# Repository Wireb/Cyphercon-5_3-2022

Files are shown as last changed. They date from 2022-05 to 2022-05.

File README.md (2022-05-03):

# Cyphercon 5.3 2022 
This repo is a collection of files related to the Cyphercon 5.3 badge and support hardware. 
Peacock board files and data pulled out to make the lifetime badges a bit harder to forge. 

## KiCad
This is a KiCad 5.x project. 

## MplabX
This is a mplabX 5.35 project. All programming / debug was done with a PicKit4.

## FreeCAD
These are FreeCAD 0.19 

## Inkscape
Version 1.0.1 used

## Documentation

- Cyphercon 2020.xlsx - Master document used for badge development. BOMs, communication, game mech, flash layout, animation documentation
- FreeCAD/Start button-2022  Cad files related to the conference start button
- FreeCAD/tymkrs_Cyphercon_2022 Cad files related to the badge and vending machine 
   - bottle_button_support.FCStd - support structure for IR button used in the snake oil button 
   - button_case.FCStd - support structure for IR button used in the bee and bird seed bags
   - coyote_final.FCStd - screen alignment tool
   - coyote_stencil.FCStd - flocking stencil and blocks
   - flamingo_final.FCStd - screen alignment tool
   - flamingo_flock_blocks.FCStd - alignment blocks for badge on stencil machine 
   - flamingo_pgm_fixture.FCStd - programing fixture for flamingo badges
   - flamingo_stencil_2_tone_a.FCStd - flocking stencil
   - flamingo_stencil_V2.FCStd - flocking stencil
   - llama_final.FCStd - screen alignment tool
   - llama_stencil.FCStd - flocking stencil and blocks
   - Outhouse_socket.FCStd - socket for holding badge in outhouse
   - parrot_final.FCStd - screen alignment tool
   - parrot_stencil.FCStd - flocking stencil and blocks
   - peacock_final.FCStd - screen alignment tool
   - port_a_potty.FCStd - port-a-potty IR button housing 
   - Starfish.FCStd - starfish stencil for back of all the badges
   - Vendo_bracket.FCStd - support bracket for replacement processor board in the vending machine
   - Vendo_socket.FCStd - socket for badge on front of the vending machine 
   - wash_holders.FCStd - holder for running PCBs though flux remover in the ultrasonic cleaner
- inkscape - Intermediate files used to build up the stencils from the silk screen layers
- kicad 
   - tymkrs_Cyphercon_2020_Coyote - Coyote badge files
   - tymkrs_Cyphercon_2020_flamingo - Flamingo badge files
   - tymkrs_Cyphercon_2020_IRbutton - IR button files 
   - tymkrs_Cyphercon_2020_IRhack - IR hack and start button board (note start button was highly modified and mostly just used as a PIC chip holder.)
   - tymkrs_Cyphercon_2020_Llama - Llama badge files
   - tymkrs_Cyphercon_2020_Parrot - Parrot badge files 
   - tymkrs_vendo - Vendo processor replacement board (note "vendo.???" files are my schematics from reverse engineering the vending machine board) 
- mplab
    - Tymkrs_Cyphercon2020_IRblaster - Firmware for con start button
    - Tymkrs_Cyphercon2020_IRhack - Firmware for IRhack board 
    - Tymkrs_Cyphercon_2020_badge - Firmware for badges (one build supports all. Function defined by ID range) 
    - Tymkrs_Cyphercon_2020_IRbutton - Firmware for IR buttons and outhouses (Note there is a #ifdef to set outhouse vs IR button mode) 
- perl
   - Animation_build_list - flamingo.txt - build list to go with build_animations.pl script to generate animation_flamingo.bin
   - Animation_build_list_CPL.txt - build list to go with build_animations.pl script to generate animation_CPL.bin
   - Animation_build_list_peacock.txt - build list to go with animation_peacock.pl script to generate animation_flamingo.bin
   - animation_CPL.bin - output animation data file that should be written to the SPI eeprom on the badge for coyote, parrot, and llama
   - animation_flamingo.bin - output animation data file that should be written to the SPI eeprom on the badge
   - animation_peacock.bin - output animation data file that should be written to the SPI eeprom on the badge
   - build_animations.pl - this script takes in the animation frames in PNG format per the animation_build_list and generates the binary files to be written to the - eeprom
   - CPL_eyes - file folder of png files for coyote, parrot, and llama
   - cyphercon2020-pgm.pl - programing script for the PIC generate random key for crypto and takes user input for badge ID (badge type is determined by ID range. See documentation)
   - cyphercon2022.db - database dump from the vending machine 
   - Cyphercon_2020_test.pl - test utility to be use with a IR hack to gest the various badge communication functions
   - F_eyes - file folder of png files for flamingos
   - hbdh.png - Happy birthday Hyr0n (was going to be on his birthday in 2020... Happy belated bday Hyr0n) 
   - metroid.png - PNG used in base firmware to test the LCD when the SPI eeprom is not programed
   - P_eyes - file folder of png files for peacocks
   - Tymkrs_Cyphercon_2020_badge.X.production.hex - final released firmware (should be the same as the copy in the mplab directory... I hope) 
   - Tymkrs_Cyphercon_2020_keys.txt - Master list of keys used in the vending machine. Use the last one in the file when duplicates badge IDs are found. 
   - Vending_data.xlsx - Decoded dump in excel with some post processing to get some stats
   - Vendo_decode.pl - used to export the vending machine database to CSV files
   - Vendo_server.pl - Vending machine server script that did all the vending machine functions other that the monitor display
   - Vendo_test.pl - test script for the vending machine controller board

Copyright (c) 2019 - 2022 Peter Shabino

Permission is hereby granted, free of charge, to any person obtaining a copy of this hardware, software, and associated documentation files 
(the "Product"), to deal in the Product without restriction, including without limitation the rights to use, copy, modify, merge, publish, 
distribute, sublicense, and/or sell copies of the Product, and to permit persons to whom the Product is furnished to do so, subject to the 
following conditions:

The above copyright notice and this permission notice shall be included in all copies or substantial portions of the Product.

THE PRODUCT IS PROVIDED "AS IS", WITHOUT WARRANTY OF ANY KIND, EXPRESS OR IMPLIED, INCLUDING BUT NOT LIMITED TO THE WARRANTIES OF 
MERCHANTABILITY, FITNESS FOR A PARTICULAR PURPOSE AND NONINFRINGEMENT. IN NO EVENT SHALL THE AUTHORS OR COPYRIGHT HOLDERS BE LIABLE 
FOR ANY CLAIM, DAMAGES OR OTHER LIABILITY, WHETHER IN AN ACTION OF CONTRACT, TORT OR OTHERWISE, ARISING FROM, OUT OF OR IN CONNECTION 
WITH THE PRODUCT OR THE USE OR OTHER DEALINGS IN THE PRODUCT.

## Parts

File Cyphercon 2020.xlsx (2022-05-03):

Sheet: Whixr coms
 | Baud rate | 115200 8N1 |  | 0x0A | on end
Thing | Starting byte | Length | Ending byte | description
Header | 0 | 5 | 4 | Fixed header string "Disp:"
Plugged | 5 | 1 | 5 | 0x01 = plugged in and data valid, 0x00 = unplugged and following data will all be 0x00
Status | 6 | 1 | 6 | bit 0 = 1 con is started, bit 1 = 1 badge is sick (rest unused)
Command type | 7 | 1 | 7 | Will always be 0x02
Badge ID | 8 | 2 | 9 | ID of this badge <0x200 standard badge <0x240 speaker <0x280 Founder <0x2A0 Vendor <0x2C0 Outhouse (should not see this) <0x2E0 Snake oil (should not see this) <0x2FE Necrollamacon (should not see this) ==0x2FE start button (should not see this) ==0x2FF Vendo (should not see this)
Flags | 10 | 1 | 10 | bit 0 = 1 con start, bit 1 = 1 has pink eye, bit 2 = 1 is cured, bit 3 = 1 has egg, bit 4 1 = quest start, bit 5 1 = quest done, bit 6 = 1 uber on, bit 7 = 1 dead
Spent | 11 | 2 | 12 | number of credits already spent by the badge
Sick ID | 13 | 2 | 14 | ID of badge that got this badge sick (verify sick bit is on before use)
Egg ID | 15 | 2 | 16 | ID of badge that knocked this one up (verify badge is pregenet before use)
Button clicks | 17 | 3 | 19 | How may times they clicked the button
Sleep sec | 20 | 3 | 22 | How long this badge has been in the sleep state total
Active sec | 23 | 3 | 25 | How long this badge has been in the active state total
Hyper sec | 26 | 3 | 28 | How long this badge has been in the hyper state total
Prego sec | 29 | 3 | 31 | How long this badge has been pregenet total
Died | 32 | 2 | 33 | How many times this badge has died
Got food | 34 | 2 | 35 | How many times this badge has picked up food
Pooped | 36 | 2 | 37 | How many times this badge has pooped
Knocked up | 38 | 2 | 39 | How many times this badge has been knocked up
Quest ID | 40 | 2 | 41 | ID of llama badge that gave them the quest item
Interactions | 42 | 96 | 137 | Each bit repersents one badge ID. Bit is set when the badge recieves a flag from that badge. Raw credits are equal to the total number of 1s
Food level | 138 | 1 | 138 | Current food level of badge
Poop level | 139 | 1 | 139 | Current poop level of badge
Internal status | 140 | 2 | 141 | Low byte lower 2 bits are the current badge mode 0 = dead or precon (use dead bit in flag byte (10) over this one), 1 = sleeping, 2 = active, 3 = hyper. bit 3 = egg led, bit 4 = stomic led, Upper byte bit 2 = poop led. Rest of the bits are internal status bits
once | 142 | 2 | 143 | Used for crypto
footer | 144 | 1 | 144 | fixed to 0x0A
Back to vendo
Header | 0 | 6 | 5 | Fixed header "Vendo:"
Data | 6 | 1 | 6 | Set value to 0x01 to drop egg from current badge, Set value to 0x02 to send quest start to badge (make sure the badge is dead quest does not work on a living badge)
footer | 7 | 1 | 7 | fixed to 0x0A

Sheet: TODO list
 |  | Weeks left till Cyphercon | -3 |  | when | 2022-04-11 | days | -21
 |  |  |  |  | 16
item # | priority | What | Owner |  | requried time (weeks) | blocked by | actual start | actual end | notes / comments
3 | must | pack badges | Atdiy |  | In Progress
8 | must | play test and verify timers and animations | Atdiy
9 | must | Vendo GUI / Game | Whixr |  |  | 10
12a | Punt | Controls | Whixr
13 | Punt | LED controller for vendo | Wire
 | must | Solering iron and tools | Atdiy
4a | Done | Bird seed bag | Wire |  | 0 |  |  |  | build 5 | Bird seed bag
4e | Done | necrollamacon buttons | Wire |  | 0 |  |  |  | build 5 | Just needs the top lable on one box then done
5 | Done | Start IR blaster | Wire |  | 4
4f | Done | Beeeees!!! | Wire |  | 0 |  |  |  | build 5 | Bees
4c | Done | port-a-potty | Wire |  | 0 |  |  |  | build 5 | port-a-potty
16 | Done | Hack IR | Wire
17 | Done | Hack IR can stickers | Atdiy | 1 | DONE
21 | Done | Necrollamacon sticker | Atdiy | 1 | DONE |  |  |  | Need 1 more outline already done and will return with boxes
20 | Done | Bee boxes / stickers | Atdiy | 1 | DONE |  |  |  | Need 5
4b | Done | outhouse | Wire |  | 0 |  |  |  | build 5 | outhouse
1 | Done | Program badges | Wire |  | 6 | 8
2 | Done | validate in sleep | Wire |  | 1 | 1
4 | Done | setup buttons | Wire |  | 4
4d | Done | snake oil buttons | Wire |  | 0 |  |  |  | build 5 | snake oil buttons
7 | Done | Eye animations | Atdiy | 1 |  |  |  |  | Need image frames in .png format (see sample) and duration in to display each frame in 0.05s increments. (you can have the first 10 frams play ever 0.1s then have one frame stay up for 1s then 4 frames at 0.25s if you like
7a | Done | Precon idle | Atdiy | 1 |  |  |  |  | same as sleep
7b | Done | Precon button pressed | Atdiy | 1 |  |  |  |  | lazy eye back to sleep
7c | Done | hyper | Atdiy | 1
7d | Done | hyper sick | Atdiy | 1
7e | Done | normal | Atdiy | 1
7f | Done | normal sick | Atdiy | 1
7g | Done | sleep | Atdiy | 1 |  |  |  |  | sleep
7h | Done | sleep sick | Atdiy | 1
7i | Done | dead | Atdiy | 1
7j | Done | dead sick | Atdiy | 1
7k | Done | normal eye beam | Atdiy | 1 |  |  |  |  | When they click their button to send a flag
7l | Done | sick eye beam | Atdiy | 1
7m | Done | mine? | Atdiy | 1 |  |  |  |  | triggers on getting food or special packet
7n | Done | HBDH | Wire |  | 1
14 | Done | Test badge LEDs again | Atdiy | 1 |  | 2
18 | Done | Vending machine price sheet (see tab) | Atdiy | 1
19 | Done | Vending machine shelf tags | Atdiy | 1 |  |  |  |  | The little lables in front of each row with the number to punch in to dispence them. Note limited to digits on keypad minus the down arrow which will be used for dispense.
23 | Done | Test fit all items in vendo | Atdiy | 1 | DONE
10 | Done | split up vendo work and define interface | Whixr / Wire | 1
12 | Done | Vendo vinyl art | Whixr | 1 | DONE
12a | Done | Left side | Whixr | 1 | DONE
12a | Done | Right side | Whixr | 1 | DONE
12a | Done | Front side | Whixr | 1 | DONE
11 | Done | Vendo interface layer | Wire |  |  | 10
15 | Done | badge video | Atdiy / Whixr | 1 | In Progress
22 | Done | Demo video | Atdiy / Whixr | 1
24 | Done | Pack all vendo items into boxes | Atdiy | 1
 | Done | Badge repair parts packed | Atdiy | 1
6 | Done | start podium / suitcase | Wire
 | Done | Fix last bad badge | Wire
 | Done | Free box | Wire

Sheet: shopping list
badge |  | Vendo badge insert difference
Good Parrot | 21.5 | fits just perfect
coyote | 22.7 | 1.2
llama | 22.2 | 0.7
flamingo | 22.14 | 0.64
llama | 22.16 | 0.66
coyote | 22.25 | 0.75
flamingo | 22.15 | 0.65
flamingo | 21.98 | 0.48
parrot | 22.35 | 0.85
coyote | 22.41 | 0.91
llama | 22.2 | 0.7
coyote | 22.2 | 0.7
parrot | 22.26 | 0.76
flamingo | 22.05 | 0.55
llama | 22.16 | 0.66
flamingo | 22.52 | 1.02
 | average | 0.75
 | max | 1.2

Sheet: Vending price sheet
Item | Dispense code | Row wire color | Column wire color | Cost |  |  |  |  | 1 | 2 | 3 | 4 | 5 | 6 | 7 | 8 | 9
Red badge | 1337 |  |  | 65536 | NOTE!!!! |  |  |  | Books | Flamingo Straws | Stuffed Animals | Ambrosia
 |  |  |  |  | byte 0 row select (value NOT bit) |  |  | 1 | 50 | 10 | 50 | 65537
 |  |  |  |  |  | 0 | yellow wire row |  | 3 - 42 | 22 - 007 | 32 - 7446
 |  |  |  |  |  | 1 | white wire row |  | Lasered WI | Red Badge | Donated Badges | Donated Badges | Donated Badges
 |  |  |  |  |  | 2 | orange wire row | 2 | 10 | 65536 | 75 | 75 | 75
 |  |  |  |  |  | 3 | green wire row |  | 9 - 53203 | 33 - 1337 | 25 - 5912535152535 | 6 - 3119362364 | 1 - 998001
 |  |  |  |  |  | 4 | red wire row |  | SAO | Lasered WI | Kazoo | Games | Defcon PCBs | Game Bees | Rand Electronics
 |  |  |  |  |  | 5 | pink wire row | 3 | 50 | 10 | 10 | 20 | 75 | 100 | 30
 |  |  |  |  |  | 6 | brown wire row |  | 23 - AE35 | 8 - CHEE5E | 15 - CHE55 | 13 - 44556767103 | 2- ED209 | 12 - BEE5 | 5 - 5558632
 |  |  |  |  |  | 7 | black wire row |  | The Cure | Bird Seed | IR Hack | Kazoo | IR Hack | Kazoo | Rubber Duckies | Balls | PCB Bits
 |  |  |  |  |  |  |  | 4 | 100 | 100 | 75 | 10 | 75 | 10 | 30 | 50 | 25
 |  |  |  |  | byte 1 column select (value NOT bit) |  |  |  | 11 - 8675309 | 14 - DEAD BEEF | 20 - C2 | 19 - 9 | 16 - 127001 | 18 - 1 | 27 - 4152739164 | 31 - 101 | 17 - 3125550690
 |  |  |  |  |  | 0 | red wire column |  | Challenge coins | Scissors | Scissors | Kazoo | Phone Badges | Kazoo | Toilet | Scissors | Necrollamacon
 |  |  |  |  |  | 1 | gray wire column | 5 | 75 | 30 | 30 | 10 | 75 | 10 | 100 | 30 | 200
 |  |  |  |  |  | 2 | green wire column |  | 4 - 2125554240 | 29 - 2375345200 | 10 - 2 | 7- 5663 | 21-2600 | 28 - 80 | 26-75 | 24 - 6387 | 30 - 47688283
 |  |  |  |  |  | 3 | orange wire column
 |  |  |  |  |  | 4 | pink wire column |  |  | Questions: |  |  |  |  | Answer: | cost: | Row | column |  |  | https://cybersecurityventures.com/movies-about-cybersecurity-and-hacking/
 |  |  |  |  |  | 5 | yellow wire column |  | 1 | 1 divided by _____ gives all 3 digit numbers from 000 to 999 except for 998? |  |  |  |  | 998001 | 75 | 2 | 5 | 1 | 4
 |  |  |  |  |  | 6 | brown wire column |  | 2 | Think you better do what he says Mr. Kinney |  |  |  |  | ED209 | 75 | 3 | 5 | 2 | 4
 |  |  |  |  |  | 7 | white wire column |  | 3 | What's the meaning of life? |  |  |  |  | 42 | 50 | 1 | 1 | 0 | 0
 |  |  |  |  |  | 8 | blue wire column |  | 4 | CrashOverride: Hey Norm, can you read the number on the modem? |  |  |  |  | 2125554240 | 75 | 5 | 1 | 4 | 0
 |  |  |  |  |  | 9 | black wire column |  | 5 | What's the number for Protovision? |  |  |  |  | 5558632 | 30 | 3 | 7 | 2 | 6
 |  |  |  |  |  |  |  |  | 6 | # to WOPR (w/area code) |  |  |  |  | 3119362364 | 75 | 2 | 4 | 1 | 3
 |  |  |  |  | Notes on credits: |  |  |  | 7 | Calculator speak for EGGS |  |  |  |  | 5663 | 10 | 5 | 4 | 4 | 3
 |  |  |  |  |  | All badges start with 1 credit for seeing themselves. |  |  | 8 | What's yellow and Wisconsin-y |  |  |  |  | CHEE5E | 10 | 3 | 2 | 2 | 1
 |  |  |  |  |  | Natural max (badges we built) = 592 (verify with atdiy and final count) |  |  | 9 | What zip code are we in |  |  |  |  | 53203 | 10 | 2 | 1 | 1 | 0
 |  |  |  |  |  |  |  |  | 10 | Birds of a feather flock _gether |  |  |  |  | 2 | 30 | 5 | 3 | 4 | 2
 |  |  |  |  |  | Max credits if badges are spoofed (easy hack) = 768 |  |  | 11 | Jenny's Number |  |  |  |  | 8675309 | 100 | 4 | 1 | 3 | 0
 |  |  |  |  |  | Max credits if credit handshake (crypto) is broken (hard hack red badge?) = 65536 (0xFFFF) |  |  | 12 | What are these? |  |  |  |  | BEE5 | 100 | 3 | 6 | 2 | 5
 |  |  |  |  |  |  |  |  | 13 | Konami Code |  |  |  |  | 44556767103 | 20 | 3 | 4 | 2 | 3
 |  |  |  |  |  |  |  |  | 14 | FEED B0B0 ____ ____ |  |  |  |  | DEAD BEEF | 100 | 4 | 2 | 3 | 1
 |  |  |  |  |  |  |  |  | 15 | Would you like to play a game of ______ |  |  |  |  | CHE55 | 10 | 3 | 3 | 2 | 2
 |  |  |  |  |  |  |  |  | 16 | What IP should you hack to shut down your computer? |  |  |  |  | 127001 | 75 | 4 | 5 | 3 | 4
 |  |  |  |  |  |  |  |  | 17 | What number does Trinity call from? |  |  |  |  | 3125550690 | 25 | 4 | 9 | 3 | 8
 |  |  |  |  |  |  |  |  | 18 | 6 ÷ 2(1+2) |  |  |  |  | 1 | 10 | 4 | 6 | 3 | 5
 |  |  |  |  |  |  |  |  | 19 | 6 ÷ 2(1+2) |  |  |  |  | 9 | 10 | 4 | 4 | 3 | 3
 |  |  |  |  |  |  |  |  | 20 | Control and Command |  |  |  |  | C2 | 75 | 4 | 3 | 3 | 2 | https://www.youtube.com/watch?v=6BqpU4V0Ypk
 |  |  |  |  |  |  |  |  | 21 | The audio tone used in phreaking |  |  |  |  | 2600 | 75 | 5 | 5 | 4 | 4
 |  |  |  |  |  |  |  |  | 22 | Who likes it shaken, not stirred |  |  |  |  | 007 | 10 | 1 | 2 | 0 | 1
 |  |  |  |  |  |  |  |  | 23 | What unit did HAL9000 lie about and say was malfunctioning |  |  |  |  | AE35 | 50 | 3 | 1 | 2 | 0
 |  |  |  |  |  |  |  |  | 24 | Colossus detonated missiles at which silos? |  |  |  |  | 6387 | 30 | 5 | 8 | 4 | 7 | https://tvtropes.org/pmwiki/pmwiki.php/Quotes/ColossusTheForbinProject
 |  |  |  |  |  |  |  |  | 25 | What number did Bob's twinkie hit to get into Terminal Entry |  |  |  |  | 5912535152535 | 75 | 2 | 3 | 1 | 2
 |  |  |  |  |  |  |  |  | 26 | Clifford Stoll discovered a how many cent discrepancy which tipped him off? |  |  |  |  | 75 | 100 | 5 | 7 | 4 | 6
 |  |  |  |  |  |  |  |  | 27 | What's NSA Agent Mary's number? |  |  |  |  | 4152739164 | 30 | 4 | 7 | 3 | 6 | https://en.wikiquote.org/wiki/Sneakers_(1992_film)
 |  |  |  |  |  |  |  |  | 28 | How many gigs of data can Johnny Mnemonic carry in his head? |  |  |  |  | 80 | 10 | 5 | 6 | 4 | 5
 |  |  |  |  |  |  |  |  | 29 | What's Jeff Gregg's IP address |  |  |  |  | 2375345200 | 30 | 5 | 2 | 4 | 1 | https://www.youtube.com/watch?v=46qKHq7REI4
 |  |  |  |  |  |  |  |  | 30 | What's the file number for Undersecretary of Defense - Michael Bergstrom |  |  |  |  | 47688283 | 200 | 5 | 9 | 4 | 8
 |  |  |  |  |  |  |  |  | 31 | What is Neo's apt number? |  |  |  |  | 101 | 50 | 4 | 8 | 3 | 7
 |  |  |  |  |  |  |  |  | 32 | How many rivers and streams does Wisconsin have? |  |  |  |  | 7446 | 50 | 1 | 3 | 0 | 2
 |  |  |  |  |  |  |  |  | 33 | Guess |  |  |  |  | 1337 | 65536 | 2 | 2 | 1 | 1
 |  |  |  |  |  |  |  |  | 34 | flamingo |  |  |  |  | A310D8D410
 |  |  |  |  |  |  |  |  | 35 | coyote |  |  |  |  | U4A102BC10E
 |  |  |  |  |  |  |  |  | 36 | llama |  |  |  |  | A473D10D1C
 |  |  |  |  |  |  |  |  | 37 | Parrot |  |  |  |  | 1086710A20U
 |  |  |  |  |  |  |  |  | 38 | Peacock |  |  |  |  | 101234CDEF

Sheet: Awards
Name | What
Kenny | most deaths
Fidget spinner | most button presses while not dead

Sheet: Rework status
Badge | Total need | in process | good | bad | missing | Fallout % | % have | % done | Cleaned | % done | Short
Parrot | 45 | 0 | 46 | 0 | 0 | 0.0% | 102.2% | 102.2% | 0 | 0.0% | 0
Llamma | 20 | 0 | 21 | 0 | 0 | 0.0% | 105.0% | 105.0% | 0 | 0.0% | 0
Peacock | 10 | 0 | 11 | 0 | 0 | 0.0% | 110.0% | 110.0% | 0 | 0.0% | 0
coyote | 15 | 0 | 16 | 0 | 0 | 0.0% | 106.7% | 106.7% | 0 | 0.0% | 0 |  |  |  |  | 462 | 11 | 21 | 46 | 16
Flamingo | 460 | 0 | 462 | 0 | 0 | 0.0% | 100.4% | 100.4% | 0 | 0.0% | 0 |  |  |  |  | F | pea | l | par | c
 |  |  |  |  |  |  |  |  |  |  |  |  |  | 7.75 | long | 7.75 | 7.75 | 7.75 | 7.75 | 7.75
Total | 550 | 0 | 556 | 0 | 0 | 0.0% | 101.1% | 101.1% | 0 | 0.0% |  |  |  | 3.5 | wide | 3.25 | 4 | 3.25 | 3.5 | 3.5
 |  |  |  |  |  |  |  |  |  |  |  |  |  | 1.25 | tall for 2
 |  |  |  |  |  |  |  |  |  |  |  |  |  |  |  |  | total storage | overage | ends
2022-05-02 | 2022-04-01 | -31 | -4.428571429 | weeks left |  |  |  |  |  |  |  |  |  | 14.75 | L | 1 | 7.75 | 7 | 3.5
 |  |  |  |  |  |  |  |  | 0 | -160 |  |  |  | 9.25 | W | 2 | 7 | 2.25 | 1.125
 |  |  |  |  |  |  |  |  | 40 |  |  |  |  | 6 | T | 8
Process steps |  |  |  |  |  |  |  |  | 451 |  |  |  |  |  |  | 16
1 | assembly -LCD |  |  | 101.1% |  |  |  |  | 450
2 | LED drv |  |  | 101.1% |  | Total |  | Flamingo 2 | Flamingo | Parrot | Llamma | Peacock | coyote | 9.25 | L | 1 | 7.75 | 1.5 | 0.75
3 | LED test |  |  | 101.1% |  | 556 | 135 | 135 | 192 | 46 | 21 | 11 | 16 | 14.75 | W | 4 | 14 | 0.75 | 0.375
4 | clean |  |  | 101.1% |  | 556 | 200 | 262 |  | 46 | 21 | 11 | 16 | 6 | T | 8
5 | flock |  |  | 101.1% |  | 556 |  | 51 | 411 | 46 | 21 | 11 | 16 |  |  | 32
6 | LCD assembly+test |  |  | 101.1% |  | 556 |  | 51 | 411 | 46 | 21 | 11 | 16
7 | lower LEDS |  |  | 101.1% |  | 556 |  | 51 | 411 | 46 | 21 | 11 | 16
8 | Battery holders |  |  | 100.0% |  | 550 |  | 50 | 410 | 45 | 20 | 10 | 15
9 | Final programing |  |  | 0.0% |  | 0 |  |  |  |  |  |  |  |  |  | 478 | 16
10 | Test IR and verify in deep sleep and pack |  |  | 0.0% |  | 0 |  |  |  |  |  |  |  | Box | badge | how many
 |  |  |  | 80.8% | Overall completion |  |  |  |  |  |  |  |  | 1 | Flamingo | 70 | 17.5 | 9.75 | 8.75
 |  |  |  |  |  |  |  |  |  |  |  |  |  | 2 | Flamingo | 96 | 18.75 | 12.5 | 11
 |  |  |  |  |  |  |  |  |  |  |  |  |  | 3 | Flamingo | 160 | 20.5 | 13 | 12.75
 |  |  |  |  |  |  |  |  |  |  |  |  |  | 4 | Flamingo | 72 | 18 | 10 | 8.5
 |  |  |  |  |  |  |  |  |  |  |  |  |  | 5 | Flamingo | 80 | 14 | 13 | 12.75
 | Shopping list: |  |  |  |  |  |  |  |  |  |  |  |  | 6 | Llama | 21 | 11.75 | 9.25 | 6
 |  |  |  |  |  |  |  |  |  |  |  |  |  | 7 | Peacock | 11 | 11 | 6.25 | 8.25
10 | pogo pins |  |  |  |  |  |  |  |  |  |  |  |  | 8 | Coyote | 16 | 14.75 | 9.25 | 4
 |  |  |  |  |  |  |  |  |  |  |  |  |  | 9 | Parrot | 46 | 15.75 | 11.75 | 5
 |  |  |  |  |  |  |  |  |  |  |  |  |  |  |  |  |  |  |  |  | pass 1 | pass 2 | pass 3 | pass 4
 |  |  |  |  |  |  |  |  |  |  |  |  |  |  | Flamingo | 2 | 411 | 822 |  | 822 | 411 | 411 | 0 | 0
 |  |  |  |  |  |  |  |  |  |  |  |  |  |  | Flamingo 2 | 3 | 51 | 153 |  | 153 | 51 | 51 | 51 | 0
 |  |  |  |  |  |  |  |  |  |  |  |  |  |  | Llama | 3 | 21 | 63 |  | 63 | 21 | 21 | 21 | 0
 |  |  |  |  |  |  |  |  |  |  |  |  |  |  | Peacock | 4 | 11 | 44 |  | 44 | 11 | 11 | 11 | 11
 |  |  |  |  |  |  |  |  |  |  |  |  |  |  | coyote | 2 | 16 | 32 |  | 32 | 16 | 16 | 0 | 0
 |  |  |  |  |  |  |  |  |  |  |  |  |  |  | Parrot | 3 | 46 | 138 |  | 138 | 46 | 46 | 46 | 0
 |  |  |  |  |  |  |  |  |  |  |  |  |  |  |  |  | 556 | 1252 |  | 1252

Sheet: Ideas
arts n crafts
Fuzzy Flocking
Stickers
Piper cleaners
Paper doll parts
Electronics
Pink Leds (see Kupo!)
Led array eye
Led wing outline
screen / led array for crafting
Puzzle / game
General Idea
 | tamagotchi
 |  | Drive trafic to villages and vendors
 |  | More details to com
 | Start podium
 |  | Badges do something lame (blinking led for a eye) until started.
 |  | Start podium has blinky lights and things and a giant button.
 |  | When button is pressed leds go crazzy and sends out IR becon via IR floodlight to all badges in the room to start.
 |  | Badges go into normal mode and can spread the start signal to other badges.
Village boxes
 | Each village box gives a limited number of usefull (maybe) items
 | Each village has a box that generates a unique resouce on a given tick (~5s)
 | Display on box shows how many resouces in stock and has a max cap of 5?
 | User can insert badge and press button to collect one resource per press if badge cap is not full. (bidi coms)
Vendor boxes (backup for vendor overload)
 | Each vendor has a box that generates a food resouce on a given tick (~5s)
 | Display on box shows how many resouces in stock and has a max cap of 5?
 | User can insert badge and press button to collect one resource per press if badge cap is not full. (bidi coms)
Vendor badges
 | Similar to the boxes gives food resouces to those near by.
 | No tick limit
 | Badge remberst the last X badges it got food from and will not accept handouts from them anymore
Guild hall
 | The main purpose of this box is to collect the interaction data and scores of each badge.
 | Also allows the badge user to update their handle in the scoring system (vs snarky autogenerated name based off ID)
 | Badge upgrades and stat display
 | Doctor game
Badge
 | Interact button to send greatings to other badges (give social) and interact with boxes
 | Eye / mouth animations. Main method to inform the user of the status of their bird.
 | Wing leds show rank / health (streach)
80s hacker movies
chamber from the fly
Shaw of the dead
hackers vs deadites
80s movie tropes
Michael Jackson thriller
hyron's bday
where's kevin
laser tag wands
Bees - turkey baster |  | Enroute | 5 |  | 12 bees | in house
Portapotty - Normal |  | Will make | 5 |  | Popsicle sticks | in house
Portapotty - Vending |  | Will make | 5
Seed bag |  | Will make - burlap enroute | 5 |  |  | in house
Miracle Oil |  |  | 5 |  | tins | in house
IR Hack |  |  | 12 | https://www.amazon.com/Stocking-Stuffers-Chocolate-Valentines-Anniversary/dp/B07BJWC3VX | tins | not sure if i can make 21 but made 7 labels | in house
 |  |  |  |  | Elecrow | OSH Park | TRC Circuits | Royal Circuits | AAPCB
 |  |  | Flamingo | 475 | 980.98 | 8356 | 2997 | 7990 | 5992
 |  |  | Parrot | 45 | 188.42 | 792 | 795 | 1299 | 1284
 |  |  | Llama | 25 | 127.08 | 246 | 525 | 1799 | 1270
 |  |  | Coyote | 15 | 73.59 | 436 | 550 | 1299 | 872
 |  |  | Peacock | 15 | 61.77 | 246 | 500 | 1299 | 913
 |  |  |  |  | 1431.84 | 10076 | 5367 | 13686 | 10331
 |  |  |  | 575 |  | 4717
 |  |  |  |  |  | 300
 |  |  |  |  |  | 1720

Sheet: Art
Badge | Animal | Art direction
Human | Flamingo Pink | Hackery / paper dress up doll
Uber | Flamingo Purple? Two tone? | Hackery / paper dress up doll | Purple | (VIP buys before Nov1 and Vendors) - hard to determine badge counts for vendors...can we add a SAO of some sort?
Founder | Llama / wolf in Llama cloathing | Keeper of the Necrollamacon (brings back the dead) | Black
Vendor | Coyote | Gives out free bird seed.
Speaker | Parrot | Umm talking social pariot
Red | Peacock | Extra fancy and fragile (Real peacock feathers?)

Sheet: Requirements
Category | Item | Units | Ask
Logistics | QTY | #
Logistics | Assembly | in house/FAB
Logistics | Programing | in house/FAB
date | conferance date | date
date | final ship | date
date | assembly start | date
Communications | RF - WiFi | y/n | n
Communications | RF - Bluetooth | y/n | n
Communications | RF - Other | y/n | n
Communications | IRDA | y/n | n
Communications | IR - simple | y/n | Y
Communications | UART | y/n | n
Communications | I2C | y/n | Y
Communications | SPI | y/n | n
Communications | USB device | y/n | n
Communications | PSTN modem | y/n | n
Power | LiPo (?Ah @ ?mA) | y/n | n
Power | AA (2.4Ah @ 50mA) | # | 2
Power | AAA (1Ah @ 10mA) | # | n
Power | CR2450 (0.62Ah @ 0.39mA) | # | n
Power | Reg | y/n
Display | 7seg LED | # digits | 0
Display | oLED | y/n | n
Display | LCD | y/n | y
Display | ePaper | y/n | n
Display | RGB LEDs | # RGB leds | 0
Display | LEDs | # leds | 48 | min
Display | LED strip | y/n | n
Input devices | buttons | # | 2 or 3
Input devices | switches | # | 0
Input devices | cap sense | # | 1 | petting flamingo
Input devices | Microphone | y/n | n
Input devices | Rotarty encoder | # | 0
Input devices | Pulse | y/n | n
Input devices | jiggle | y/n | n
Input devices | tempature | y/n | n
Output devices | Speaker | y/n | n
Output devices | Buzzer | y/n | n
Processing | FPGA | y/n | n
Processing | PIC | y/n | y
Storage | eeprom I2C | bytes | 128kb (16kB)
Storage | SDcard | y/n | n

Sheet: Game mechanics
Stat counters
 | Too low | low value | Too high | high value | Decay mech | Decay tick rate |  | Effect in Flamingo
food | death | 0 | fat | 20 | time | 1/min |  | Stomach shows from full up to empty
sleep | forced sleep | 0 | hyper | 20 | time | 1/min |  | Eyes go from open and alert to sleepy, maybe zzz?
health | sick (local) | 0 | vegan
social | binge eater | 0 | patient zero | very large
booze | basement dweller |  | drunk, binge drinker |  | time |  | 2 counters time and total number?, tristate for drunk state
shit | prolapse |  | got2go |  |  | -1/min | Food rate feeds this counter
Status effects
 | how fixed | impact | description
death | Necrollamacon | Unable to interact / reset score? | You have died only way to exit this state is to retrieve a copy of the Necrollamacon from a founder (or hidden beacon?). Consumed on use. Possibly kill player if in inventory when not dead or affect social?
fat | time | Decrease health | You have been a pig and eaten too much. You feel slugish and not all that well.
forced sleep | time | Unable to interact no social, food, booze, shit | Your so tired you can't even open your eyes. (Real world xx minutes to reset. If power cycled during sleep timer resets to full delay cheat protect)
hyper | time | faster food decay | Your bouncing off the walls.
sick | station (game) + meds | lower social pickup | You feel like shit and want to be alone.
vegan | decrease health | process booze faster
binge eater | social | faster food decay + faster shits | You feel so alone and your only friend is the fridge.
patient zero | station (game) + meds | you spread concrud -health to all who see your beacon | Your so sick you can barely stand but you still want to see the talks. (Curing this also resets all your interactions...)
basement dweller |  | sleep rate up
binge drinker | none | death | Looks like you pickled yourself this time
prolapse |  | sleep recovery down
got2go |  | No social counts, override sleep | Your doing the pinguin walk and just hoping it does not roll down your pant leg.
drunk | time | Social to 50% and frozen | You no longer care and just want to party.
Zombies! | Zombie repelent / avoid the dead | health down? | Your scared so many undead.
Items
 | from
coffie | box / tips? | boosts sleep value
Chill room | Chill room | Freezes all in game counters and badge goes into chill mode for x minutes
booze | box / tips? | get's you drunk
bird seed | Vendors | adds to food level
Necrollamacon | founders | brings you back from the dead
Zombie repelent | boxes | immuen to zombie effects for x min
Meds | boxes | Cures sickness / concrud
Toilet | boxes? | poop down

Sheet: Game Mech V2
Stat | Min | Max |  | Normal Increase | Rate | Normal Decrease | Rate | At Min | At max | Min Effects | Max Effects
food | 0 | 255 - shit |  | Vendor | Fill to max | Time | 1/min | death | no effect | Can't Nothing so they can do everything? | Can't Eat
shit | 0 | 255 |  | Food decrease | 1 per food - | Toilet | empty | no effect | no effect |  | Can't Eat; Can't Social
heart rate | 0 | 255 |  | Meeting Others | 1/person | Time no pings | -1 per 5 min? | sleeps until next ping | no effect |  | Can't Eat; Can't Social
 | Eye Status | Heart Light (2 bit) | Stomach Light (1 bit) | Poo Light (1 bit) | Egg Light (1 bit)
food = 0 | XX |  | On |  | On if On

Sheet: Game Mech V3
Game counters
stat | value min | value max | increase function | inc amount | inc dead | decrease function | dec amount fixed | sleep | active | hyper | dec dead | LED effects | LED when / L0 | LED L1 | LED L2 | LED L3 | save in eeprom | save source | Init value | start conditon | back from dead | notes
Egg | 0 | 1 | speaker badge | 1 | no | Vending machine | 1 | N/A | N/A | N/A | yes | egg on | 1 | N/A | N/A | N/A | yes | yes | eeprom | 0 | last
food | 0 | 255 - poo | vendor / seed bag | set to 255 - poo | no | heart rate / pink eye | var | 0 / 0 |  |  | no | stomic blink | 51 | N/A | N/A | N/A | no | no |  | 255 | 255
poo | 0 | 255 | food consumed | 1 | no | outhouse | set to 0 | N/A | N/A | N/A | no | poo blink | 204 | N/A | N/A | N/A | no | no |  | 0 | 0
heart | 0 | 3 | button press | set to 3 | no | time | var | 0 |  |  | no | heart blink | off | slow blink | medium blink | fast blink | yes | no | dead or sleep | 1 | 1 (sleep)
pink eye | 0 | 1 | 50 social or sick flag | 1 | no | snake oil | 1 | N/A | N/A | N/A | no | animation update | N/A | N/A | N/A | N/A | yes | yes | eeprom | 0 | last | can only catch onec
Heart 3 to 1 | 15 | min |  | 45 |  | 40 | 0.1568627451 | 255 | 6.375 | 95.625 | 1.59375 |  | 8.5 | 5.333333333
Heart 3 to 2 | 5 | min | 4 | food per |  | 26.66666667 |  | 255 | 9.5625 | 47.8125 | 0.796875
Heart 2 to 1 | 10 | min | 1 | food per |  | 13.33333333 |  | 255 | 19.125 | 191.25
With Pink Eye
Heart 3 to 1 | 15 | min |  | 45 |  | 66.66666667 | 0.2614379085 | 255 | 3.825 | 57.375 | 0.95625
Heart 3 to 2 | 5 | min | 6 | food per |  | 40 |  | 255 | 6.375 | 31.875 | 0.53125
Heart 2 to 1 | 10 | min | 2 | food per |  | 26.66666667
 |  |  |  |  |  |  |  |  |  | hyper end
pink leds
state | animation | on at once | update speed
normal | lfsr | 1 | nominal
uber | lfsr | 1 | fast
change modes via command packet
 | Vending machine (complete quests)
 | IRHack
Logo LEDs
channel | slave together | Normal |  |  | On quest | Quest done
amber | y | triangle |  |  | off | off
red | y | triangle skipping some on way down |  |  | triangle in sync | off
green | y | triangle skipping some on way down |  |  | triangle in sync | pulse
blue | y | triangle skipping some on way down |  |  | triangle in sync | off
Badge exceptions
Vendor | inf food
Founder | inf food
Peacock | inf food
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

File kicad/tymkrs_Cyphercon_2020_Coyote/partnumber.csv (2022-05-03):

Q | part number | footprint | ref_des
1 | 0.1uF 16V X7R | Capacitor_SMD:C_0603_1608Metric | C9
1 | 0.1uF 6.3V X5R | Capacitor_SMD:C_0603_1608Metric | C8
4 | 0.1uF | Capacitor_SMD:C_0603_1608Metric | C13 C14 C16 C18
1 | 0.42_oLED_display | PJS_smt_parts:oLED_0.42_rev | oLED1
3 | 100k | Resistor_SMD:R_0603_1608Metric | R2 R6 R3
2 | 10k | Resistor_SMD:R_0603_1608Metric | R9 R8
3 | 10uF | Capacitor_SMD:C_1206_3216Metric | C12 C15 C17
1 | 1k | Resistor_SMD:R_0603_1608Metric | R4
2 | 1uF 16V | Capacitor_SMD:C_0805_2012Metric | C11 C10
1 | 2.2uF 16V 0805 | Capacitor_SMD:C_0805_2012Metric | C5
1 | 2.2uH 1.6A 0805 | Inductor_SMD:L_0805_2012Metric | L1
2 | 22uF 10V | Capacitor_SMD:C_0603_1608Metric | C3 C2
2 | 24.9K | Resistor_SMD:R_0603_1608Metric | R10 R11
1 | 25LCxxx | Package_SO:SOIC-8_5.275x5.275mm_P1.27mm | U3
1 | 27 (0805) | Resistor_SMD:R_0603_1608Metric | R7
3 | 4.7uF 16V 0805 | Capacitor_SMD:C_0805_2012Metric | C6 C7 C4
6 | Amber | SunLED:XZ__K45WT-9 | D5 D23 D39 D44 D57 D58
1 | Common LED guide | tymkrs:cypheron2020_common_logo_led_guide | icon3
1 | Common Logo copper | tymkrs:cypheron2020_common_logo_copper_add | icon5
1 | Common Logo keepout | tymkrs:cypheron2020_common_logo_copper_flood_keepout | icon4
1 | Common Logo soldermask | tymkrs:cypheron2020_common_logo_soldermask | icon2
1 | Cut lines | tymkrs:cypheron2020_coyote_cuts | icon6
1 | Eye location | tymkrs:cypheron2020_coyote_eye | icon11
1 | IR26-21C (1206) | LED_SMD:LED_1206_3216Metric | D2
2 | IS31FL3236_TQFP | Package_QFP:TQFP-48-1EP_7x7mm_P0.5mm_EP3.5x3.5mm | U5 U6
1 | Icon keepout | tymkrs:cypheron2020_coyote_icons_copperkeepout | icon7
1 | Icon soldermask | tymkrs:cypheron2020_coyote_icons_soldermask | icon8
1 | Keystone 2462 | PJS-pth-parts:Keystone_2462_2x_AA_no_holes | BT1
1 | LED guide | tymkrs:cypheron2020_coyote_led_guide | icon9
5 | LED_RABG | SunLED:XZMDKCBDDG45S-9 | D7 D12 D17 D28 D33
1 | Metroid | PJS-icons:metroid | icon1
1 | PIC16F15345 | Package_SO:SOIC-20W_7.5x12.8mm_P1.27mm | U1
1 | PicKit | Connector_PinHeader_2.54mm:PinHeader_1x05_P2.54mm_Vertical | J1
47 | Pink_0603 | LED_SMD:LED_0603_1608Metric | D4 D48 D50 D52 D53 D54 D55 D56 D10 D11 D13 D14 D15 D16 D18 D19 D20 D21 D22 D24 D25 D26 D27 D29 D30 D31 D32 D34 D35 D36 D37 D38 D40 D41 D42 D43 D45 D46 D47 D49 D51 D59 D60 D62 D63 D64 D61
3 | Red_rev | SunLED:XZ__K45WT-9 | D9 D8 D6
1 | SPI | Connector_PinHeader_2.54mm:PinHeader_1x06_P2.54mm_Vertical | J2
1 | Silk | tymkrs:cypheron2020_coyote_silk | icon10
1 | TACT_6MM | PJS_smt_parts:PTS645_6mm_tact_sw | SW1
1 | TPS61322x | Package_TO_SOT_SMD:SOT-23-5 | U2
1 | TSOP58438 | Vishay:TSOP48 | U4
1 | White IN-S63AT5UW | LED_SMD:LED_0603_1608Metric | D3
0 | no-pop | Diode_SMD:D_SMA | D1
0 | no_pop | Capacitor_SMD:C_0603_1608Metric | C1
0 | no_pop | Resistor_SMD:R_0603_1608Metric | R1 R5

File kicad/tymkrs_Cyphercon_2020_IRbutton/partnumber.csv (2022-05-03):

Q | part number | footprint | ref_des
1 | 0.1uF 0603 | Capacitor_SMD:C_0603_1608Metric | C2
1 | 100k | Resistor_SMD:R_0603_1608Metric | R1
1 | 10uF 1206 | Capacitor_SMD:C_1206_3216Metric | C1
1 | 27 0805 | Resistor_SMD:R_0603_1608Metric | R3
1 | 2k | Resistor_SMD:R_0603_1608Metric | R2
1 | BAT-HLD-001 | PJS_smt_parts:BAT-HLD-001 | BT1
1 | IR204 | LED_THT:LED_D3.0mm_Horizontal_O1.27mm_Z2.0mm_Clear | D2
1 | Metroid | PJS-icons:metroid | icon1
1 | MountingHole | MountingHole:MountingHole_2.7mm_M2.5 | H1
1 | PIC16F15313 | Package_SO:SOIC-8_3.9x4.9mm_P1.27mm | U1
1 | PicKit | Connector_PinHeader_2.54mm:PinHeader_1x05_P2.54mm_Vertical | J1
1 | Red | LED_SMD:LED_0603_1608Metric | D1
1 | TACT_6MM | PJS_smt_parts:PTS645_6mm_tact_sw | SW1

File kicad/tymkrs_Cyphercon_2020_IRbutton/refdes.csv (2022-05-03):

ref_des | part number | footprint
BT1 | BAT-HLD-001 | PJS_smt_parts:BAT-HLD-001
C1 | 10uF 1206 | Capacitor_SMD:C_1206_3216Metric
C2 | 0.1uF 0603 | Capacitor_SMD:C_0603_1608Metric
D1 | Red | LED_SMD:LED_0603_1608Metric
D2 | IR204 | LED_THT:LED_D3.0mm_Horizontal_O1.27mm_Z2.0mm_Clear
H1 | MountingHole | MountingHole:MountingHole_2.7mm_M2.5
J1 | PicKit | Connector_PinHeader_2.54mm:PinHeader_1x05_P2.54mm_Vertical
R1 | 100k | Resistor_SMD:R_0603_1608Metric
R2 | 2k | Resistor_SMD:R_0603_1608Metric
R3 | 27 0805 | Resistor_SMD:R_0603_1608Metric
SW1 | TACT_6MM | PJS_smt_parts:PTS645_6mm_tact_sw
U1 | PIC16F15313 | Package_SO:SOIC-8_3.9x4.9mm_P1.27mm
icon1 | Metroid | PJS-icons:metroid

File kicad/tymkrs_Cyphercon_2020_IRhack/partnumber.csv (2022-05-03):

Q | part number | footprint | ref_des
2 | 0.1uF 0603 | Capacitor_SMD:C_0603_1608Metric | C3 C4
1 | 100k | Resistor_SMD:R_0603_1608Metric | R5
1 | 10k | Resistor_SMD:R_0603_1608Metric | R1
2 | 10uF 1206 | Capacitor_SMD:C_1206_3216Metric | C1 C2
1 | 27 0805 | Resistor_SMD:R_0603_1608Metric | R4
2 | 2k | Resistor_SMD:R_0603_1608Metric | R2 R3
1 | Green | LED_SMD:LED_0603_1608Metric | D2
1 | IO | Connector_PinHeader_2.54mm:PinHeader_1x04_P2.54mm_Horizontal | J2
1 | IR204 | LED_THT:LED_D3.0mm_Horizontal_O1.27mm_Z2.0mm_Clear | D3
1 | Metroid | PJS-icons:metroid | icon1
1 | PIC16F15324 | Package_SO:SOIC-14_3.9x8.7mm_P1.27mm | U1
1 | PicKit | Connector_PinHeader_2.54mm:PinHeader_1x05_P2.54mm_Vertical | J1
1 | Red | LED_SMD:LED_0603_1608Metric | D1
1 | TSOP58438 | Vishay:TSOP48 | U2

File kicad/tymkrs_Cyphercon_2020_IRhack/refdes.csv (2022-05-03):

ref_des | part number | footprint
C1 | 10uF 1206 | Capacitor_SMD:C_1206_3216Metric
C2 | 10uF 1206 | Capacitor_SMD:C_1206_3216Metric
C3 | 0.1uF 0603 | Capacitor_SMD:C_0603_1608Metric
C4 | 0.1uF 0603 | Capacitor_SMD:C_0603_1608Metric
D1 | Red | LED_SMD:LED_0603_1608Metric
D2 | Green | LED_SMD:LED_0603_1608Metric
D3 | IR204 | LED_THT:LED_D3.0mm_Horizontal_O1.27mm_Z2.0mm_Clear
J1 | PicKit | Connector_PinHeader_2.54mm:PinHeader_1x05_P2.54mm_Vertical
J2 | IO | Connector_PinHeader_2.54mm:PinHeader_1x04_P2.54mm_Horizontal
R1 | 10k | Resistor_SMD:R_0603_1608Metric
R2 | 2k | Resistor_SMD:R_0603_1608Metric
R3 | 2k | Resistor_SMD:R_0603_1608Metric
R4 | 27 0805 | Resistor_SMD:R_0603_1608Metric
R5 | 100k | Resistor_SMD:R_0603_1608Metric
U1 | PIC16F15324 | Package_SO:SOIC-14_3.9x8.7mm_P1.27mm
U2 | TSOP58438 | Vishay:TSOP48
icon1 | Metroid | PJS-icons:metroid

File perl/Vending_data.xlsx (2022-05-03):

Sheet: badge_data
id | badge dec | active_time | active dec | ate | ate dec | clicks | clicks dec | credits | died | egg_from | flags | food | hyper_time | hyper dec | interaction_cnt | interactions | knocked_up | knocked up dec | poop | pooped | pooped dec | prego_time | prego dec | quest_id | sick_from | sleep_time | sleep dec | spent | state | status | flamingo_code | coyote_code | llama_code | Parrot_code | Peacock_code
0172 | 370 | 001155 | 4437 | 0004 | 4 | 00010C | 268 | 50 | 1 | 02FF | 37 | CF | 0016D4 | 5844 | 50 | 200000040000000010E00808000000104020000F050100002000008052004049000001000000000801001200000004028000000080004010100400000000000000000900000000000021080000000000400A0000000000001000000000000080 | 0001 | 1 | 28 | 0000 | 0 | 00F9A9 | 63913 | 024D | 0179 | 0111D6 | 70102 | 0000 | 0301 | 1 | 0 | 0 | 0 | 0 | 0
014E | 334 | 000EDF | 3807 | 0004 | 4 | 00006C | 108 | 2 | 2 | 02FF | 07 | E0 | 0018AC | 6316 | 52 | 0000021400002000000000000000000000000000000000000000222000000801082100880000100100700002400040204022800080004002001400000000000009A0400042000080C0C800000000000801280000010000001000000000000080 | 0004 | 4 | 11 | 0004 | 4 | 012A22 | 76322 | 0000 | 0200 | 01097C | 67964 | 0032 | 0301 | 1 | 0 | 0 | 0 | 0 | 0 |  | sick_from
0038 | 56 | 0012CF | 4815 | 0006 | 6 | 00002C | 44 | 23 | 0 | 02FF | 07 | 69 | 000FDB | 4059 | 23 | 0000800000000009080000000000000000000200000000000000080000000000000004000080000000200000000000004000000000000002000400000000000000A00000000000000001000000000000042900000200000002000000000000C0 | 0001 | 1 | 33 | 0002 | 2 | 00010F | 271 | 0000 | 0288 | 01097B | 67963 | 0000 | 0301 | 1 | 0 | 0 | 0 | 0 | 0 |  | 0179 | 6
0286 | 646 | 000C6D | 3181 | 0000 | 0 | 00002C | 44 | 19 | 0 | 0000 | 03 | 9F | 00099D | 2461 | 19 | 000000040000000000000000100040000000400000000000001000000000002000000000000000080020000000114400420000000000801000040000000000000000000000000000000000000000000040000000000000000000000000000080 | 0000 | 0 | 20 | 0000 | 0 | 000000 | 0 | 0000 | 01CA | 010928 | 67880 | 0000 | 0301 | 3 | 0 | 0 | 0 | 0 | 0 |  | 0200 | 3
01BC | 444 | 001374 | 4980 | 0037 | 55 | 0004D7 | 1239 | 46 | 1 | 02FF | 07 | CC | 0032EB | 13035 | 83 | 0004205410C000000C10020020004040000013100002020000500025000000010000C000002000084211130008014414C006004098000810000400000000000001A00001020000008419080000000008456B00880D00000010000000000000C0 | 0009 | 9 | 28 | 0005 | 5 | 011F25 | 73509 | 0000 | 0248 | 0100C4 | 65732 | 0025 | 0309 | 1 | 0 | 0 | 0 | 0 | 0 |  | 0288 | 13
024E | 590 | 0016F0 | 5872 | 0007 | 7 | 000049 | 73 | 26 | 0 | 0226 | 0B | 8D | 00160B | 5643 | 26 | 0044004000400000000000000800000000000000000000000000002100000001000040000000000900400000000040020000400080000800000400000000000000000000400000000441000000000000010800000000000000000000000000C0 | 0001 | 1 | FF | 0000 | 0 | 000218 | 536 | 0000 | 0248 | 00FE9B | 65179 | 0000 | 0601 | 3 | 0 | 0 | 0 | 0 | 0 |  | 01CA | 9
0141 | 321 | 0011E0 | 4576 | 000A | 10 | 0000FE | 254 | 42 | 2 | 0203 | 3B | A3 | 001923 | 6435 | 42 | 00044810000040000000000010004000000000000000000000004201000000000900000000000008021000104000000242040000A8108001000500000000000008A000082000000008A0000000000008004800000000000000000000000000C0 | 0004 | 4 | 1E | 0000 | 0 | 00DCE7 | 56551 | 024D | 0013 | 00E5F5 | 58869 | 0000 | 0503 | 3 | 0 | 0 | 0 | 0 | 0 |  | 0248 | 3
0244 | 580 | 002EAF | 11951 | 0459 | 1113 | 000080 | 128 | 61 | 0 | 0200 | 0F | FF | 0025E6 | 9702 | 61 | 00240A4208014082880400000000000000000000000000020080422000000000090084000420000902000000000180028210000060102004000400000000000001C800200A0000005E04000000000000002900000500000002000000000000C0 | 0002 | 2 | 00 | 0098 | 152 | 01385B | 79963 | 0000 | 0013 | 00E447 | 58439 | 0000 | 0509 | 1 | 0 | 0 | 0 | 0 | 0 |  | 0013 | 4
0203 | 515 | 000A68 | 2664 | 0000 | 0 | 000010 | 16 | 10 | 0 | 020D | 0B | 6D | 000772 | 1906 | 10 | 000000000000000004000000000000000000000000000002000000000000000008000000000000000240000000000000000000000000000800040000000000000820000000000000000000000000000000000000000000000000000000000080 | 0001 | 1 | 30 | 0000 | 0 | 000056 | 86 | 0000 | 0103 | 00D5DC | 54748 | 0000 | 0601 | 3 | 0 | 0 | 0 | 0 | 0 |  | 0103 | 1
028B | 651 | 0030D3 | 12499 | 0075 | 117 | 000179 | 377 | 35 | 0 | 02FF | 07 | A5 | 005926 | 22822 | 85 | 00C4821000C02008800400000000400000002210000022020190182000000800090100000200020802700700002084164244420090148016401400000000000001A000010000000084C1080000000008016B00080B0000000200000000000080 | 0002 | 2 | 2B | 0008 | 8 | 013ECC | 81612 | 0000 | 014C | 00CEF8 | 52984 | 0032 | 0303 | 1 | 0 | 0 | 0 | 0 | 0 |  | 014C | 5
01CA | 458 | 002618 | 9752 | 0055 | 85 | 0002EC | 748 | 21 | 2 | 0200 | 0F | D8 | 006FF4 | 28660 | 357 | FFFFFFFEFFFFFCFFFFFEFF3FFEFF7FFFFF93FF0000062202419808260400008B4973858862090F98D7740B60A139CE12E64FF7FFBFFFFF9FFBFFCFFFFFC70F0009E044A963080000ECD50A0000000008843B00001D00000002200000000000C0 | 000A | 10 | 0D | 000A | 10 | 015132 | 86322 | 0000 | 0023 | 00CB7D | 52093 | 0150 | 0601 | 1 | 0 | 0 | 0 | 0 | 0 |  | 0023 | 3
011B | 283 | 0008D3 | 2259 | 0000 | 0 | 000019 | 25 | 18 | 1 | 02FF | 37 | A9 | 00084A | 2122 | 18 | 000000000000000800000000000000000000000000000000000000000000080000010008000000400070010000000000400000000010000000040000000000000080000000000000800000000000002000000000020000000200000000000080 | 0001 | 1 | 08 | 0002 | 2 | 0029FD | 10749 | 0247 | 0150 | 00C8B2 | 51378 | 0000 | 0301 | 1 | 0 | 0 | 0 | 0 | 0 | 336 | 0150 | 21
01A4 | 420 | 001180 | 4480 | 000B | 11 | 00002C | 44 | 20 | 1 | 021B | 0F | B8 | 00116E | 4462 | 20 | 0000000000000000080000000000000000000000000000000000000000000000000004000020000800000000000100000000000090000002000000000000000001200008000000004000000000000000002A00000A00000002000000000000C0 | 0003 | 3 | 16 | 0012 | 18 | 00A980 | 43392 | 0000 | 012D | 00C170 | 49520 | 0000 | 0501 | 1 | 0 | 0 | 0 | 0 | 0 |  | 012D | 1
00F3 | 243 | 002915 | 10517 | 0049 | 73 | 00010A | 266 | 106 | 3 | 0221 | 0F | 64 | 002575 | 9589 | 226 | 00008810FE3FFFFF9FFFFF8FFFFFFFFFFFE7FFFFF3FFFFF3FFFFF9FFFFFC080008004008000000000040000001000002000400000810080B00000000000000000020000802000000C4B0080000000000010300000900000012000000000000C0 | 000A | 10 | 33 | 0136 | 310 | 00C572 | 50546 | 0000 | 018A | 00B6BF | 46783 | 0078 | 0509 | 1 | 0 | 0 | 0 | 0 | 0 |  | 018A | 6
0246 | 582 | 002069 | 8297 | 0031 | 49 | 000127 | 295 | 43 | 0 | 0205 | 0F | 9F | 002364 | 9060 | 43 | 00000000084000008C00000000000000000022000000000200800000000008000920000000200000004000000001000042000000B000880C400400000000000021A00008000000005400000000000028000300000400000002000000000000C0 | 0004 | 4 | 20 | 0007 | 7 | 00BCE9 | 48361 | 0000 | 020F | 00B21A | 45594 | 0000 | 0709 | 1 | 0 | 0 | 0 | 0 | 0 |  | 020F | 8
01A3 | 419 | 001E7D | 7805 | 0011 | 17 | 00002A | 42 | 34 | 0 | 0218 | 0F | 9F | 001498 | 5272 | 34 | 0000021000800001080000000800400000001200000002000000400000000C00000100000000000802000000000100000000004088000012000400000000000000A00009000000000000080000000000000300000000000012000000000000C0 | 0005 | 5 | 5F | 0000 | 0 | 00357B | 13691 | 0000 | 0289 | 00940D | 37901 | 0000 | 0D01 | 1 | 0 | 0 | 0 | 0 | 0 |  | 0289 | 2
0019 | 25 | 003001 | 12289 | 001C | 28 | 000119 | 281 | 48 | 0 | 0221 | 0F | FF | 00222E | 8750 | 73 | 00020012080000000800000000000040E0FF73F83D002000000842050000000000004000200008080010010040000014420A00008010880E000400000000000000A0011802000000100000000000000000230000090000000200000000000080 | 0005 | 5 | 00 | 000A | 10 | 00951F | 38175 | 0000 | 018B | 008FBD | 36797 | 0019 | 0501 | 1 | 0 | 0 | 0 | 0 | 0 |  | 018B | 4
00D3 | 211 | 001C9D | 7325 | 000B | 11 | 00006A | 106 | 6 | 0 | 02FF | 07 | B8 | 001D0A | 7434 | 43 | 000000100540100900000000000000000000000000000200000808000000000000000400000000000000010120200016060E020080000800000400000000000081200000400800000000000000000008000B00001F0000000200000000000080 | 0004 | 4 | 17 | 0009 | 9 | 00BA83 | 47747 | 0000 | 0150 | 008A46 | 35398 | 0025 | 0209 | 1 | 0 | 0 | 0 | 0 | 0 |  | 0177 | 1
017A | 378 | 00197D | 6525 | 0013 | 19 | 000081 | 129 | 10 | 0 | 02FF | 07 | 46 | 0014E4 | 5348 | 38 | 0000004204401000040002082000000000000000000000000010080000000000082000000000000800000000002080140400200080108010000400000000000001004008000000008400000000000000202900000100000004000000000000C0 | 0001 | 1 | 09 | 0002 | 2 | 0090D4 | 37076 | 0000 | 0177 | 0080F4 | 33012 | 001C | 0A09 | 1 | 0 | 0 | 0 | 0 | 0 |  | 00FF | 1
002B | 43 | 001081 | 4225 | 002B | 43 | 00002C | 44 | 17 | 0 | 020D | 0F | FF | 000C6F | 3183 | 17 | 000008000008400088000000000000000000020000000000000000010000000000000000000000000000010000000002000000000000000000040000000000000020000000000000000000000000000001030000080000000200000000000040 | 0001 | 1 | 00 | 0013 | 19 | 0014AC | 5292 | 0000 | 0013 | 007CCA | 31946 | 0000 | 0509 | 1 | 0 | 0 | 0 | 0 | 0 |  | 00B9 | 1
0242 | 578 | 0033B8 | 13240 | 007A | 122 | 0001EC | 492 | 85 | 0 | 02FF | 07 | 98 | 002D25 | 11557 | 376 | 0040A05200401000080000000000000000002200000200020018400200000800480104000000401000300104090000160206FFFFFFFFFFFFFFFFFFFFFFFFFFFFFFA9000861FEFFFFFFFFFFFFFFFFFFFDFFFFFFFFFFFFFFFFFFF3FFFFFFFFFFFF | 000A | 10 | 1A | 006E | 110 | 00471F | 18207 | 0000 | 020F | 0075C5 | 30149 | 0123 | 0209 | 1 | 0 | 0 | 0 | 0 | 0 |  | 0169 | 1
0166 | 358 | 000B15 | 2837 | 001E | 30 | 00001D | 29 | 23 | 0 | 020F | 0F | B3 | 000B31 | 2865 | 23 | 000000020000200008000000000000000000010000000000000000000000008000000000000000080020010040000002400400000000000000100000000000002080000002000000000000000000000001420000180000000200000000000080 | 0001 | 1 | 00 | 001F | 31 | 0072D1 | 29393 | 0000 | 00FF | 00728B | 29323 | 0000 | 0609 | 1 | 0 | 0 | 0 | 0 | 0 |  | 0226 | 2
0023 | 35 | 001EBC | 7868 | 009D | 157 | 000083 | 131 | 61 | 0 | 0200 | 0F | 86 | 002947 | 10567 | 61 | 00000012080000829000000008000000000000000000020600020001000008200800000000800019C420030040004000401C02008000880000040000000000002180003128000000D009080000000020212100000600000002000000000000C0 | 0005 | 5 | 62 | 0005 | 5 | 004B92 | 19346 | 0000 | 00B9 | 007151 | 29009 | 0000 | 0D09 | 1 | 0 | 0 | 0 | 0 | 0 |  | 0247 | 3
0036 | 54 | 0011EF | 4591 | 0015 | 21 | 000032 | 50 | 26 | 0 | 02FF | 07 | FF | 000E9B | 3739 | 26 | 0000480100084000080000000000000000000200000000000000400100000400000000000000000000000100000000020004000000000002000400000000000001200008000000000000000000000000010300000A00000002000000000000C0 | 0002 | 2 | 00 | 000E | 14 | 003119 | 12569 | 0000 | 0288 | 006CA2 | 27810 | 0000 | 0101 | 1 | 0 | 0 | 0 | 0 | 0 |  | 0280 | 5
00B5 | 181 | 0013FE | 5118 | 0012 | 18 | 000033 | 51 | 23 | 0 | 020D | 0F | 68 | 00103A | 4154 | 23 | 0000100000100001080000000000000000000000000020000000400000000000000000000000000800001000000300008000000000000002000400000000000001200000000000000000000000000000000B00000A00000002000000000000C0 | 0002 | 2 | 10 | 000A | 10 | 00059C | 1436 | 0000 | 0169 | 006C08 | 27656 | 0000 | 0601 | 1 | 0 | 0 | 0 | 0 | 0 |  | 00BA | 1
0042 | 66 | 00217D | 8573 | 002B | 43 | 0002F9 | 761 | 63 | 1 | 0221 | 3F | 4A | 002510 | 9488 | 63 | E0070012004000000C000000000000000000020000000000000082810100280108100400200008081010040800008004000000002000081B00040000000000008920001842000000CCA1000000000000040300800A00000002000000000000C0 | 0005 | 5 | 3C | 0079 | 121 | 0054BD | 21693 | 0243 | 0226 | 006B8D | 27533 | 0000 | 0709 | 1 | 0 | 0 | 0 | 0 | 0 |  | 0033 | 2
0216 | 534 | 0010FC | 4348 | 0017 | 23 | 00004A | 74 | 26 | 1 | 0200 | 0B | B1 | 000DB7 | 3511 | 26 | 0000001000000004800000000000000000000100000000000000020000000000400001000000000000400000020000140000000080006000000400000000000001884020000000000001000000000008004100000000000000000000000000C0 | 0001 | 1 | 1B | 0000 | 0 | 008B0D | 35597 | 0000 | 01CA | 006B7B | 27515 | 0000 | 0701 | 3 | 0 | 0 | 0 | 0 | 0 |  | 013B | 4
0017 | 23 | 00247E | 9342 | 000A | 10 | 00008B | 139 | 71 | 2 | 02FF | 37 | 90 | 0026BC | 9916 | 71 | 00048000004000098800000000000000000010000000400000184001000008804800008042800088003023040001000240494000801080170004000000000000012000800200000086A3080000000008050900001F00000006010000000000C0 | 0004 | 4 | 25 | 001E | 30 | 002AC9 | 10953 | 0247 | 0247 | 006B57 | 27479 | 0000 | 0101 | 1 | 0 | 0 | 0 | 0 | 0 |  | 0196 | 4
00D0 | 208 | 0008A3 | 2211 | 001D | 29 | 00000C | 12 | 20 | 0 | 020D | 0F | F4 | 000601 | 1537 | 20 | 0000000000000000080000000000000000000200000000000000010000000480000000000080000000000000000000000002000000000002000000000000000020200000020000000203000000000000010200000A0000000200000000000080 | 0001 | 1 | 00 | 001A | 26 | 0078CB | 30923 | 0000 | 0280 | 006A27 | 27175 | 0000 | 0601 | 1 | 0 | 0 | 0 | 0 | 0 |  | 001F | 1
00CB | 203 | 001B3A | 6970 | 001E | 30 | 000053 | 83 | 47 | 0 | 0212 | 0F | CE | 0016BD | 5821 | 47 | 000080100040000008000000080000000000000000000004000848010000080008200000002000080020000000000002C04C00008010000B001400000000000000A00400420000008400000000000008010300001B00000002000000000000C0 | 000A | 10 | 18 | 0006 | 6 | 002BAD | 11181 | 0000 | 00BA | 0069EF | 27119 | 0000 | 0501 | 1 | 0 | 0 | 0 | 0 | 0 |  | 0000 | 16
010B | 267 | 00107C | 4220 | 0000 | 0 | 000012 | 18 | 5 | 0 | 0000 | 03 | 69 | 0009F7 | 2551 | 5 | 000000000000080000000000000000000000000000000000000000000000000000080000000000000000024000000000000000008000000000000000000000000000000000000000000000000000000000000000000000000000000000000000 | 0000 | 0 | 32 | 0000 | 0 | 000000 | 0 | 0000 | 0033 | 0063C2 | 25538 | 0000 | 0101 | 3 | 0 | 0 | 0 | 0 | 0 |  | 0221 | 1
028E | 654 | 002F63 | 12131 | 0061 | 97 | 0000E3 | 227 | 43 | 0 | 0216 | 0F | 97 | 002DEB | 11755 | 43 | 000020000080000008000000100040000000010080020022000040000000008000000000800000000260010040100002C00C000000000011001000000000000020A04000100000000004000000000008016A00000800000002000000000000C0 | 0002 | 2 | 60 | 000C | 12 | 0098B2 | 39090 | 0000 | 0179 | 00636E | 25454 | 0000 | 0501 | 1 | 0 | 0 | 0 | 0 | 0 |  | 028E | 4
0253 | 595 | 003CC2 | 15554 | 0027 | 39 | 00007D | 125 | 60 | 0 | 02FF | 07 | 21 | 003354 | 13140 | 70 | 0000A0400800408008000000000000400000100000000000001042000000080101100400022400080031830000000012444D40008030881940140000000000000020050803000080E021080000000008040B00000A00000002000000000000C0 | 0002 | 2 | 83 | 000C | 12 | 009C26 | 39974 | 0000 | 0023 | 0061A3 | 24995 | 000A | 0B01 | 1 | 0 | 0 | 0 | 0 | 0 |  | 0047 | 3
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

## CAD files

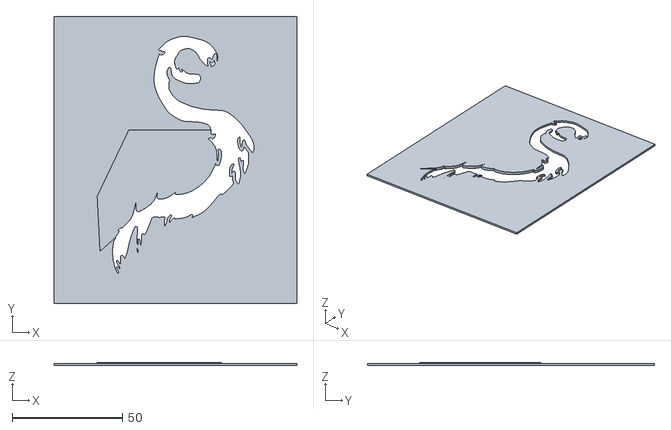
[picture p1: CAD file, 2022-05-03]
FreeCAD/tymkrs_Cyphercon_2020/Flamingo_main_body (Meshed).stl
110.0 x 130.0 x 1.50

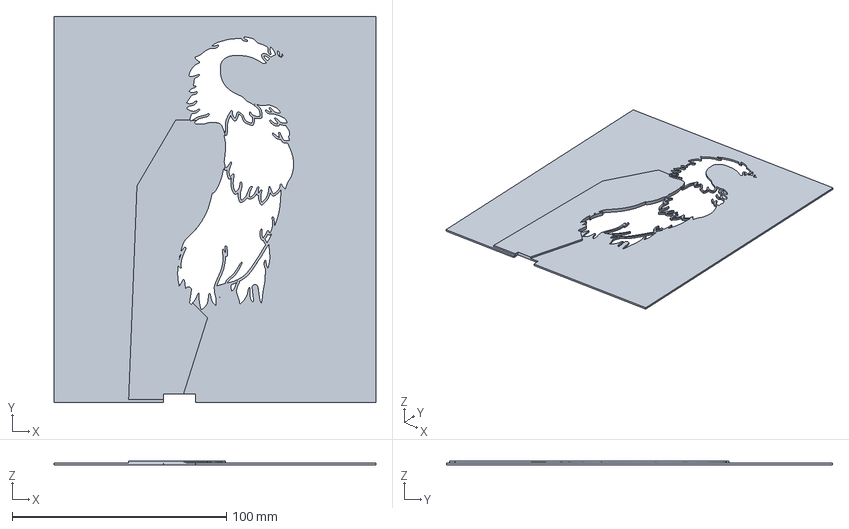
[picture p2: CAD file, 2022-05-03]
FreeCAD/tymkrs_Cyphercon_2020/Parrot_main_body_stencil (Meshed).3mf
150.0 x 180.0 x 2.00 mm

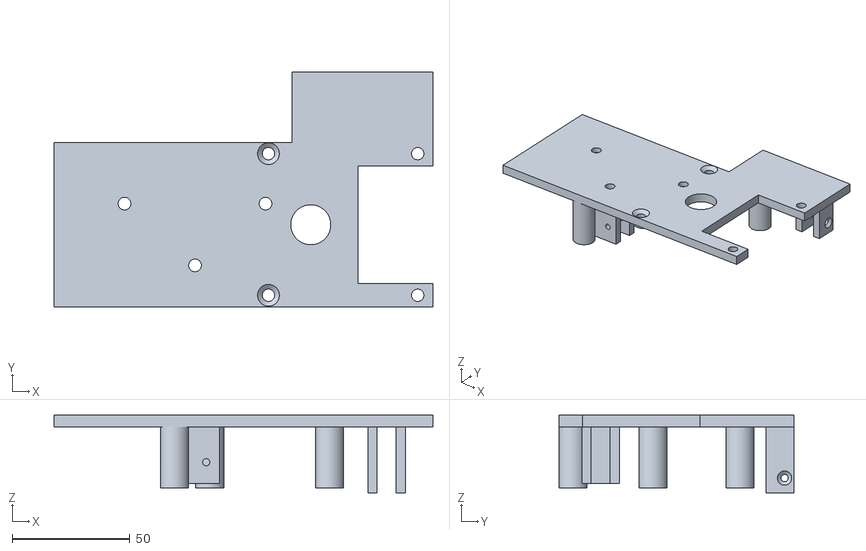
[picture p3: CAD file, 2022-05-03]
FreeCAD/Start button-2022/Motor mount (Meshed).stl
161.2 x 100.0 x 33.0

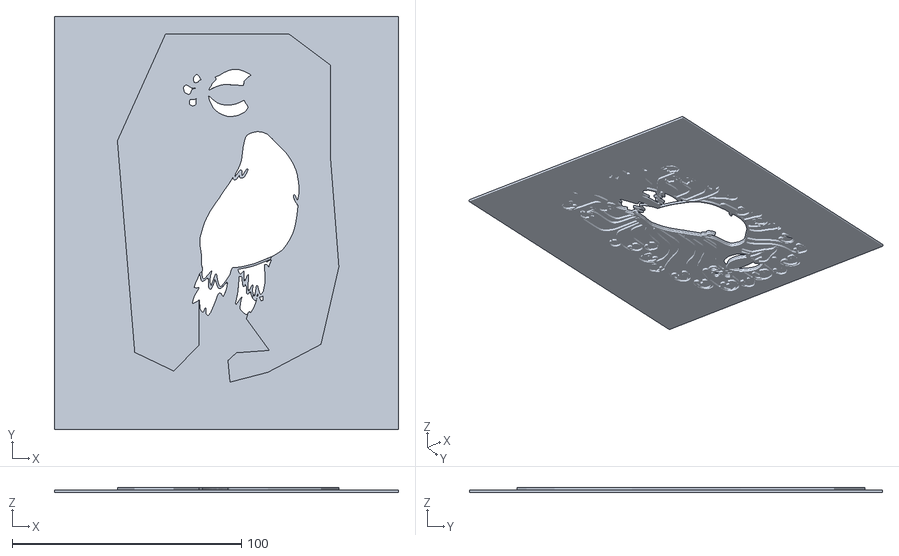
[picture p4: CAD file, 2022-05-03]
FreeCAD/tymkrs_Cyphercon_2020/peacock_body_stencil (Meshed).stl
150.0 x 180.0 x 2.00

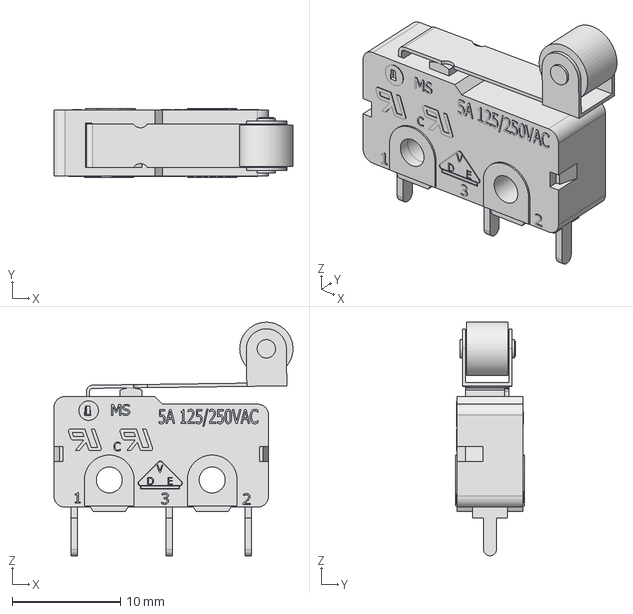
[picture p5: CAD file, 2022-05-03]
FreeCAD/Start button-2022/MS085xx05FxxxP1A.stp
22.1 x 6.40 x 21.6 mm

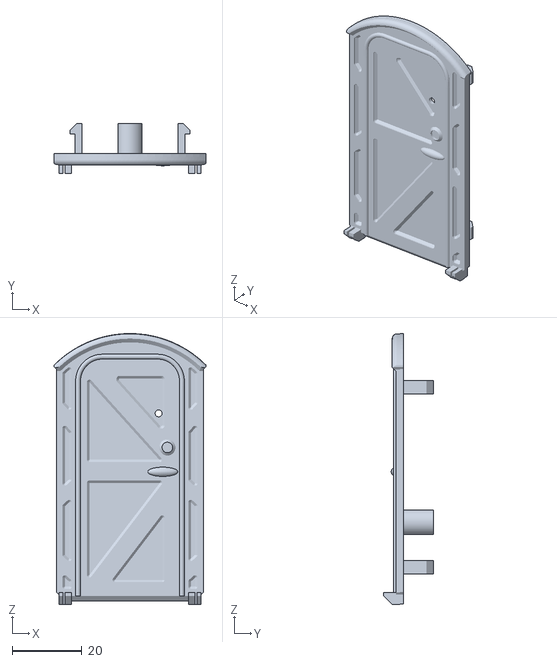
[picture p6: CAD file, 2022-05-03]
FreeCAD/tymkrs_Cyphercon_2020/port_a_potty_front.stl
43.4 x 14.2 x 77.6

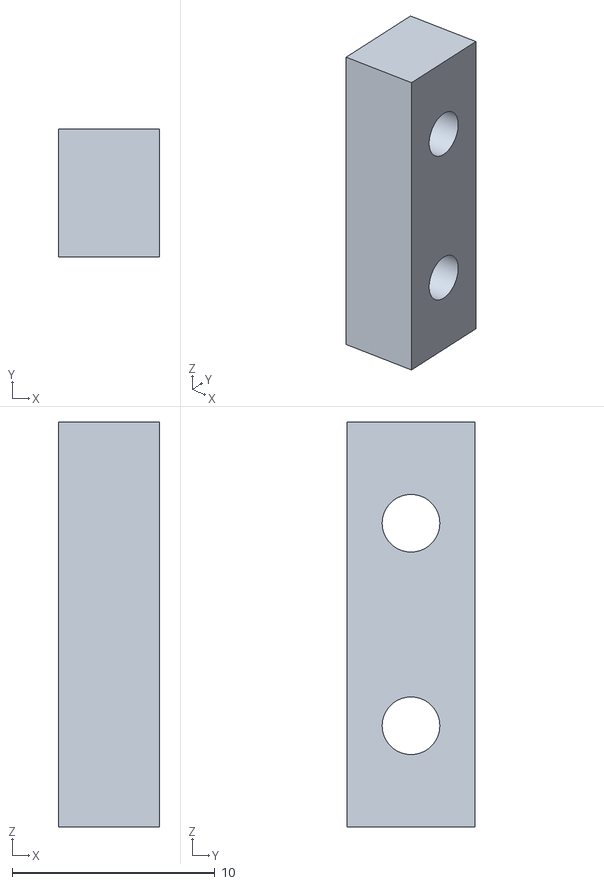
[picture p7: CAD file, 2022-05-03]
FreeCAD/Start button-2022/LED_panel_mount (Meshed).stl
5.00 x 6.30 x 20.0

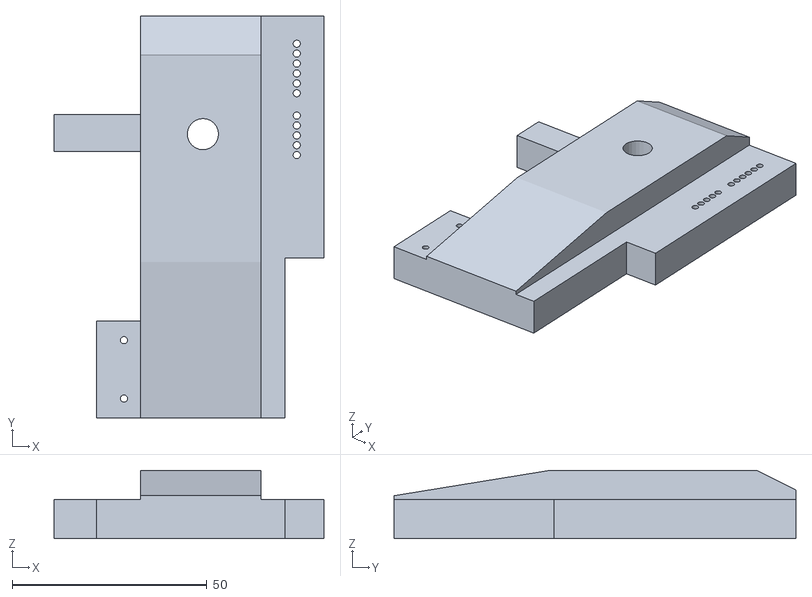
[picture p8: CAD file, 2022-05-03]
FreeCAD/tymkrs_Cyphercon_2020/probe block flamingo pgm (Meshed).stl
69.1 x 103.1 x 17.5

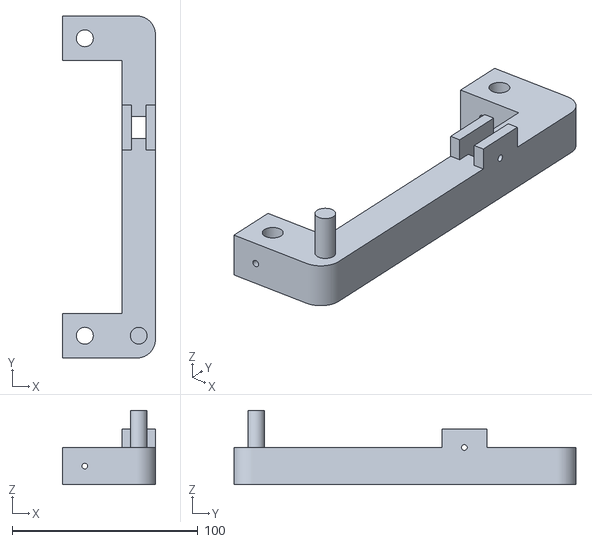
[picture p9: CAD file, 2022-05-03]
FreeCAD/Start button-2022/cable_support (Meshed).stl
50.0 x 184.0 x 40.0

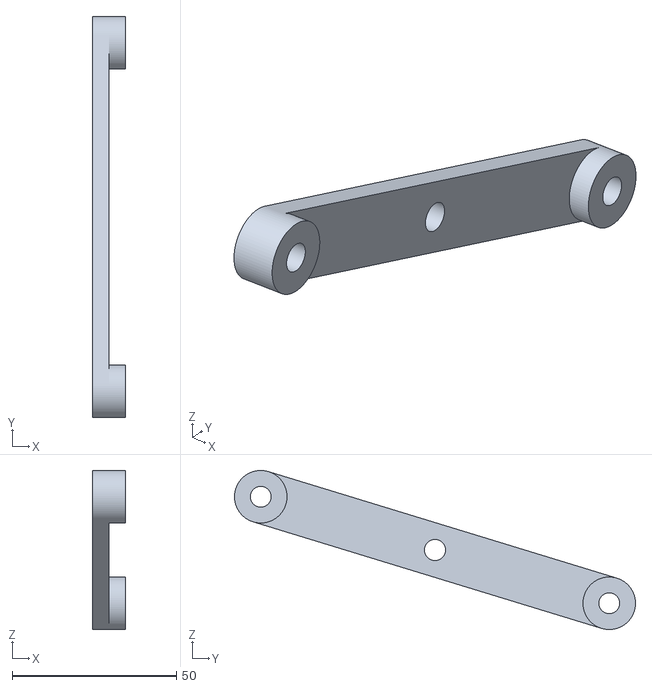
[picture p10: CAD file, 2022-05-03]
FreeCAD/Start button-2022/siz arm (Meshed).stl
10.0 x 122.1 x 48.4

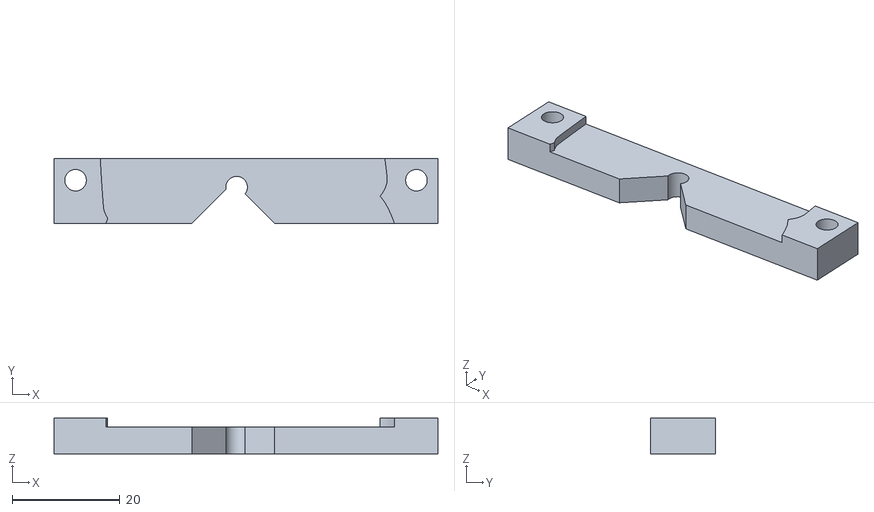
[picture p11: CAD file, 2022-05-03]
FreeCAD/tymkrs_Cyphercon_2020/Parrot_final(Meshed).stl
71.2 x 12.0 x 6.60

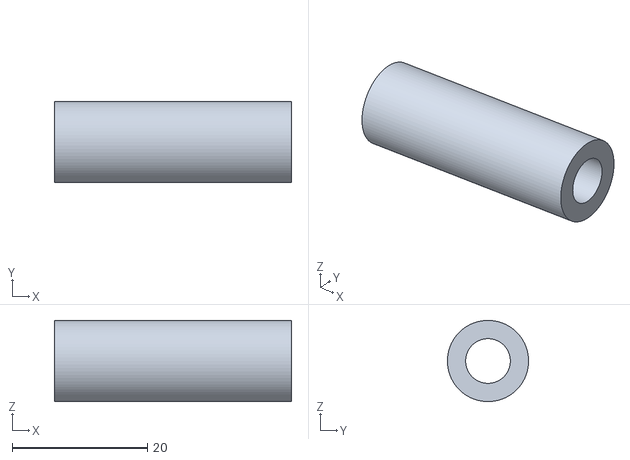
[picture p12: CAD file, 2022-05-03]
FreeCAD/Start button-2022/cable spacer (Meshed).stl
35.0 x 12.0 x 12.0

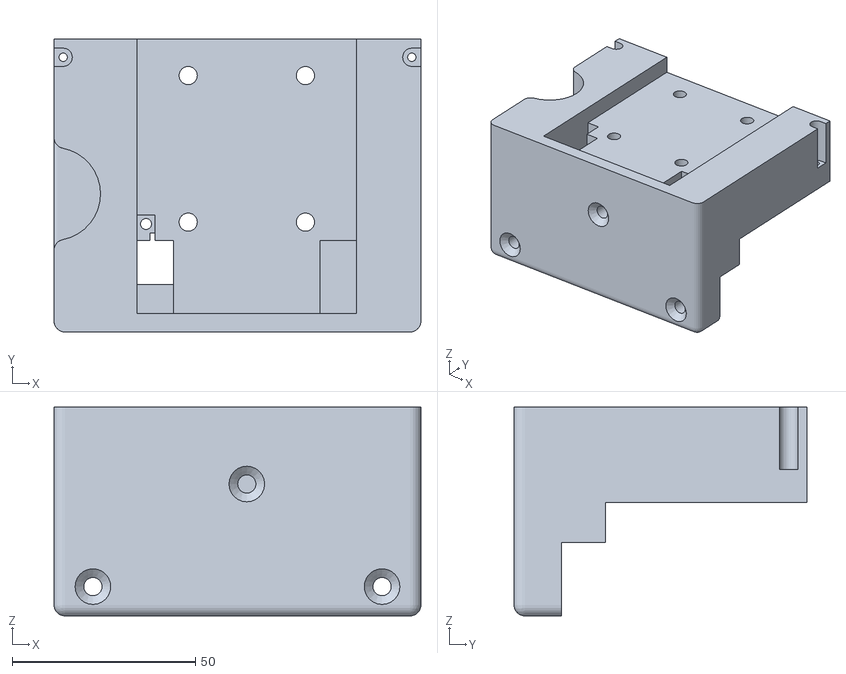
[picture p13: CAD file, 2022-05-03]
FreeCAD/tymkrs_Cyphercon_2020/Holder back (Meshed).stl
100.2 x 80.0 x 57.0

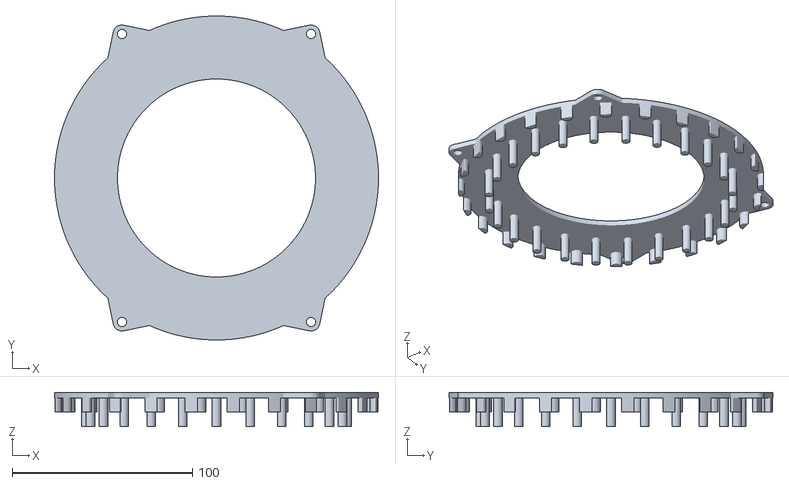
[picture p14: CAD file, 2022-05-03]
FreeCAD/Start button-2022/Mounting ring (Meshed).stl
180.0 x 180.0 x 19.0

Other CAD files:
FreeCAD/tymkrs_Cyphercon_2020/Flamingo_main_body_stencil (Meshed).3mf
FreeCAD/tymkrs_Cyphercon_2020/wash_holder_base.stl
FreeCAD/Start button-2022/iris_arm (Meshed)001.stl
FreeCAD/tymkrs_Cyphercon_2020/bottle_button_support.FCStd
FreeCAD/Start button-2022/1185 Massive Arcade Button 100mm.step
FreeCAD/Start button-2022/47065T801_T-Slotted Framing.STEP
FreeCAD/Start button-2022/6195A51_Threaded-Hole Round Pull Handle.STEP
FreeCAD/Start button-2022/Cam_disk (Meshed).stl
FreeCAD/Start button-2022/D2F_L2_D.step
FreeCAD/Start button-2022/Key_sw_spacer (Meshed).stl
FreeCAD/Start button-2022/Lift pully (Meshed).stl
FreeCAD/Start button-2022/Petal (Meshed) v0.stl
FreeCAD/Start button-2022/Petal (Meshed).stl
FreeCAD/Start button-2022/Switch_bracket (Meshed).stl
FreeCAD/Start button-2022/Switch_cam (Meshed).stl
FreeCAD/Start button-2022/Top Ring (Meshed).stl
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

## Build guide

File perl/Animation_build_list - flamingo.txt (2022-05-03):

start set 0
precon1
sleep1
sleepy1
precon1
sleepy2
precon2
precon1
sleep1
sleepy1
precon1
sleepy2
precon2
precon1
sleep1
sleepy1
precon1
end set

start set 1
precon1
sleep1
sleepy1
precon1
sleepy2
precon2
precon1
sleep1
sleepy1
precon1
sleepy2
precon2
precon1
sleep1
sleepy1
precon1
end set

start set 2
hyper1
hyper1
crazyeyes1
hyper2
hyper2
crazyeyes2 
hyper1
hyper1
crazyeyes3
hyper2
hyper2
crazyeyes4
hyper1
crazyeyes3
hyper2
crazyeyes2
end set

start set 3
hyper1
hyper1
sick1h
crazyeyes1
hyper2
hyper2
sick2h
crazyeyes2 
hyper1
sick3h
crazyeyes3
hyper2
sick4h
sick1h
crazyeyes2
sick2h
end set

start set 4
normal1
normal2
normal3
normal4
normal5
normal3
normal1
normal5
normal2
normal4
normal2
normal3
normal4
normal5
normal1
normal3
end set

start set 5
normal1
sick1
normal2
sick2
normal3
sick3
normal4
sick4
normal5
sick4
normal4
sick3
normal3
sick2
normal2
sick1
end set

start set 6
sleep1
sleepy1
sleepy2
sleep1
sleepy1
sleepy2
sleep1
sleepy1
sleep1
sleepy1
sleepy2
sleep1
sleepy1
sleepy2
sleep1
sleepy1
end set

start set 7
sleep1
sick1
sleepy2
sick2
sleepy1
sick3
sleep1
sick4
sleep1
sick4
sleepy2
sick3
sleepy1
sick2
sleep1
sick1
end set

start set 8
dead1
dead2
dead3
dead3
dead2
dead1
dead1
dead2
dead3
dead3
dead2
dead1
dead2
dead3
dead1
dead2
end set

start set 9
dead1
dead2
dead3
dead3
dead2
dead1
dead1
dead2
dead3
dead3
dead2
dead1
dead2
dead3
dead1
dead2
end set

start set 10
eyebeam1
eyebeam1
eyebeam2
eyebeam2
eyebeam3
eyebeam3
eyebeam1
eyebeam1
eyebeam2
eyebeam2
eyebeam3
eyebeam3
eyebeam2
eyebeam2
eyebeam3
eyebeam3
end set

start set 11
eyebeam1
eyebeam1
eyebeam2
eyebeam2
eyebeam3
eyebeam3
eyebeam1
eyebeam1
eyebeam2
eyebeam2
eyebeam3
eyebeam3
eyebeam2
eyebeam2
eyebeam3
eyebeam3
end set

start set 12
food
food
food
food
food
food
food
food
food
food
food
food
food
food
food
food
end set

start set 13
hbdh
hbdh
hbdh
hbdh
hbdh
hbdh
hbdh
hbdh
hbdh
hbdh
hbdh
hbdh
hbdh
hbdh
hbdh
hbdh
end set

start seq precon1
./F_eyes/sleep1.png 2s
./F_eyes/sleep7.png 1s
./F_eyes/sleep2.png 2s
./F_eyes/sleep10.png 1s
./F_eyes/sleep3.png 2s
./F_eyes/sleep9.png 1s
./F_eyes/sleep4.png 2s
./F_eyes/sleep8.png 1s
./F_eyes/sleep11.png 2s
./F_eyes/sleep12.png 1s
end seq

start seq sleep1
./F_eyes/sleep13.png 1s
./F_eyes/sleep14.png 1s
./F_eyes/sleep15.png 1s
./F_eyes/sleep16.png 1s
./F_eyes/sleep17.png 1s
./F_eyes/sleep18.png 1s
./F_eyes/sleep13.png 1s
./F_eyes/sleep14.png 1s
./F_eyes/sleep15.png 1s
./F_eyes/sleep16.png 1s
./F_eyes/sleep17.png 1s
./F_eyes/sleep18.png 1s
end seq

start seq sleepy1
./F_eyes/sleep1.png 1s
./F_eyes/sleep2.png 1s
./F_eyes/sleep3.png 1s
./F_eyes/halfblink1.png 1s
./F_eyes/halfblink2.png 1s
./F_eyes/halfblink4.png 1s
./F_eyes/sleep4.png 1s
./F_eyes/sleep5.png 1s
./F_eyes/sleep6.png 1s
end seq

start seq sleepy2
./F_eyes/sleep7.png 1s
./F_eyes/sleep8.png 1s
./F_eyes/halfblink5.png 1s
./F_eyes/halfblink6.png 1s
./F_eyes/halfblink7.png 1s
./F_eyes/sleep9.png 1s
./F_eyes/sleep10.png 1s
./F_eyes/sleep11.png 1s
./F_eyes/sleep12.png 1s
end seq

start seq precon2
./F_eyes/precon1.png 1s
./F_eyes/precon2.png 1s
./F_eyes/precon3.png 1s
./F_eyes/precon4.png 1s
./F_eyes/precon5.png 1s
./F_eyes/precon6.png 1s
./F_eyes/precon7.png 1s
./F_eyes/precon8.png 1s
./F_eyes/precon1.png 1s
./F_eyes/precon2.png 1s
./F_eyes/precon3.png 1s
./F_eyes/precon4.png 1s
./F_eyes/precon5.png 1s
./F_eyes/precon6.png 1s
./F_eyes/precon7.png 1s
./F_eyes/precon8.png 1s
end seq

###########

start seq hyper1
./F_eyes/hyper1.png 0.25s
./F_eyes/hyper2.png 0.25s
./F_eyes/hyper3.png 0.25s
./F_eyes/hyper4.png 0.25s
./F_eyes/hyper5.png 0.25s
./F_eyes/hyper6.png 0.25s
./F_eyes/hyper7.png 0.25s
./F_eyes/hyper8.png 0.25s
./F_eyes/hyper9.png 0.25s
./F_eyes/hyper10.png 0.25s
./F_eyes/hyper11.png 0.25s
end seq 

start seq hyper2
./F_eyes/hyper11.png 0.25s
./F_eyes/hyper10.png 0.25s
./F_eyes/hyper9.png 0.25s
./F_eyes/hyper8.png 0.25s
./F_eyes/hyper7.png 0.25s
./F_eyes/hyper6.png 0.25s
./F_eyes/hyper5.png 0.25s
./F_eyes/hyper6.png 0.25s
./F_eyes/hyper5.png 0.25s
./F_eyes/hyper4.png 0.25s
./F_eyes/hyper3.png 0.25s
./F_eyes/hyper2.png 0.25s
./F_eyes/hyper1.png 0.25s
end seq

start seq crazyeyes1
./F_eyes/hyper1.png 0.25s
./F_eyes/normal17.png 0.25s
./F_eyes/normal7.png 0.25s
./F_eyes/hyper2.png 0.25s
./F_eyes/normal18.png 0.25s
./F_eyes/normal5.png 0.25s
./F_eyes/hyper3.png 0.25s
./F_eyes/normal16.png 0.25s
./F_eyes/normal5.png 0.25s
./F_eyes/hyper4.png 0.25s
./F_eyes/normal15.png 0.25s
./F_eyes/normal4.png 0.25s
./F_eyes/hyper5.png 0.25s
./F_eyes/normal14.png 0.25s
./F_eyes/normal11.png 0.25s
end seq

start seq crazyeyes2
./F_eyes/normal11.png 0.25s
./F_eyes/normal14.png 0.25s
./F_eyes/hyper5.png 0.25s
./F_eyes/normal4.png 0.25s
./F_eyes/normal15.png 0.25s
./F_eyes/hyper4.png 0.25s
./F_eyes/normal5.png 0.25s
./F_eyes/normal16.png 0.25s
./F_eyes/hyper3.png 0.25s
./F_eyes/normal5.png 0.25s
./F_eyes/normal18.png 0.25s
./F_eyes/hyper2.png 0.25s
./F_eyes/normal7.png 0.25s
./F_eyes/normal17.png 0.25s
./F_eyes/hyper1.png 0.25s
end seq

start seq crazyeyes3
./F_eyes/hyper1.png 0.25s
./F_eyes/normal7.png 0.25s
./F_eyes/hyper2.png 0.25s
./F_eyes/normal5.png 0.25s
./F_eyes/hyper3.png 0.25s
./F_eyes/normal5.png 0.25s
./F_eyes/hyper4.png 0.25s
./F_eyes/normal4.png 0.25s
./F_eyes/hyper5.png 0.25s
./F_eyes/normal11.png 0.25s
end seq

start seq crazyeyes4
./F_eyes/normal11.png 0.25s
./F_eyes/hyper5.png 0.25s
./F_eyes/normal4.png 0.25s
./F_eyes/hyper4.png 0.25s
./F_eyes/normal5.png 0.25s
./F_eyes/hyper3.png 0.25s
./F_eyes/normal5.png 0.25s
./F_eyes/hyper2.png 0.25s
./F_eyes/normal7.png 0.25s
./F_eyes/hyper1.png 0.25s
end seq

start seq sick1h
./F_eyes/sick1.png 0.25s
./F_eyes/sick19.png 0.25s
./F_eyes/sick13.png 0.25s
./F_eyes/sick7.png 0.25s
./F_eyes/sick2.png 0.25s
./F_eyes/sick20.png 0.25s
./F_eyes/sick14.png 0.25s
./F_eyes/sick8.png 0.25s
./F_eyes/sick3.png 0.25s
./F_eyes/sick21.png 0.25s
./F_eyes/sick15.png 0.25s
./F_eyes/sick9.png 0.25s
./F_eyes/sick4.png 0.25s
./F_eyes/sick22.png 0.25s
./F_eyes/sick16.png 0.25s
./F_eyes/sick10.png 0.25s
./F_eyes/sick5.png 0.25s
./F_eyes/sick23.png 0.25s
./F_eyes/sick17.png 0.25s
./F_eyes/sick11.png 0.25s
./F_eyes/sick6.png 0.25s
./F_eyes/sick24.png 0.25s
./F_eyes/sick18.png 0.25s
./F_eyes/sick12.png 0.25s
./F_eyes/sick7.png 0.25s
./F_eyes/sick20.png 0.25s
./F_eyes/sick19.png 0.25s
./F_eyes/sick7.png 0.25s
end seq

start seq sick2h
./F_eyes/sick7.png 0.25s
./F_eyes/sick19.png 0.25s
./F_eyes/sick20.png 0.25s
./F_eyes/sick7.png 0.25s
./F_eyes/sick12.png 0.25s
./F_eyes/sick18.png 0.25s
./F_eyes/sick24.png 0.25s
./F_eyes/sick6.png 0.25s
./F_eyes/sick11.png 0.25s
./F_eyes/sick17.png 0.25s
./F_eyes/sick23.png 0.25s
./F_eyes/sick5.png 0.25s
./F_eyes/sick10.png 0.25s
./F_eyes/sick16.png 0.25s
./F_eyes/sick22.png 0.25s
./F_eyes/sick4.png 0.25s
./F_eyes/sick9.png 0.25s
./F_eyes/sick15.png 0.25s
./F_eyes/sick21.png 0.25s
./F_eyes/sick3.png 0.25s
./F_eyes/sick8.png 0.25s
./F_eyes/sick14.png 0.25s
./F_eyes/sick20.png 0.25s
./F_eyes/sick2.png 0.25s
./F_eyes/sick7.png 0.25s
./F_eyes/sick13.png 0.25s
./F_eyes/sick19.png 0.25s
./F_eyes/sick1.png 0.25s
end seq

start seq sick3h
./F_eyes/sick25.png 0.25s
./F_eyes/sick7.png 0.25s
./F_eyes/sick13.png 0.25s
./F_eyes/sick19.png 0.25s
./F_eyes/sick1.png 0.25s
./F_eyes/sick26.png 0.25s
./F_eyes/sick6.png 0.25s
./F_eyes/sick24.png 0.25s
./F_eyes/sick18.png 0.25s
./F_eyes/sick12.png 0.25s
./F_eyes/sick27.png 0.25s
./F_eyes/sick8.png 0.25s
./F_eyes/sick14.png 0.25s
./F_eyes/sick20.png 0.25s
./F_eyes/sick2.png 0.25s
./F_eyes/sick31.png 0.25s
./F_eyes/sick12.png 0.25s
./F_eyes/sick18.png 0.25s
./F_eyes/sick24.png 0.25s
./F_eyes/sick6.png 0.25s
./F_eyes/sick32.png 0.25s
./F_eyes/sick2.png 0.25s
./F_eyes/sick20.png 0.25s
./F_eyes/sick14.png 0.25s
./F_eyes/sick8.png 0.25s
end seq

start seq sick4h
./F_eyes/sick28.png 0.25s
./F_eyes/sick25.png 0.25s
./F_eyes/sick29.png 0.25s
./F_eyes/sick26.png 0.25s
./F_eyes/sick8.png 0.25s
./F_eyes/sick14.png 0.25s
./F_eyes/sick20.png 0.25s
./F_eyes/sick2.png 0.25s
./F_eyes/sick30.png 0.25s
./F_eyes/sick32.png 0.25s
./F_eyes/sick31.png 0.25s
./F_eyes/sick11.png 0.25s
./F_eyes/sick17.png 0.25s
./F_eyes/sick23.png 0.25s
./F_eyes/sick5.png 0.25s
end seq

#####

start seq normal1
./F_eyes/normal6.png 1s
./F_eyes/normal7.png 1s
./F_eyes/happy1.png 1s
./F_eyes/normal8.png 1s
./F_eyes/normal9.png 1s
./F_eyes/normal10.png 1s
./F_eyes/happy2.png 1s
./F_eyes/normal11.png 1s
./F_eyes/happy4.png 1s
./F_eyes/happy3.png 1s
./F_eyes/happy5.png 1s
./F_eyes/happy6.png 1s
./F_eyes/normal12.png 1s
./F_eyes/normal13.png 1s
./F_eyes/normal14.png 1s
./F_eyes/happy7.png 1s
./F_eyes/normal15.png 1s
./F_eyes/normal16.png 1s
./F_eyes/normal17.png 1s
./F_eyes/normal18.png 1s
./F_eyes/happy6.png 1s
end seq

start seq normal2
./F_eyes/normal1.png 1s
./F_eyes/normal3.png 1s
./F_eyes/happy7.png 1s
./F_eyes/normal2.png 1s
./F_eyes/normal4.png 1s
./F_eyes/normal5.png 1s
./F_eyes/happy6.png 1s
./F_eyes/normal6.png 1s
./F_eyes/normal7.png 1s
./F_eyes/normal8.png 1s
./F_eyes/happy5.png 1s
./F_eyes/normal9.png 1s
./F_eyes/normal10.png 1s
./F_eyes/happy4.png 1s
./F_eyes/happy3.png 1s
./F_eyes/normal11.png 1s
./F_eyes/happy2.png 1s
./F_eyes/happy1.png 1s
end seq

start seq normal3
./F_eyes/normal1.png 1s
./F_eyes/halfblink1.png 1s
./F_eyes/blink.png 1s
./F_eyes/halfblink2.png 1s
./F_eyes/normal2.png 1s
./F_eyes/normal3.png 1s
./F_eyes/normal4.png 1s
./F_eyes/halfblink4.png 1s
./F_eyes/blink.png 1s
./F_eyes/halfblink5.png 1s
./F_eyes/normal5.png 1s
./F_eyes/normal6.png 1s
./F_eyes/normal7.png 1s
./F_eyes/halfblink7.png 1s
./F_eyes/blink.png 1s
./F_eyes/halfblink8.png 1s
./F_eyes/normal8.png 1s
./F_eyes/normal9.png 1s
./F_eyes/normal10.png 1s
./F_eyes/normal11.png 1s
end seq

start seq normal4
./F_eyes/normal12.png 1s
./F_eyes/halfblink8.png 0.5s
./F_eyes/blink.png 0.5s
./F_eyes/halfblink2.png 0.5s
./F_eyes/normal13.png 1s
./F_eyes/normal14.png 1s
./F_eyes/normal15.png 1s
./F_eyes/halfblink5.png 0.5s
./F_eyes/blink.png 0.5s
./F_eyes/halfblink6.png 0.5s
./F_eyes/normal16.png 1s
./F_eyes/normal17.png 1s
./F_eyes/halfblink6.png 0.5s
./F_eyes/blink.png 0.5s
./F_eyes/halfblink8.png 0.5s
./F_eyes/normal18.png 1s
end seq

start seq normal5
./F_eyes/normal5.png 1s
./F_eyes/normal6.png 1s
./F_eyes/normal7.png 1s
./F_eyes/halfblink7.png 0.5s
./F_eyes/blink.png 0.5s
./F_eyes/halfblink8.png 0.5s
./F_eyes/normal8.png 1s
./F_eyes/normal9.png 1s
./F_eyes/normal10.png 1s
./F_eyes/halfblink10.png 0.5s
./F_eyes/blink.png 0.5s
./F_eyes/halfblink1.png 0.5s
./F_eyes/normal1.png 1s
./F_eyes/normal2.png 1s
./F_eyes/normal3.png 1s
./F_eyes/halfblink3.png 0.5s
./F_eyes/blink.png 0.5s
./F_eyes/halfblink6.png 0.5s
./F_eyes/normal6.png 1s
end seq

####

start seq sick1
./F_eyes/sick1.png 1s
./F_eyes/sick19.png 1s
./F_eyes/sick13.png 1s
./F_eyes/sick7.png 1s
./F_eyes/sick2.png 1s
./F_eyes/sick20.png 1s
./F_eyes/sick14.png 1s
./F_eyes/sick8.png 1s
./F_eyes/sick3.png 1s
./F_eyes/sick21.png 1s
./F_eyes/sick15.png 1s
./F_eyes/sick9.png 1s
./F_eyes/sick4.png 1s
./F_eyes/sick22.png 1s
./F_eyes/sick16.png 1s
./F_eyes/sick10.png 1s
./F_eyes/sick5.png 1s
./F_eyes/sick23.png 1s
./F_eyes/sick17.png 1s
./F_eyes/sick11.png 1s
./F_eyes/sick6.png 1s
./F_eyes/sick24.png 1s
./F_eyes/sick18.png 1s
./F_eyes/sick12.png 1s
./F_eyes/sick7.png 1s
./F_eyes/sick20.png 1s
./F_eyes/sick19.png 1s
./F_eyes/sick7.png 1s
end seq

start seq sick2
./F_eyes/sick7.png 1s
./F_eyes/sick19.png 1s
./F_eyes/sick20.png 1s
./F_eyes/sick7.png 1s
./F_eyes/sick12.png 1s
./F_eyes/sick18.png 1s
./F_eyes/sick24.png 1s
./F_eyes/sick6.png 1s
./F_eyes/sick11.png 1s
./F_eyes/sick17.png 1s
./F_eyes/sick23.png 1s
./F_eyes/sick5.png 1s
./F_eyes/sick10.png 1s
./F_eyes/sick16.png 1s
./F_eyes/sick22.png 1s
./F_eyes/sick4.png 1s
./F_eyes/sick9.png 1s
./F_eyes/sick15.png 1s
./F_eyes/sick21.png 1s
./F_eyes/sick3.png 1s
./F_eyes/sick8.png 1s
./F_eyes/sick14.png 1s
./F_eyes/sick20.png 1s
./F_eyes/sick2.png 1s
./F_eyes/sick7.png 1s
./F_eyes/sick13.png 1s
./F_eyes/sick19.png 1s
./F_eyes/sick1.png 1s
end seq

start seq sick3
./F_eyes/sick25.png 1s
./F_eyes/sick7.png 1s
./F_eyes/sick13.png 1s
./F_eyes/sick19.png 1s
./F_eyes/sick1.png 1s
./F_eyes/sick26.png 1s
./F_eyes/sick6.png 1s
./F_eyes/sick24.png 1s
./F_eyes/sick18.png 1s
./F_eyes/sick12.png 1s
./F_eyes/sick27.png 1s
./F_eyes/sick8.png 1s
./F_eyes/sick14.png 1s
./F_eyes/sick20.png 1s
./F_eyes/sick2.png 1s
./F_eyes/sick31.png 1s
./F_eyes/sick12.png 1s
./F_eyes/sick18.png 1s
./F_eyes/sick24.png 1s
./F_eyes/sick6.png 1s
./F_eyes/sick32.png 1s
./F_eyes/sick2.png 1s
./F_eyes/sick20.png 1s
./F_eyes/sick14.png 1s
./F_eyes/sick8.png 1s
end seq

start seq sick4
./F_eyes/sick28.png 1s
./F_eyes/sick25.png 1s
./F_eyes/sick29.png 1s
./F_eyes/sick26.png 1s
./F_eyes/sick8.png 1s
./F_eyes/sick14.png 1s
./F_eyes/sick20.png 1s
./F_eyes/sick2.png 1s
./F_eyes/sick30.png 1s
./F_eyes/sick32.png 1s
./F_eyes/sick31.png 1s
./F_eyes/sick11.png 1s
./F_eyes/sick17.png 1s
./F_eyes/sick23.png 1s
./F_eyes/sick5.png 1s
end seq

####

start seq dead1
./F_eyes/dead1.png 2s
./F_eyes/dead12.png 2s
./F_eyes/dead1.png 2s
./F_eyes/dead12.png 2s
./F_eyes/dead2.png 2s
./F_eyes/dead1.png 2s
./F_eyes/dead2.png 2s
end seq

start seq dead2
./F_eyes/dead2.png 2s
./F_eyes/dead3.png 2s
./F_eyes/dead4.png 2s
./F_eyes/dead5.png 2s
./F_eyes/dead6.png 2s
end seq

start seq dead3
./F_eyes/dead13.png 2s
./F_eyes/dead7.png 2s
./F_eyes/dead8.png 2s
./F_eyes/dead9.png 2s
./F_eyes/dead10.png 2s
./F_eyes/dead11.png 2s
end seq

####

start seq eyebeam1
./F_eyes/eyebeam1.png 0.25s
./F_eyes/eyebeam2.png 0.25s
./F_eyes/eyebeam3.png 0.25s
./F_eyes/eyebeam4.png 0.25s
./F_eyes/eyebeam5.png 0.25s
./F_eyes/eyebeam6.png 0.25s
./F_eyes/eyebeam7.png 0.25s
./F_eyes/eyebeam8.png 0.25s
./F_eyes/eyebeam9.png 0.25s
end seq

start seq eyebeam2
./F_eyes/eyebeam11.png 1s
./F_eyes/eyebeam12.png 1s
./F_eyes/eyebeam13.png 1s
./F_eyes/eyebeam14.png 1s
end seq

start seq eyebeam3
./F_eyes/eyebeam14.png 1s
./F_eyes/eyebeam15.png 1s
./F_eyes/eyebeam16.png 1s
end seq

####

start seq food
./F_eyes/food1.png 1s
./F_eyes/food2.png 1s
./F_eyes/food3.png 1s
./F_eyes/food4.png 1s
./F_eyes/food5.png 1s
./F_eyes/food6.png 1s
./F_eyes/food7.png 1s
./F_eyes/food8.png 1s
./F_eyes/food9.png 1s
./F_eyes/food10.png 1s
./F_eyes/food11.png 1s
./F_eyes/food12.png 1s
end seq

#########################################################################################################
start seq hbdh
./hbdh.png 2s
end seq

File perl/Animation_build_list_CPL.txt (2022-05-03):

start set 0
precon1
sleep1
sleepy1
precon1
sleepy2
precon2
precon1
sleep1
sleepy1
precon1
sleepy2
precon2
precon1
sleep1
sleepy1
precon1
end set

start set 1
precon1
sleep1
sleepy1
precon1
sleepy2
precon2
precon1
sleep1
sleepy1
precon1
sleepy2
precon2
precon1
sleep1
sleepy1
precon1
end set

start set 2
hyper1
hyper1
crazyeyes1
hyper2
hyper2
crazyeyes2 
hyper1
hyper1
crazyeyes3
hyper2
hyper2
crazyeyes4
hyper1
crazyeyes3
hyper2
crazyeyes2
end set

start set 3
hyper1
hyper1
sick1h
crazyeyes1
hyper2
hyper2
sick2h
crazyeyes2 
hyper1
sick3h
crazyeyes3
hyper2
sick4h
sick1h
crazyeyes2
sick2h
end set

start set 4
normal1
normal2
normal3
normal4
normal5
normal3
normal1
normal5
normal2
normal4
normal2
normal3
normal4
normal5
normal1
normal3
end set

start set 5
normal1
sick1
normal2
sick2
normal3
sick3
normal4
sick4
normal5
sick4
normal4
sick3
normal3
sick2
normal2
sick1
end set

start set 6
sleep1
sleepy1
sleepy2
sleep1
sleepy1
sleepy2
sleep1
sleepy1
sleep1
sleepy1
sleepy2
sleep1
sleepy1
sleepy2
sleep1
sleepy1
end set

start set 7
sleep1
sick1
sleepy2
sick2
sleepy1
sick3
sleep1
sick4
sleep1
sick4
sleepy2
sick3
sleepy1
sick2
sleep1
sick1
end set

start set 8
dead1
dead2
dead3
dead3
dead2
dead1
dead1
dead2
dead3
dead3
dead2
dead1
dead2
dead3
dead1
dead2
end set

start set 9
dead1
dead2
dead3
dead3
dead2
dead1
dead1
dead2
dead3
dead3
dead2
dead1
dead2
dead3
dead1
dead2
end set

start set 10
eyebeam1
eyebeam1
eyebeam2
eyebeam2
eyebeam3
eyebeam3
eyebeam1
eyebeam1
eyebeam2
eyebeam2
eyebeam3
eyebeam3
eyebeam2
eyebeam2
eyebeam3
eyebeam3
end set

start set 11
eyebeam1
eyebeam1
eyebeam2
eyebeam2
eyebeam3
eyebeam3
eyebeam1
eyebeam1
eyebeam2
eyebeam2
eyebeam3
eyebeam3
eyebeam2
eyebeam2
eyebeam3
eyebeam3
end set

start set 12
food
food
food
food
food
food
food
food
food
food
food
food
food
food
food
food
end set

start set 13
hbdh
hbdh
hbdh
hbdh
hbdh
hbdh
hbdh
hbdh
hbdh
hbdh
hbdh
hbdh
hbdh
hbdh
hbdh
hbdh
end set

##################################################################################################

start seq precon1
./CPL_eyes/sleep1.png 2s
./CPL_eyes/sleep7.png 1s
./CPL_eyes/sleep2.png 2s
./CPL_eyes/sleep10.png 1s
./CPL_eyes/sleep3.png 2s
./CPL_eyes/sleep9.png 1s
./CPL_eyes/sleep4.png 2s
./CPL_eyes/sleep8.png 1s
./CPL_eyes/sleep11.png 2s
./CPL_eyes/sleep12.png 1s
end seq

start seq sleep1
./CPL_eyes/sleep13.png 1s
./CPL_eyes/sleep14.png 1s
./CPL_eyes/sleep15.png 1s
./CPL_eyes/sleep16.png 1s
./CPL_eyes/sleep17.png 1s
./CPL_eyes/sleep18.png 1s
./CPL_eyes/sleep13.png 1s
./CPL_eyes/sleep14.png 1s
./CPL_eyes/sleep15.png 1s
./CPL_eyes/sleep16.png 1s
./CPL_eyes/sleep17.png 1s
./CPL_eyes/sleep18.png 1s
end seq

start seq sleepy1
./CPL_eyes/sleep1.png 1s
./CPL_eyes/sleep2.png 1s
./CPL_eyes/sleep3.png 1s
./CPL_eyes/halfblink1.png 1s
./CPL_eyes/halfblink2.png 1s
./CPL_eyes/halfblink4.png 1s
./CPL_eyes/sleep4.png 1s
./CPL_eyes/sleep5.png 1s
./CPL_eyes/sleep6.png 1s
end seq

start seq sleepy2
./CPL_eyes/sleep7.png 1s
./CPL_eyes/sleep8.png 1s
./CPL_eyes/halfblink5.png 1s
./CPL_eyes/halfblink6.png 1s
./CPL_eyes/halfblink7.png 1s
./CPL_eyes/sleep9.png 1s
./CPL_eyes/sleep10.png 1s
./CPL_eyes/sleep11.png 1s
./CPL_eyes/sleep12.png 1s
end seq

start seq precon2
./CPL_eyes/precon1.png 1s
./CPL_eyes/precon2.png 1s
./CPL_eyes/precon3.png 1s
./CPL_eyes/precon4.png 1s
./CPL_eyes/precon5.png 1s
./CPL_eyes/precon6.png 1s
./CPL_eyes/precon7.png 1s
./CPL_eyes/precon8.png 1s
./CPL_eyes/precon1.png 1s
./CPL_eyes/precon2.png 1s
./CPL_eyes/precon3.png 1s
./CPL_eyes/precon4.png 1s
./CPL_eyes/precon5.png 1s
./CPL_eyes/precon6.png 1s
./CPL_eyes/precon7.png 1s
./CPL_eyes/precon8.png 1s
end seq

###########

start seq hyper1
./CPL_eyes/hyper1.png 0.25s
./CPL_eyes/hyper2.png 0.25s
./CPL_eyes/hyper3.png 0.25s
./CPL_eyes/hyper4.png 0.25s
./CPL_eyes/hyper5.png 0.25s
./CPL_eyes/hyper6.png 0.25s
./CPL_eyes/hyper7.png 0.25s
./CPL_eyes/hyper8.png 0.25s
./CPL_eyes/hyper9.png 0.25s
./CPL_eyes/hyper10.png 0.25s
./CPL_eyes/hyper11.png 0.25s
end seq 

start seq hyper2
./CPL_eyes/hyper11.png 0.25s
./CPL_eyes/hyper10.png 0.25s
./CPL_eyes/hyper9.png 0.25s
./CPL_eyes/hyper8.png 0.25s
./CPL_eyes/hyper7.png 0.25s
./CPL_eyes/hyper6.png 0.25s
./CPL_eyes/hyper5.png 0.25s
./CPL_eyes/hyper6.png 0.25s
./CPL_eyes/hyper5.png 0.25s
./CPL_eyes/hyper4.png 0.25s
./CPL_eyes/hyper3.png 0.25s
./CPL_eyes/hyper2.png 0.25s
./CPL_eyes/hyper1.png 0.25s
end seq

start seq crazyeyes1
./CPL_eyes/hyper1.png 0.25s
./CPL_eyes/normal7.png 0.25s
./CPL_eyes/normal7.png 0.25s
./CPL_eyes/hyper2.png 0.25s
./CPL_eyes/normal8.png 0.25s
./CPL_eyes/normal5.png 0.25s
./CPL_eyes/hyper3.png 0.25s
./CPL_eyes/normal6.png 0.25s
./CPL_eyes/normal5.png 0.25s
./CPL_eyes/hyper4.png 0.25s
./CPL_eyes/normal5.png 0.25s
./CPL_eyes/normal4.png 0.25s
./CPL_eyes/hyper5.png 0.25s
./CPL_eyes/normal4.png 0.25s
./CPL_eyes/normal1.png 0.25s
end seq

start seq crazyeyes2
./CPL_eyes/normal1.png 0.25s
./CPL_eyes/normal4.png 0.25s
./CPL_eyes/hyper5.png 0.25s
./CPL_eyes/normal4.png 0.25s
./CPL_eyes/normal5.png 0.25s
./CPL_eyes/hyper4.png 0.25s
./CPL_eyes/normal5.png 0.25s
./CPL_eyes/normal6.png 0.25s
./CPL_eyes/hyper3.png 0.25s
./CPL_eyes/normal5.png 0.25s
./CPL_eyes/normal8.png 0.25s
./CPL_eyes/hyper2.png 0.25s
./CPL_eyes/normal7.png 0.25s
./CPL_eyes/normal7.png 0.25s
./CPL_eyes/hyper1.png 0.25s
end seq

start seq crazyeyes3
./CPL_eyes/hyper1.png 0.25s
./CPL_eyes/normal7.png 0.25s
./CPL_eyes/hyper2.png 0.25s
./CPL_eyes/normal5.png 0.25s
./CPL_eyes/hyper3.png 0.25s
./CPL_eyes/normal5.png 0.25s
./CPL_eyes/hyper4.png 0.25s
./CPL_eyes/normal4.png 0.25s
./CPL_eyes/hyper5.png 0.25s
./CPL_eyes/normal1.png 0.25s
end seq

start seq crazyeyes4
./CPL_eyes/normal1.png 0.25s
./CPL_eyes/hyper5.png 0.25s
./CPL_eyes/normal4.png 0.25s
./CPL_eyes/hyper4.png 0.25s
./CPL_eyes/normal5.png 0.25s
./CPL_eyes/hyper3.png 0.25s
./CPL_eyes/normal5.png 0.25s
./CPL_eyes/hyper2.png 0.25s
./CPL_eyes/normal7.png 0.25s
./CPL_eyes/hyper1.png 0.25s
end seq

start seq sick1h
./CPL_eyes/sick1.png 0.25s
./CPL_eyes/sick19.png 0.25s
./CPL_eyes/sick13.png 0.25s
./CPL_eyes/sick7.png 0.25s
./CPL_eyes/sick2.png 0.25s
./CPL_eyes/sick20.png 0.25s
./CPL_eyes/sick14.png 0.25s
./CPL_eyes/sick8.png 0.25s
./CPL_eyes/sick3.png 0.25s
./CPL_eyes/sick21.png 0.25s
./CPL_eyes/sick15.png 0.25s
./CPL_eyes/sick9.png 0.25s
./CPL_eyes/sick4.png 0.25s
./CPL_eyes/sick22.png 0.25s
./CPL_eyes/sick16.png 0.25s
./CPL_eyes/sick10.png 0.25s
./CPL_eyes/sick5.png 0.25s
./CPL_eyes/sick23.png 0.25s
./CPL_eyes/sick17.png 0.25s
./CPL_eyes/sick11.png 0.25s
./CPL_eyes/sick6.png 0.25s
./CPL_eyes/sick24.png 0.25s
./CPL_eyes/sick18.png 0.25s
./CPL_eyes/sick12.png 0.25s
./CPL_eyes/sick7.png 0.25s
./CPL_eyes/sick20.png 0.25s
./CPL_eyes/sick19.png 0.25s
./CPL_eyes/sick7.png 0.25s
end seq

start seq sick2h
./CPL_eyes/sick7.png 0.25s
./CPL_eyes/sick19.png 0.25s
./CPL_eyes/sick20.png 0.25s
./CPL_eyes/sick7.png 0.25s
./CPL_eyes/sick12.png 0.25s
./CPL_eyes/sick18.png 0.25s
./CPL_eyes/sick24.png 0.25s
./CPL_eyes/sick6.png 0.25s
./CPL_eyes/sick11.png 0.25s
./CPL_eyes/sick17.png 0.25s
./CPL_eyes/sick23.png 0.25s
./CPL_eyes/sick5.png 0.25s
./CPL_eyes/sick10.png 0.25s
./CPL_eyes/sick16.png 0.25s
./CPL_eyes/sick22.png 0.25s
./CPL_eyes/sick4.png 0.25s
./CPL_eyes/sick9.png 0.25s
./CPL_eyes/sick15.png 0.25s
./CPL_eyes/sick21.png 0.25s
./CPL_eyes/sick3.png 0.25s
./CPL_eyes/sick8.png 0.25s
./CPL_eyes/sick14.png 0.25s
./CPL_eyes/sick20.png 0.25s
./CPL_eyes/sick2.png 0.25s
./CPL_eyes/sick7.png 0.25s
./CPL_eyes/sick13.png 0.25s
./CPL_eyes/sick19.png 0.25s
./CPL_eyes/sick1.png 0.25s
end seq

start seq sick3h
./CPL_eyes/sick25.png 0.25s
./CPL_eyes/sick7.png 0.25s
./CPL_eyes/sick13.png 0.25s
./CPL_eyes/sick19.png 0.25s
./CPL_eyes/sick1.png 0.25s
./CPL_eyes/sick26.png 0.25s
./CPL_eyes/sick6.png 0.25s
./CPL_eyes/sick24.png 0.25s
./CPL_eyes/sick18.png 0.25s
./CPL_eyes/sick12.png 0.25s
./CPL_eyes/sick27.png 0.25s
./CPL_eyes/sick8.png 0.25s
./CPL_eyes/sick14.png 0.25s
./CPL_eyes/sick20.png 0.25s
./CPL_eyes/sick2.png 0.25s
./CPL_eyes/sick31.png 0.25s
./CPL_eyes/sick12.png 0.25s
./CPL_eyes/sick18.png 0.25s
./CPL_eyes/sick24.png 0.25s
./CPL_eyes/sick6.png 0.25s
./CPL_eyes/sick32.png 0.25s
./CPL_eyes/sick2.png 0.25s
./CPL_eyes/sick20.png 0.25s
./CPL_eyes/sick14.png 0.25s
./CPL_eyes/sick8.png 0.25s
end seq

start seq sick4h
./CPL_eyes/sick28.png 0.25s
./CPL_eyes/sick25.png 0.25s
./CPL_eyes/sick29.png 0.25s
./CPL_eyes/sick26.png 0.25s
./CPL_eyes/sick8.png 0.25s
./CPL_eyes/sick14.png 0.25s
./CPL_eyes/sick20.png 0.25s
./CPL_eyes/sick2.png 0.25s
./CPL_eyes/sick30.png 0.25s
./CPL_eyes/sick32.png 0.25s
./CPL_eyes/sick31.png 0.25s
./CPL_eyes/sick11.png 0.25s
./CPL_eyes/sick17.png 0.25s
./CPL_eyes/sick23.png 0.25s
./CPL_eyes/sick5.png 0.25s
end seq

#####

start seq normal1
./CPL_eyes/normal6.png 1s
./CPL_eyes/normal7.png 1s
./CPL_eyes/happy1.png 1s
./CPL_eyes/normal8.png 1s
./CPL_eyes/normal9.png 1s
./CPL_eyes/normal1.png 1s
./CPL_eyes/happy2.png 1s
./CPL_eyes/normal1.png 1s
./CPL_eyes/happy4.png 1s
./CPL_eyes/happy3.png 1s
./CPL_eyes/happy5.png 1s
./CPL_eyes/happy6.png 1s
./CPL_eyes/normal2.png 1s
./CPL_eyes/normal3.png 1s
./CPL_eyes/normal4.png 1s
./CPL_eyes/happy7.png 1s
./CPL_eyes/normal5.png 1s
./CPL_eyes/normal6.png 1s
./CPL_eyes/normal7.png 1s
./CPL_eyes/normal8.png 1s
./CPL_eyes/happy6.png 1s
end seq

start seq normal2
./CPL_eyes/normal1.png 1s
./CPL_eyes/normal3.png 1s
./CPL_eyes/happy7.png 1s
./CPL_eyes/normal2.png 1s
./CPL_eyes/normal4.png 1s
./CPL_eyes/normal5.png 1s
./CPL_eyes/happy6.png 1s
./CPL_eyes/normal6.png 1s
./CPL_eyes/normal7.png 1s
./CPL_eyes/normal8.png 1s
./CPL_eyes/happy5.png 1s
./CPL_eyes/normal9.png 1s
./CPL_eyes/normal1.png 1s
./CPL_eyes/happy4.png 1s
./CPL_eyes/happy3.png 1s
./CPL_eyes/normal1.png 1s
./CPL_eyes/happy2.png 1s
./CPL_eyes/happy1.png 1s
end seq

start seq normal3
./CPL_eyes/normal1.png 1s
./CPL_eyes/halfblink1.png 1s
./CPL_eyes/blink.png 1s
./CPL_eyes/halfblink2.png 1s
./CPL_eyes/normal2.png 1s
./CPL_eyes/normal3.png 1s
./CPL_eyes/normal4.png 1s
./CPL_eyes/halfblink4.png 1s
./CPL_eyes/blink.png 1s
./CPL_eyes/halfblink5.png 1s
./CPL_eyes/normal5.png 1s
./CPL_eyes/normal6.png 1s
./CPL_eyes/normal7.png 1s
./CPL_eyes/halfblink7.png 1s
./CPL_eyes/blink.png 1s
./CPL_eyes/halfblink8.png 1s
./CPL_eyes/normal8.png 1s
./CPL_eyes/normal9.png 1s
./CPL_eyes/normal1.png 1s
./CPL_eyes/normal1.png 1s
end seq

start seq normal4
./CPL_eyes/normal2.png 1s
./CPL_eyes/halfblink8.png 0.5s
./CPL_eyes/blink.png 0.5s
./CPL_eyes/halfblink2.png 0.5s
./CPL_eyes/normal3.png 1s
./CPL_eyes/normal4.png 1s
./CPL_eyes/normal5.png 1s
./CPL_eyes/halfblink5.png 0.5s
./CPL_eyes/blink.png 0.5s
./CPL_eyes/halfblink6.png 0.5s
./CPL_eyes/normal6.png 1s
./CPL_eyes/normal7.png 1s
./CPL_eyes/halfblink6.png 0.5s
./CPL_eyes/blink.png 0.5s
./CPL_eyes/halfblink8.png 0.5s
./CPL_eyes/normal8.png 1s
end seq

start seq normal5
./CPL_eyes/normal5.png 1s
./CPL_eyes/normal6.png 1s
./CPL_eyes/normal7.png 1s
./CPL_eyes/halfblink7.png 0.5s
./CPL_eyes/blink.png 0.5s
./CPL_eyes/halfblink8.png 0.5s
./CPL_eyes/normal8.png 1s
./CPL_eyes/normal9.png 1s
./CPL_eyes/normal1.png 1s
./CPL_eyes/halfblink10.png 0.5s
./CPL_eyes/blink.png 0.5s
./CPL_eyes/halfblink1.png 0.5s
./CPL_eyes/normal1.png 1s
./CPL_eyes/normal2.png 1s
./CPL_eyes/normal3.png 1s
./CPL_eyes/halfblink3.png 0.5s
./CPL_eyes/blink.png 0.5s
./CPL_eyes/halfblink6.png 0.5s
./CPL_eyes/normal6.png 1s
end seq

####

start seq sick1
./CPL_eyes/sick1.png 1s
./CPL_eyes/sick19.png 1s
./CPL_eyes/sick13.png 1s
./CPL_eyes/sick7.png 1s
./CPL_eyes/sick2.png 1s
./CPL_eyes/sick20.png 1s
./CPL_eyes/sick14.png 1s
./CPL_eyes/sick8.png 1s
./CPL_eyes/sick3.png 1s
./CPL_eyes/sick21.png 1s
./CPL_eyes/sick15.png 1s
./CPL_eyes/sick9.png 1s
./CPL_eyes/sick4.png 1s
./CPL_eyes/sick22.png 1s
./CPL_eyes/sick16.png 1s
./CPL_eyes/sick10.png 1s
./CPL_eyes/sick5.png 1s
./CPL_eyes/sick23.png 1s
./CPL_eyes/sick17.png 1s
./CPL_eyes/sick11.png 1s
./CPL_eyes/sick6.png 1s
./CPL_eyes/sick24.png 1s
./CPL_eyes/sick18.png 1s
./CPL_eyes/sick12.png 1s
./CPL_eyes/sick7.png 1s
./CPL_eyes/sick20.png 1s
./CPL_eyes/sick19.png 1s
./CPL_eyes/sick7.png 1s
end seq

start seq sick2
./CPL_eyes/sick7.png 1s
./CPL_eyes/sick19.png 1s
./CPL_eyes/sick20.png 1s
./CPL_eyes/sick7.png 1s
./CPL_eyes/sick12.png 1s
./CPL_eyes/sick18.png 1s
./CPL_eyes/sick24.png 1s
./CPL_eyes/sick6.png 1s
./CPL_eyes/sick11.png 1s
./CPL_eyes/sick17.png 1s
./CPL_eyes/sick23.png 1s
./CPL_eyes/sick5.png 1s
./CPL_eyes/sick10.png 1s
./CPL_eyes/sick16.png 1s
./CPL_eyes/sick22.png 1s
./CPL_eyes/sick4.png 1s
./CPL_eyes/sick9.png 1s
./CPL_eyes/sick15.png 1s
./CPL_eyes/sick21.png 1s
./CPL_eyes/sick3.png 1s
./CPL_eyes/sick8.png 1s
./CPL_eyes/sick14.png 1s
./CPL_eyes/sick20.png 1s
./CPL_eyes/sick2.png 1s
./CPL_eyes/sick7.png 1s
./CPL_eyes/sick13.png 1s
./CPL_eyes/sick19.png 1s
./CPL_eyes/sick1.png 1s
end seq

start seq sick3
./CPL_eyes/sick25.png 1s
./CPL_eyes/sick7.png 1s
./CPL_eyes/sick13.png 1s
./CPL_eyes/sick19.png 1s
./CPL_eyes/sick1.png 1s
./CPL_eyes/sick26.png 1s
./CPL_eyes/sick6.png 1s
./CPL_eyes/sick24.png 1s
./CPL_eyes/sick18.png 1s
./CPL_eyes/sick12.png 1s
./CPL_eyes/sick27.png 1s
./CPL_eyes/sick8.png 1s
./CPL_eyes/sick14.png 1s
./CPL_eyes/sick20.png 1s
./CPL_eyes/sick2.png 1s
./CPL_eyes/sick31.png 1s
./CPL_eyes/sick12.png 1s
./CPL_eyes/sick18.png 1s
./CPL_eyes/sick24.png 1s
./CPL_eyes/sick6.png 1s
./CPL_eyes/sick32.png 1s
./CPL_eyes/sick2.png 1s
./CPL_eyes/sick20.png 1s
./CPL_eyes/sick14.png 1s
./CPL_eyes/sick8.png 1s
end seq

start seq sick4
./CPL_eyes/sick28.png 1s
./CPL_eyes/sick25.png 1s
./CPL_eyes/sick29.png 1s
./CPL_eyes/sick26.png 1s
./CPL_eyes/sick8.png 1s
./CPL_eyes/sick14.png 1s
./CPL_eyes/sick20.png 1s
./CPL_eyes/sick2.png 1s
./CPL_eyes/sick30.png 1s
./CPL_eyes/sick32.png 1s
./CPL_eyes/sick31.png 1s
./CPL_eyes/sick11.png 1s
./CPL_eyes/sick17.png 1s
./CPL_eyes/sick23.png 1s
./CPL_eyes/sick5.png 1s
end seq

####

start seq dead1
./CPL_eyes/dead1.png 2s
./CPL_eyes/dead12.png 2s
./CPL_eyes/dead1.png 2s
./CPL_eyes/dead12.png 2s
./CPL_eyes/dead2.png 2s
./CPL_eyes/dead1.png 2s
./CPL_eyes/dead2.png 2s
end seq

start seq dead2
./CPL_eyes/dead2.png 2s
./CPL_eyes/dead3.png 2s
./CPL_eyes/dead4.png 2s
./CPL_eyes/dead5.png 2s
./CPL_eyes/dead6.png 2s
end seq

start seq dead3
./CPL_eyes/dead13.png 2s
./CPL_eyes/dead7.png 2s
./CPL_eyes/dead8.png 2s
./CPL_eyes/dead9.png 2s
./CPL_eyes/dead10.png 2s
./CPL_eyes/dead11.png 2s
end seq

####

start seq eyebeam1
./CPL_eyes/eyebeam1.png 0.25s
./CPL_eyes/eyebeam2.png 0.25s
./CPL_eyes/eyebeam3.png 0.25s
./CPL_eyes/eyebeam4.png 0.25s
./CPL_eyes/eyebeam5.png 0.25s
./CPL_eyes/eyebeam6.png 0.25s
./CPL_eyes/eyebeam7.png 0.25s
./CPL_eyes/eyebeam8.png 0.25s
./CPL_eyes/eyebeam9.png 0.25s
end seq

start seq eyebeam2
./CPL_eyes/eyebeam11.png 1s
./CPL_eyes/eyebeam12.png 1s
./CPL_eyes/eyebeam13.png 1s
./CPL_eyes/eyebeam14.png 1s
end seq

start seq eyebeam3
./CPL_eyes/eyebeam14.png 1s
./CPL_eyes/eyebeam15.png 1s
./CPL_eyes/eyebeam16.png 1s
end seq

####

start seq food
./CPL_eyes/food1.png 1s
./CPL_eyes/food2.png 1s
./CPL_eyes/food3.png 1s
./CPL_eyes/food4.png 1s
./CPL_eyes/food5.png 1s
./CPL_eyes/food6.png 1s
./CPL_eyes/food7.png 1s
./CPL_eyes/food8.png 1s
./CPL_eyes/food9.png 1s
./CPL_eyes/food10.png 1s
./CPL_eyes/food11.png 1s
./CPL_eyes/food12.png 1s
end seq

#########################################################################################################

start seq hbdh
./hbdh.png 5s
end seq

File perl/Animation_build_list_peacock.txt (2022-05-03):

start set 0
precon1
sleep1
sleepy1
precon1
sleepy2
precon2
precon1
sleep1
sleepy1
precon1
sleepy2
precon2
precon1
sleep1
sleepy1
precon1
end set

start set 1
precon1
sleep1
sleepy1
precon1
sleepy2
precon2
precon1
sleep1
sleepy1
precon1
sleepy2
precon2
precon1
sleep1
sleepy1
precon1
end set

start set 2
hyper1
hyper1
crazyeyes1
hyper2
hyper2
crazyeyes2 
hyper1
hyper1
crazyeyes3
hyper2
hyper2
crazyeyes4
hyper1
crazyeyes3
hyper2
crazyeyes2
end set

start set 3
hyper1
hyper1
sick1h
crazyeyes1
hyper2
hyper2
sick2h
crazyeyes2 
hyper1
sick3h
crazyeyes3
hyper2
sick4h
sick1h
crazyeyes2
sick2h
end set

start set 4
normal1
normal2
normal3
normal4
normal5
normal3
normal1
normal5
normal2
normal4
normal2
normal3
normal4
normal5
normal1
normal3
end set

start set 5
normal1
sick1
normal2
sick2
normal3
sick3
normal4
sick4
normal5
sick4
normal4
sick3
normal3
sick2
normal2
sick1
end set

start set 6
sleep1
sleepy1
sleepy2
sleep1
sleepy1
sleepy2
sleep1
sleepy1
sleep1
sleepy1
sleepy2
sleep1
sleepy1
sleepy2
sleep1
sleepy1
end set

start set 7
sleep1
sick1
sleepy2
sick2
sleepy1
sick3
sleep1
sick4
sleep1
sick4
sleepy2
sick3
sleepy1
sick2
sleep1
sick1
end set

start set 8
dead1
dead2
dead3
dead3
dead2
dead1
dead1
dead2
dead3
dead3
dead2
dead1
dead2
dead3
dead1
dead2
end set

start set 9
dead1
dead2
dead3
dead3
dead2
dead1
dead1
dead2
dead3
dead3
dead2
dead1
dead2
dead3
dead1
dead2
end set

start set 10
eyebeam1
eyebeam1
eyebeam2
eyebeam2
eyebeam3
eyebeam3
eyebeam1
eyebeam1
eyebeam2
eyebeam2
eyebeam3
eyebeam3
eyebeam2
eyebeam2
eyebeam3
eyebeam3
end set

start set 11
eyebeam1
eyebeam1
eyebeam2
eyebeam2
eyebeam3
eyebeam3
eyebeam1
eyebeam1
eyebeam2
eyebeam2
eyebeam3
eyebeam3
eyebeam2
eyebeam2
eyebeam3
eyebeam3
end set

start set 12
food
food
food
food
food
food
food
food
food
food
food
food
food
food
food
food
end set

start set 13
hbdh
hbdh
hbdh
hbdh
hbdh
hbdh
hbdh
hbdh
hbdh
hbdh
hbdh
hbdh
hbdh
hbdh
hbdh
hbdh
end set

##################################################################################################

start seq precon1
./P_eyes/sleep1.png 2s
./P_eyes/sleep7.png 1s
./P_eyes/sleep2.png 2s
./P_eyes/sleep10.png 1s
./P_eyes/sleep3.png 2s
./P_eyes/sleep9.png 1s
./P_eyes/sleep4.png 2s
./P_eyes/sleep8.png 1s
./P_eyes/sleep11.png 2s
./P_eyes/sleep12.png 1s
end seq

start seq sleep1
./P_eyes/sleep13.png 1s
./P_eyes/sleep14.png 1s
./P_eyes/sleep15.png 1s
./P_eyes/sleep16.png 1s
./P_eyes/sleep17.png 1s
./P_eyes/sleep18.png 1s
./P_eyes/sleep13.png 1s
./P_eyes/sleep14.png 1s
./P_eyes/sleep15.png 1s
./P_eyes/sleep16.png 1s
./P_eyes/sleep17.png 1s
./P_eyes/sleep18.png 1s
end seq

start seq sleepy1
./P_eyes/sleep1.png 1s
./P_eyes/sleep2.png 1s
./P_eyes/sleep3.png 1s
./P_eyes/halfblink1.png 1s
./P_eyes/halfblink2.png 1s
./P_eyes/halfblink4.png 1s
./P_eyes/sleep4.png 1s
./P_eyes/sleep5.png 1s
./P_eyes/sleep6.png 1s
end seq

start seq sleepy2
./P_eyes/sleep7.png 1s
./P_eyes/sleep8.png 1s
./P_eyes/halfblink5.png 1s
./P_eyes/halfblink6.png 1s
./P_eyes/halfblink7.png 1s
./P_eyes/sleep9.png 1s
./P_eyes/sleep10.png 1s
./P_eyes/sleep11.png 1s
./P_eyes/sleep12.png 1s
end seq

start seq precon2
./P_eyes/precon1.png 1s
./P_eyes/precon2.png 1s
./P_eyes/precon3.png 1s
./P_eyes/precon4.png 1s
./P_eyes/precon5.png 1s
./P_eyes/precon6.png 1s
./P_eyes/precon7.png 1s
./P_eyes/precon8.png 1s
./P_eyes/precon1.png 1s
./P_eyes/precon2.png 1s
./P_eyes/precon3.png 1s
./P_eyes/precon4.png 1s
./P_eyes/precon5.png 1s
./P_eyes/precon6.png 1s
./P_eyes/precon7.png 1s
./P_eyes/precon8.png 1s
end seq

###########

start seq hyper1
./P_eyes/hyper1.png 0.25s
./P_eyes/hyper2.png 0.25s
./P_eyes/hyper3.png 0.25s
./P_eyes/hyper4.png 0.25s
./P_eyes/hyper5.png 0.25s
./P_eyes/hyper6.png 0.25s
./P_eyes/hyper7.png 0.25s
./P_eyes/hyper8.png 0.25s
./P_eyes/hyper9.png 0.25s
./P_eyes/hyper10.png 0.25s
./P_eyes/hyper11.png 0.25s
end seq 

start seq hyper2
./P_eyes/hyper11.png 0.25s
./P_eyes/hyper10.png 0.25s
./P_eyes/hyper9.png 0.25s
./P_eyes/hyper8.png 0.25s
./P_eyes/hyper7.png 0.25s
./P_eyes/hyper6.png 0.25s
./P_eyes/hyper5.png 0.25s
./P_eyes/hyper6.png 0.25s
./P_eyes/hyper5.png 0.25s
./P_eyes/hyper4.png 0.25s
./P_eyes/hyper3.png 0.25s
./P_eyes/hyper2.png 0.25s
./P_eyes/hyper1.png 0.25s
end seq

start seq crazyeyes1
./P_eyes/hyper1.png 0.25s
./P_eyes/normal7.png 0.25s
./P_eyes/normal7.png 0.25s
./P_eyes/hyper2.png 0.25s
./P_eyes/normal8.png 0.25s
./P_eyes/normal5.png 0.25s
./P_eyes/hyper3.png 0.25s
./P_eyes/normal6.png 0.25s
./P_eyes/normal5.png 0.25s
./P_eyes/hyper4.png 0.25s
./P_eyes/normal5.png 0.25s
./P_eyes/normal4.png 0.25s
./P_eyes/hyper5.png 0.25s
./P_eyes/normal4.png 0.25s
./P_eyes/normal1.png 0.25s
end seq

start seq crazyeyes2
./P_eyes/normal1.png 0.25s
./P_eyes/normal4.png 0.25s
./P_eyes/hyper5.png 0.25s
./P_eyes/normal4.png 0.25s
./P_eyes/normal5.png 0.25s
./P_eyes/hyper4.png 0.25s
./P_eyes/normal5.png 0.25s
./P_eyes/normal6.png 0.25s
./P_eyes/hyper3.png 0.25s
./P_eyes/normal5.png 0.25s
./P_eyes/normal8.png 0.25s
./P_eyes/hyper2.png 0.25s
./P_eyes/normal7.png 0.25s
./P_eyes/normal7.png 0.25s
./P_eyes/hyper1.png 0.25s
end seq

start seq crazyeyes3
./P_eyes/hyper1.png 0.25s
./P_eyes/normal7.png 0.25s
./P_eyes/hyper2.png 0.25s
./P_eyes/normal5.png 0.25s
./P_eyes/hyper3.png 0.25s
./P_eyes/normal5.png 0.25s
./P_eyes/hyper4.png 0.25s
./P_eyes/normal4.png 0.25s
./P_eyes/hyper5.png 0.25s
./P_eyes/normal1.png 0.25s
end seq

start seq crazyeyes4
./P_eyes/normal1.png 0.25s
./P_eyes/hyper5.png 0.25s
./P_eyes/normal4.png 0.25s
./P_eyes/hyper4.png 0.25s
./P_eyes/normal5.png 0.25s
./P_eyes/hyper3.png 0.25s
./P_eyes/normal5.png 0.25s
./P_eyes/hyper2.png 0.25s
./P_eyes/normal7.png 0.25s
./P_eyes/hyper1.png 0.25s
end seq

start seq sick1h
./P_eyes/sick1.png 0.25s
./P_eyes/sick19.png 0.25s
./P_eyes/sick13.png 0.25s
./P_eyes/sick7.png 0.25s
./P_eyes/sick2.png 0.25s
./P_eyes/sick20.png 0.25s
./P_eyes/sick14.png 0.25s
./P_eyes/sick8.png 0.25s
./P_eyes/sick3.png 0.25s
./P_eyes/sick21.png 0.25s
./P_eyes/sick15.png 0.25s
./P_eyes/sick9.png 0.25s
./P_eyes/sick4.png 0.25s
./P_eyes/sick22.png 0.25s
./P_eyes/sick16.png 0.25s
./P_eyes/sick10.png 0.25s
./P_eyes/sick5.png 0.25s
./P_eyes/sick23.png 0.25s
./P_eyes/sick17.png 0.25s
./P_eyes/sick11.png 0.25s
./P_eyes/sick6.png 0.25s
./P_eyes/sick24.png 0.25s
./P_eyes/sick18.png 0.25s
./P_eyes/sick12.png 0.25s
./P_eyes/sick7.png 0.25s
./P_eyes/sick20.png 0.25s
./P_eyes/sick19.png 0.25s
./P_eyes/sick7.png 0.25s
end seq

start seq sick2h
./P_eyes/sick7.png 0.25s
./P_eyes/sick19.png 0.25s
./P_eyes/sick20.png 0.25s
./P_eyes/sick7.png 0.25s
./P_eyes/sick12.png 0.25s
./P_eyes/sick18.png 0.25s
./P_eyes/sick24.png 0.25s
./P_eyes/sick6.png 0.25s
./P_eyes/sick11.png 0.25s
./P_eyes/sick17.png 0.25s
./P_eyes/sick23.png 0.25s
./P_eyes/sick5.png 0.25s
./P_eyes/sick10.png 0.25s
./P_eyes/sick16.png 0.25s
./P_eyes/sick22.png 0.25s
./P_eyes/sick4.png 0.25s
./P_eyes/sick9.png 0.25s
./P_eyes/sick15.png 0.25s
./P_eyes/sick21.png 0.25s
./P_eyes/sick3.png 0.25s
./P_eyes/sick8.png 0.25s
./P_eyes/sick14.png 0.25s
./P_eyes/sick20.png 0.25s
./P_eyes/sick2.png 0.25s
./P_eyes/sick7.png 0.25s
./P_eyes/sick13.png 0.25s
./P_eyes/sick19.png 0.25s
./P_eyes/sick1.png 0.25s
end seq

start seq sick3h
./P_eyes/sick25.png 0.25s
./P_eyes/sick7.png 0.25s
./P_eyes/sick13.png 0.25s
./P_eyes/sick19.png 0.25s
./P_eyes/sick1.png 0.25s
./P_eyes/sick26.png 0.25s
./P_eyes/sick6.png 0.25s
./P_eyes/sick24.png 0.25s
./P_eyes/sick18.png 0.25s
./P_eyes/sick12.png 0.25s
./P_eyes/sick27.png 0.25s
./P_eyes/sick8.png 0.25s
./P_eyes/sick14.png 0.25s
./P_eyes/sick20.png 0.25s
./P_eyes/sick2.png 0.25s
./P_eyes/sick31.png 0.25s
./P_eyes/sick12.png 0.25s
./P_eyes/sick18.png 0.25s
./P_eyes/sick24.png 0.25s
./P_eyes/sick6.png 0.25s
./P_eyes/sick32.png 0.25s
./P_eyes/sick2.png 0.25s
./P_eyes/sick20.png 0.25s
./P_eyes/sick14.png 0.25s
./P_eyes/sick8.png 0.25s
end seq

start seq sick4h
./P_eyes/sick28.png 0.25s
./P_eyes/sick25.png 0.25s
./P_eyes/sick29.png 0.25s
./P_eyes/sick26.png 0.25s
./P_eyes/sick8.png 0.25s
./P_eyes/sick14.png 0.25s
./P_eyes/sick20.png 0.25s
./P_eyes/sick2.png 0.25s
./P_eyes/sick30.png 0.25s
./P_eyes/sick32.png 0.25s
./P_eyes/sick31.png 0.25s
./P_eyes/sick11.png 0.25s
./P_eyes/sick17.png 0.25s
./P_eyes/sick23.png 0.25s
./P_eyes/sick5.png 0.25s
end seq

#####

start seq normal1
./P_eyes/normal6.png 1s
./P_eyes/normal7.png 1s
./P_eyes/happy1.png 1s
./P_eyes/normal8.png 1s
./P_eyes/normal9.png 1s
./P_eyes/normal1.png 1s
./P_eyes/happy2.png 1s
./P_eyes/normal1.png 1s
./P_eyes/happy4.png 1s
./P_eyes/happy3.png 1s
./P_eyes/happy5.png 1s
./P_eyes/happy6.png 1s
./P_eyes/normal2.png 1s
./P_eyes/normal3.png 1s
./P_eyes/normal4.png 1s
./P_eyes/happy7.png 1s
./P_eyes/normal5.png 1s
./P_eyes/normal6.png 1s
./P_eyes/normal7.png 1s
./P_eyes/normal8.png 1s
./P_eyes/happy6.png 1s
end seq

start seq normal2
./P_eyes/normal1.png 1s
./P_eyes/normal3.png 1s
./P_eyes/happy7.png 1s
./P_eyes/normal2.png 1s
./P_eyes/normal4.png 1s
./P_eyes/normal5.png 1s
./P_eyes/happy6.png 1s
./P_eyes/normal6.png 1s
./P_eyes/normal7.png 1s
./P_eyes/normal8.png 1s
./P_eyes/happy5.png 1s
./P_eyes/normal9.png 1s
./P_eyes/normal1.png 1s
./P_eyes/happy4.png 1s
./P_eyes/happy3.png 1s
./P_eyes/normal1.png 1s
./P_eyes/happy2.png 1s
./P_eyes/happy1.png 1s
end seq

start seq normal3
./P_eyes/normal1.png 1s
./P_eyes/halfblink1.png 1s
./P_eyes/blink.png 1s
./P_eyes/halfblink2.png 1s
./P_eyes/normal2.png 1s
./P_eyes/normal3.png 1s
./P_eyes/normal4.png 1s
./P_eyes/halfblink4.png 1s
./P_eyes/blink.png 1s
./P_eyes/halfblink5.png 1s
./P_eyes/normal5.png 1s
./P_eyes/normal6.png 1s
./P_eyes/normal7.png 1s
./P_eyes/halfblink7.png 1s
./P_eyes/blink.png 1s
./P_eyes/halfblink8.png 1s
./P_eyes/normal8.png 1s
./P_eyes/normal9.png 1s
./P_eyes/normal1.png 1s
./P_eyes/normal1.png 1s
end seq

start seq normal4
./P_eyes/normal2.png 1s
./P_eyes/halfblink8.png 0.5s
./P_eyes/blink.png 0.5s
./P_eyes/halfblink2.png 0.5s
./P_eyes/normal3.png 1s
./P_eyes/normal4.png 1s
./P_eyes/normal5.png 1s
./P_eyes/halfblink5.png 0.5s
./P_eyes/blink.png 0.5s
./P_eyes/halfblink6.png 0.5s
./P_eyes/normal6.png 1s
./P_eyes/normal7.png 1s
./P_eyes/halfblink6.png 0.5s
./P_eyes/blink.png 0.5s
./P_eyes/halfblink8.png 0.5s
./P_eyes/normal8.png 1s
end seq

start seq normal5
./P_eyes/normal5.png 1s
./P_eyes/normal6.png 1s
./P_eyes/normal7.png 1s
./P_eyes/halfblink7.png 0.5s
./P_eyes/blink.png 0.5s
./P_eyes/halfblink8.png 0.5s
./P_eyes/normal8.png 1s
./P_eyes/normal9.png 1s
./P_eyes/normal1.png 1s
./P_eyes/halfblink10.png 0.5s
./P_eyes/blink.png 0.5s
./P_eyes/halfblink1.png 0.5s
./P_eyes/normal1.png 1s
./P_eyes/normal2.png 1s
./P_eyes/normal3.png 1s
./P_eyes/halfblink3.png 0.5s
./P_eyes/blink.png 0.5s
./P_eyes/halfblink6.png 0.5s
./P_eyes/normal6.png 1s
end seq

####

start seq sick1
./P_eyes/sick1.png 1s
./P_eyes/sick19.png 1s
./P_eyes/sick13.png 1s
./P_eyes/sick7.png 1s
./P_eyes/sick2.png 1s
./P_eyes/sick20.png 1s
./P_eyes/sick14.png 1s
./P_eyes/sick8.png 1s
./P_eyes/sick3.png 1s
./P_eyes/sick21.png 1s
./P_eyes/sick15.png 1s
./P_eyes/sick9.png 1s
./P_eyes/sick4.png 1s
./P_eyes/sick22.png 1s
./P_eyes/sick16.png 1s
./P_eyes/sick10.png 1s
./P_eyes/sick5.png 1s
./P_eyes/sick23.png 1s
./P_eyes/sick17.png 1s
./P_eyes/sick11.png 1s
./P_eyes/sick6.png 1s
./P_eyes/sick24.png 1s
./P_eyes/sick18.png 1s
./P_eyes/sick12.png 1s
./P_eyes/sick7.png 1s
./P_eyes/sick20.png 1s
./P_eyes/sick19.png 1s
./P_eyes/sick7.png 1s
end seq

start seq sick2
./P_eyes/sick7.png 1s
./P_eyes/sick19.png 1s
./P_eyes/sick20.png 1s
./P_eyes/sick7.png 1s
./P_eyes/sick12.png 1s
./P_eyes/sick18.png 1s
./P_eyes/sick24.png 1s
./P_eyes/sick6.png 1s
./P_eyes/sick11.png 1s
./P_eyes/sick17.png 1s
./P_eyes/sick23.png 1s
./P_eyes/sick5.png 1s
./P_eyes/sick10.png 1s
./P_eyes/sick16.png 1s
./P_eyes/sick22.png 1s
./P_eyes/sick4.png 1s
./P_eyes/sick9.png 1s
./P_eyes/sick15.png 1s
./P_eyes/sick21.png 1s
./P_eyes/sick3.png 1s
./P_eyes/sick8.png 1s
./P_eyes/sick14.png 1s
./P_eyes/sick20.png 1s
./P_eyes/sick2.png 1s
./P_eyes/sick7.png 1s
./P_eyes/sick13.png 1s
./P_eyes/sick19.png 1s
./P_eyes/sick1.png 1s
end seq

start seq sick3
./P_eyes/sick25.png 1s
./P_eyes/sick7.png 1s
./P_eyes/sick13.png 1s
./P_eyes/sick19.png 1s
./P_eyes/sick1.png 1s
./P_eyes/sick26.png 1s
./P_eyes/sick6.png 1s
./P_eyes/sick24.png 1s
./P_eyes/sick18.png 1s
./P_eyes/sick12.png 1s
./P_eyes/sick27.png 1s
./P_eyes/sick8.png 1s
./P_eyes/sick14.png 1s
./P_eyes/sick20.png 1s
./P_eyes/sick2.png 1s
./P_eyes/sick31.png 1s
./P_eyes/sick12.png 1s
./P_eyes/sick18.png 1s
./P_eyes/sick24.png 1s
./P_eyes/sick6.png 1s
./P_eyes/sick32.png 1s
./P_eyes/sick2.png 1s
./P_eyes/sick20.png 1s
./P_eyes/sick14.png 1s
./P_eyes/sick8.png 1s
end seq

start seq sick4
./P_eyes/sick28.png 1s
./P_eyes/sick25.png 1s
./P_eyes/sick29.png 1s
./P_eyes/sick26.png 1s
./P_eyes/sick8.png 1s
./P_eyes/sick14.png 1s
./P_eyes/sick20.png 1s
./P_eyes/sick2.png 1s
./P_eyes/sick30.png 1s
./P_eyes/sick32.png 1s
./P_eyes/sick31.png 1s
./P_eyes/sick11.png 1s
./P_eyes/sick17.png 1s
./P_eyes/sick23.png 1s
./P_eyes/sick5.png 1s
end seq

####

start seq dead1
./P_eyes/dead1.png 2s
./P_eyes/dead12.png 2s
./P_eyes/dead1.png 2s
./P_eyes/dead12.png 2s
./P_eyes/dead2.png 2s
./P_eyes/dead1.png 2s
./P_eyes/dead2.png 2s
end seq

start seq dead2
./P_eyes/dead2.png 2s
./P_eyes/dead3.png 2s
./P_eyes/dead4.png 2s
./P_eyes/dead5.png 2s
./P_eyes/dead6.png 2s
end seq

start seq dead3
./P_eyes/dead13.png 2s
./P_eyes/dead7.png 2s
./P_eyes/dead8.png 2s
./P_eyes/dead9.png 2s
./P_eyes/dead10.png 2s
./P_eyes/dead11.png 2s
end seq

####

start seq eyebeam1
./P_eyes/eyebeam1.png 0.25s
./P_eyes/eyebeam2.png 0.25s
./P_eyes/eyebeam3.png 0.25s
./P_eyes/eyebeam4.png 0.25s
./P_eyes/eyebeam5.png 0.25s
./P_eyes/eyebeam6.png 0.25s
./P_eyes/eyebeam7.png 0.25s
./P_eyes/eyebeam8.png 0.25s
./P_eyes/eyebeam9.png 0.25s
end seq

start seq eyebeam2
./P_eyes/eyebeam11.png 1s
./P_eyes/eyebeam12.png 1s
./P_eyes/eyebeam13.png 1s
./P_eyes/eyebeam14.png 1s
end seq

start seq eyebeam3
./P_eyes/eyebeam14.png 1s
./P_eyes/eyebeam15.png 1s
./P_eyes/eyebeam16.png 1s
end seq

####

start seq food
./P_eyes/food1.png 1s
./P_eyes/food2.png 1s
./P_eyes/food3.png 1s
./P_eyes/food4.png 1s
./P_eyes/food5.png 1s
./P_eyes/food6.png 1s
./P_eyes/food7.png 1s
./P_eyes/food8.png 1s
./P_eyes/food9.png 1s
./P_eyes/food10.png 1s
./P_eyes/food11.png 1s
./P_eyes/food12.png 1s
end seq

#########################################################################################################

start seq hbdh
./hbdh.png 5s
end seq

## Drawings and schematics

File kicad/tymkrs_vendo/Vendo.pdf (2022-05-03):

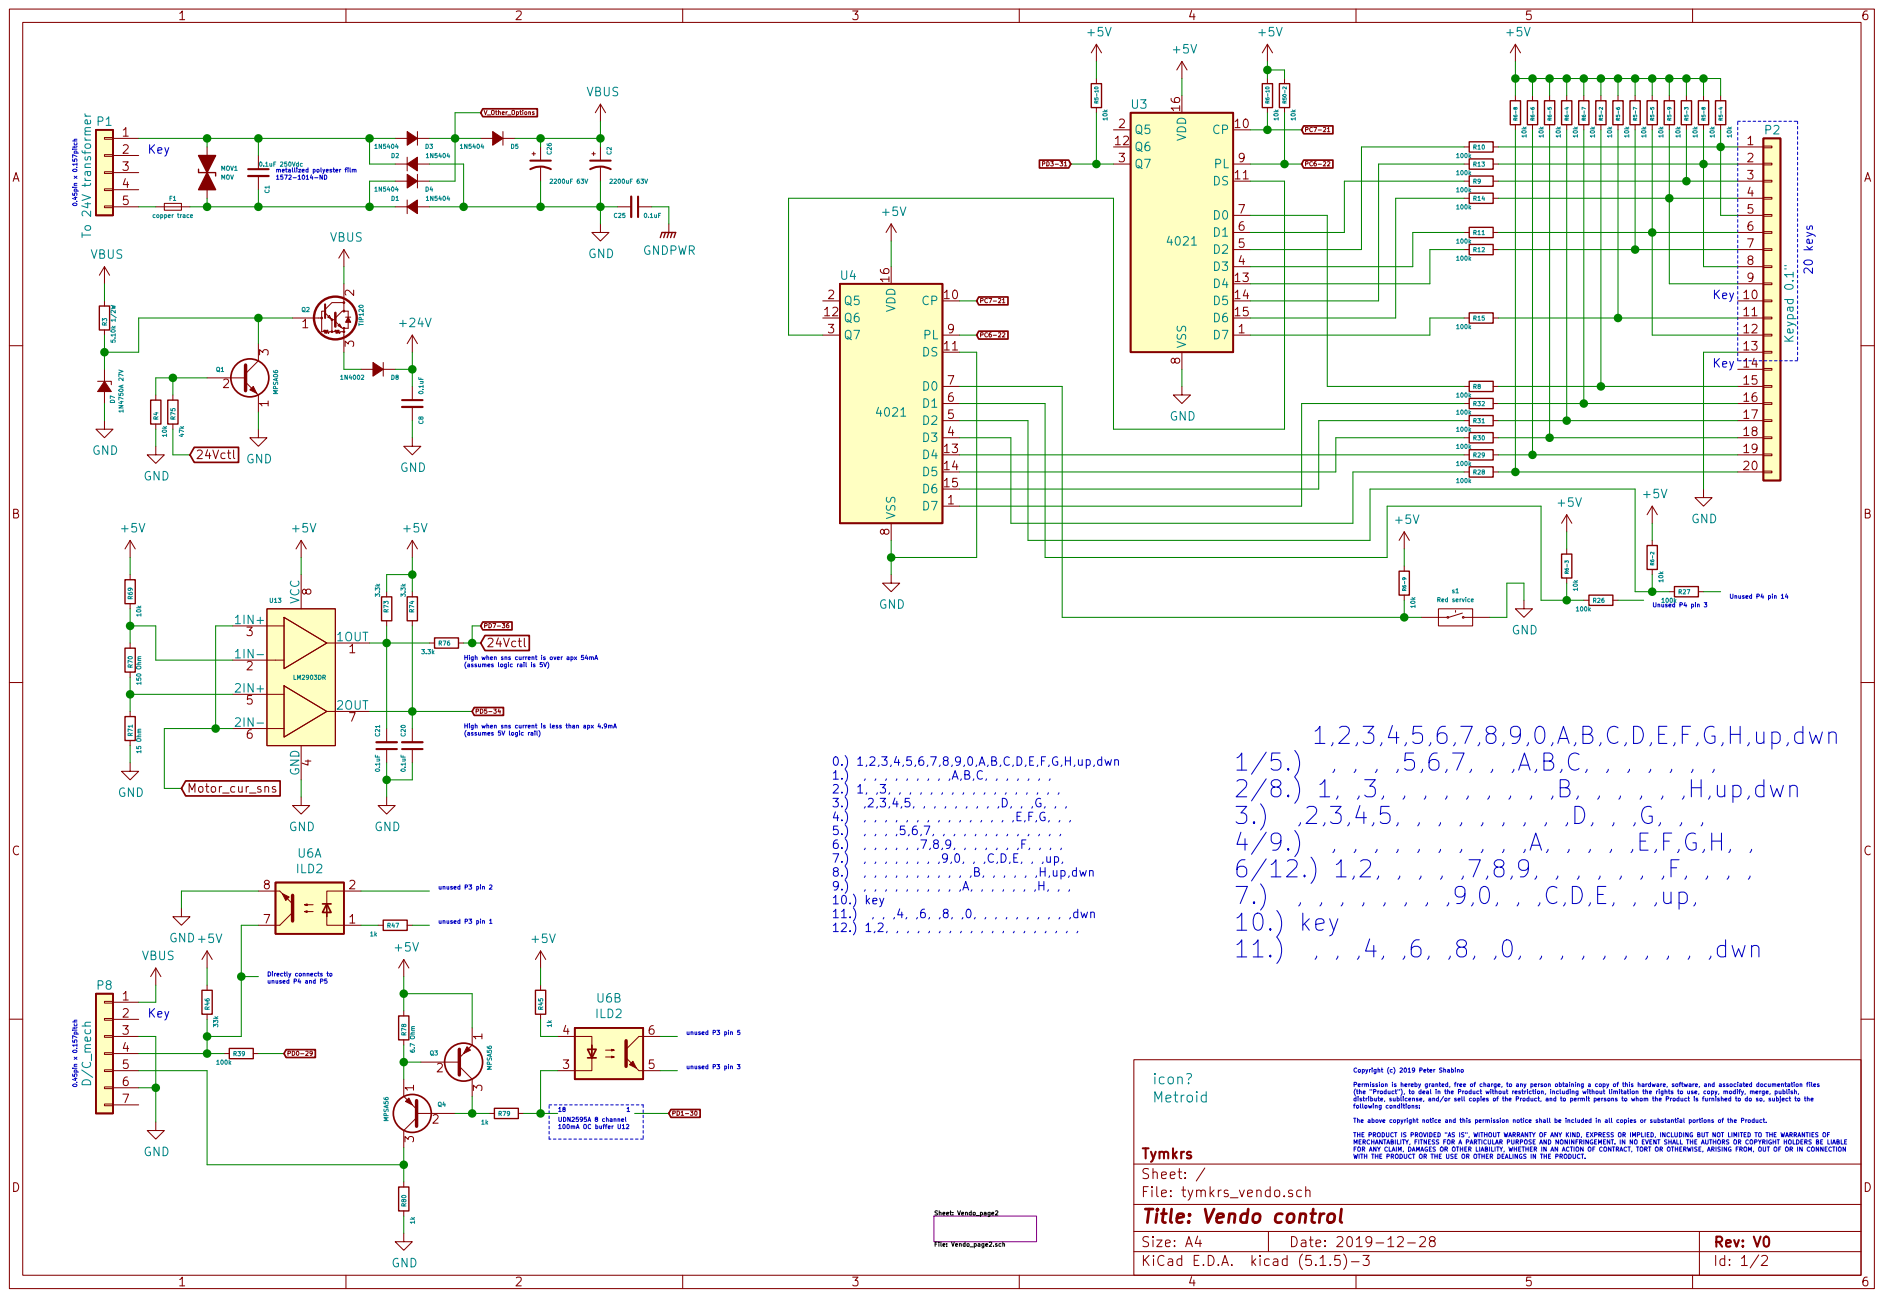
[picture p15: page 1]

10k R6-8 10k | 9 P2 Keypad 0.1" R6-6 4

(assumes logic rail is 5V) Key

100k | 19
R29 | 20

Unused P4 pin 14 1,2,3,4,5,6,7,8,9,0,A,B,C,D,E,F,G,H,up,dwn

1 2OUT | R76

High when sns current is over apx 54mA

High when sns current is less than apx 4.9mA

Directly connects to unused P4 and P5

Copyright (c) 2019 Peter Shabino Permission is hereby granted, free of charge, to any person obtaining a copy of this hardware, software, and associated documentation files (the "Product"), to deal in the Product without restriction, including without limitation the rights to use, copy, modify, merge, publish, distribute, sublicense, and/or sell copies of the Product, and to permit persons to whom the Product is furnished to do so, subject to the

following conditions: The above copyright notice and this permission notice shall be included in all copies or substantial portions of the Product. THE PRODUCT IS PROVIDED "AS IS", WITHOUT WARRANTY OF ANY KIND, EXPRESS OR IMPLIED, INCLUDING BUT NOT LIMITED TO THE WARRANTIES OF MERCHANTABILITY, FITNESS FOR A PARTICULAR PURPOSE AND NONINFRINGEMENT. IN NO EVENT SHALL THE AUTHORS OR COPYRIGHT HOLDERS BE LIABLE FOR ANY CLAIM, DAMAGES OR OTHER LIABILITY, WHETHER IN AN ACTION OF CONTRACT, TORT OR OTHERWISE, ARISING FROM, OUT OF OR IN CONNECTION WITH THE PRODUCT OR THE USE OR OTHER DEALINGS IN THE PRODUCT.

File: tymkrs_vendo.sch Sheet: / Tymkrs

Id: 1/2 Title: Vendo control

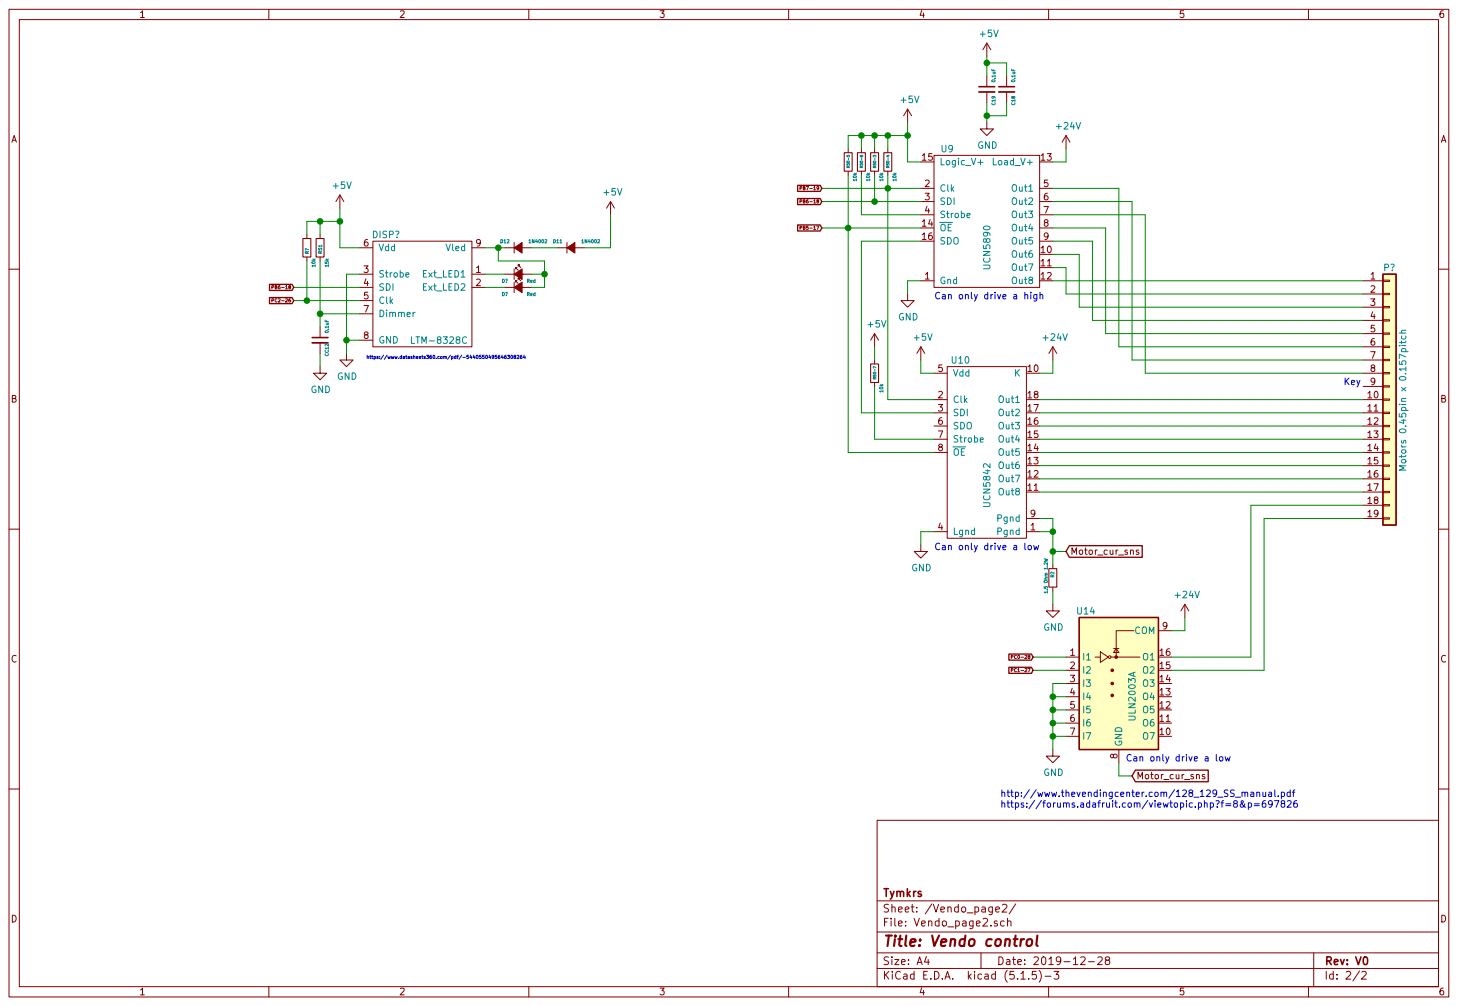
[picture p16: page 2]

Can only drive a high

Can only drive a low

https://forums.adafruit.com/viewtopic.php?f=8&p=697826

Sheet: /Vendo_page2/
File: Vendo_page2.sch
Id: 2/2 Title: Vendo control

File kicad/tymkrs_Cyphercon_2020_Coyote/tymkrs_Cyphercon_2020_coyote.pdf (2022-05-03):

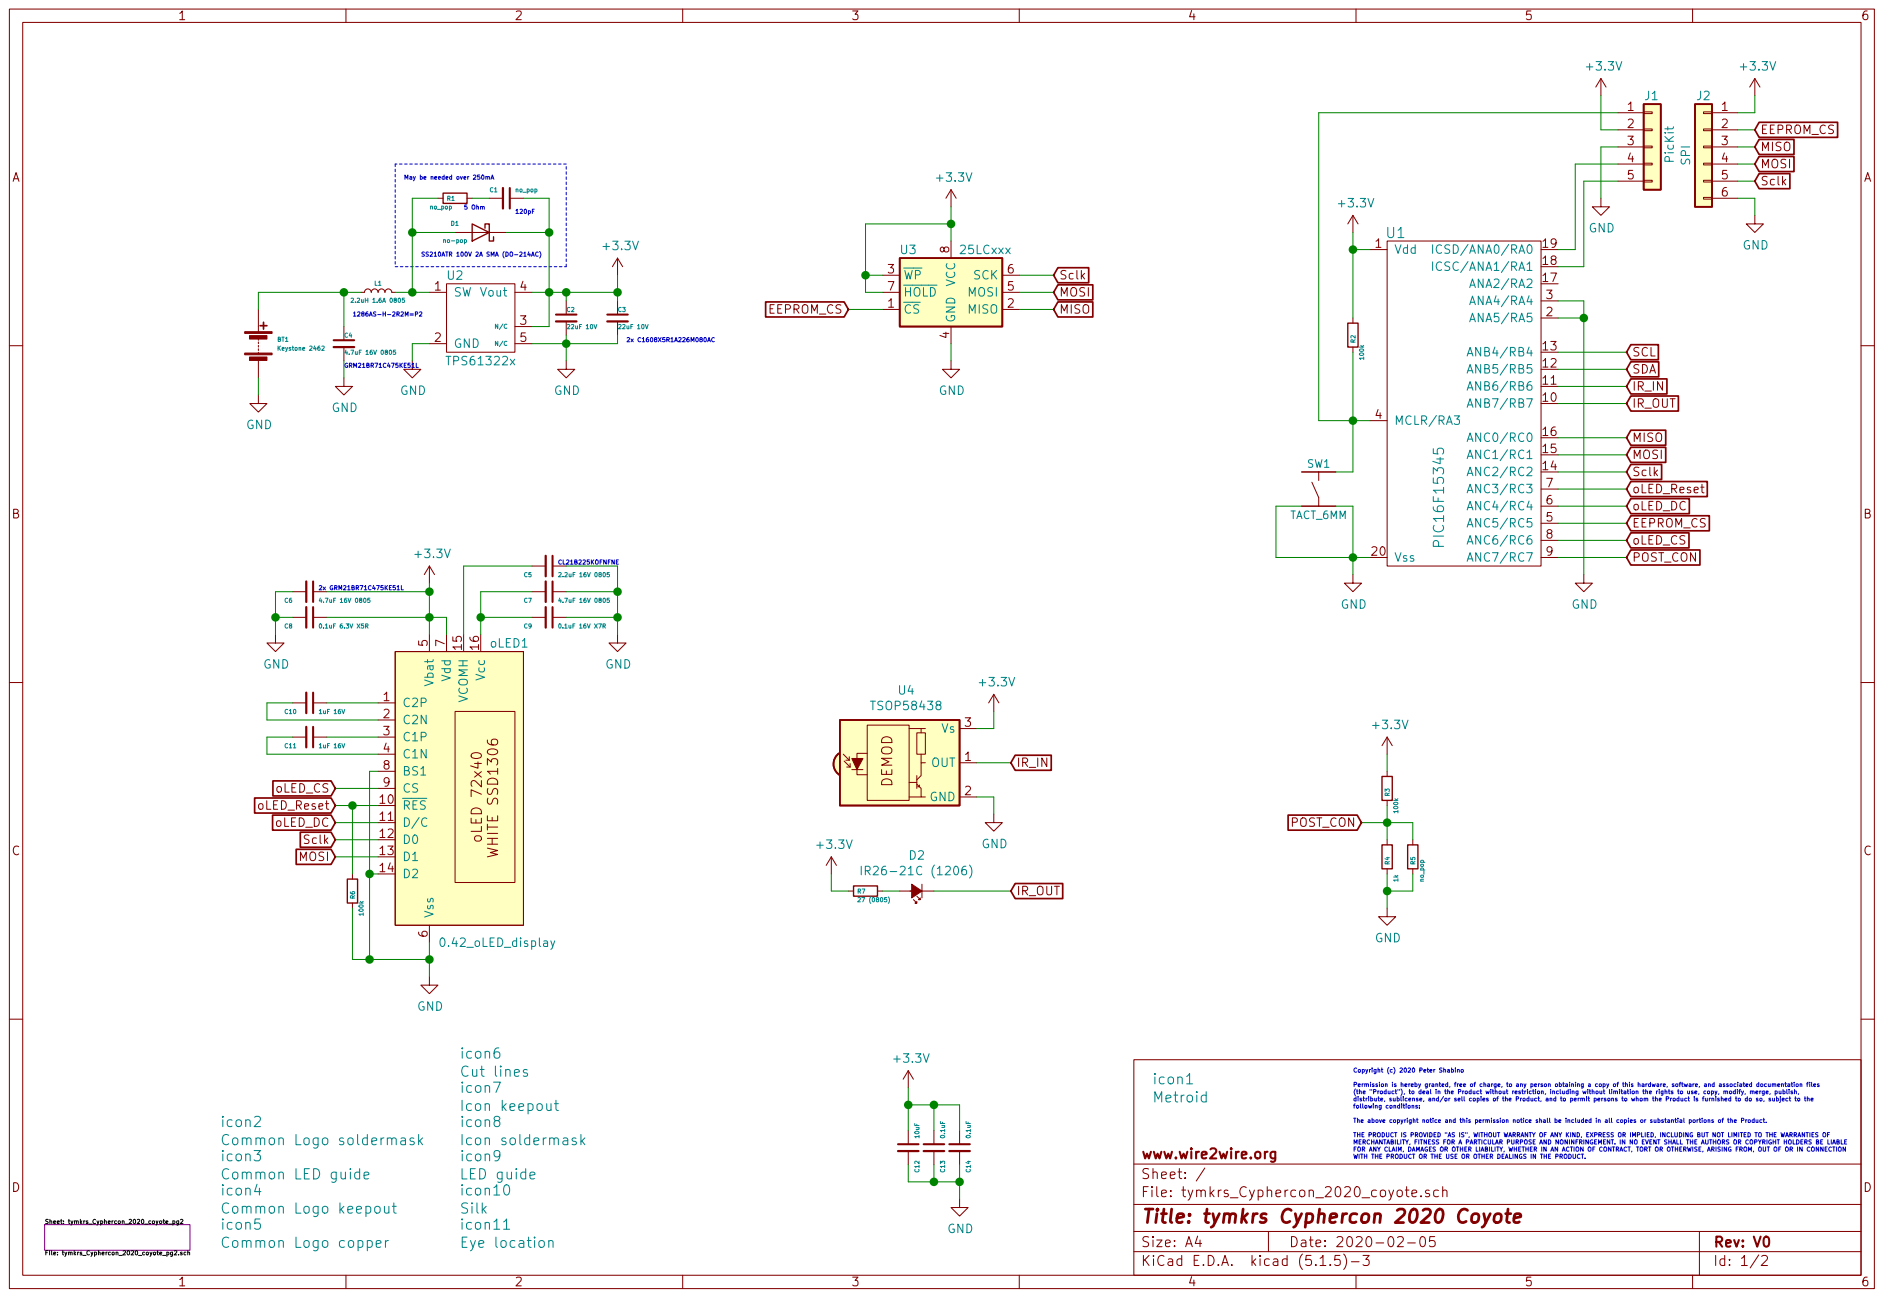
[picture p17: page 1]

1286AS-H-2R2M=P2 GRM21BR71C475KE51L May be needed over 250mA

4 MOSI 5 SCK 6 HOLD 7 VCC

Copyright (c) 2020 Peter Shabino Permission is hereby granted, free of charge, to any person obtaining a copy of this hardware, software, and associated documentation files (the "Product"), to deal in the Product without restriction, including without limitation the rights to use, copy, modify, merge, publish, distribute, sublicense, and/or sell copies of the Product, and to permit persons to whom the Product is furnished to do so, subject to the

following conditions: The above copyright notice and this permission notice shall be included in all copies or substantial portions of the Product. THE PRODUCT IS PROVIDED "AS IS", WITHOUT WARRANTY OF ANY KIND, EXPRESS OR IMPLIED, INCLUDING BUT NOT LIMITED TO THE WARRANTIES OF MERCHANTABILITY, FITNESS FOR A PARTICULAR PURPOSE AND NONINFRINGEMENT. IN NO EVENT SHALL THE AUTHORS OR COPYRIGHT HOLDERS BE LIABLE FOR ANY CLAIM, DAMAGES OR OTHER LIABILITY, WHETHER IN AN ACTION OF CONTRACT, TORT OR OTHERWISE, ARISING FROM, OUT OF OR IN CONNECTION WITH THE PRODUCT OR THE USE OR OTHER DEALINGS IN THE PRODUCT.

File: tymkrs_Cyphercon_2020_coyote.sch Sheet: / www.wire2wire.org

Id: 1/2 Title: tymkrs Cyphercon 2020 Coyote

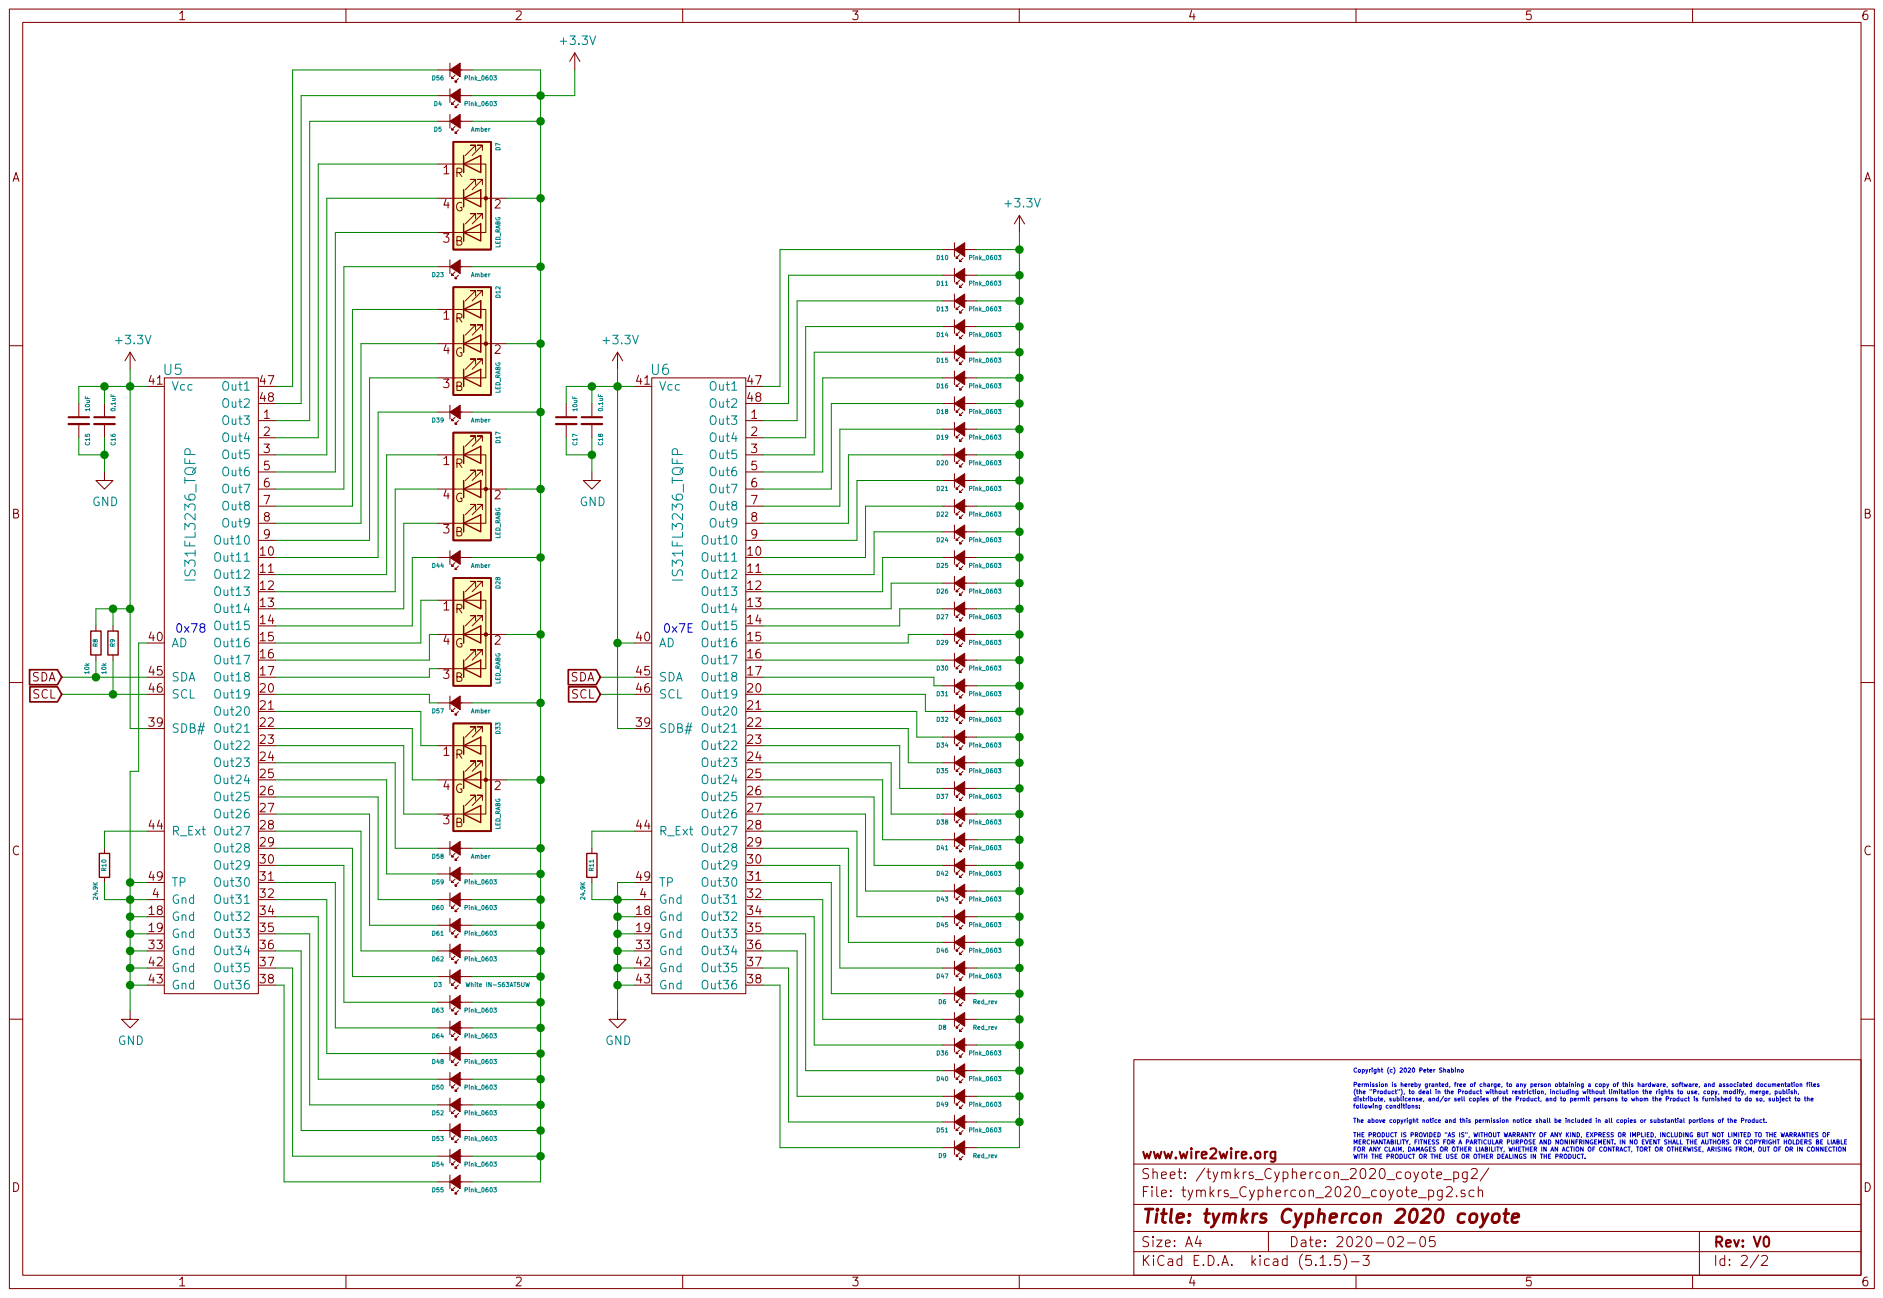
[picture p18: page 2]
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

www.wire2wire.org
Sheet: /tymkrs_Cyphercon_2020_coyote_pg2/
File: tymkrs_Cyphercon_2020_coyote_pg2.sch
Id: 2/2 Title: tymkrs Cyphercon 2020 coyote

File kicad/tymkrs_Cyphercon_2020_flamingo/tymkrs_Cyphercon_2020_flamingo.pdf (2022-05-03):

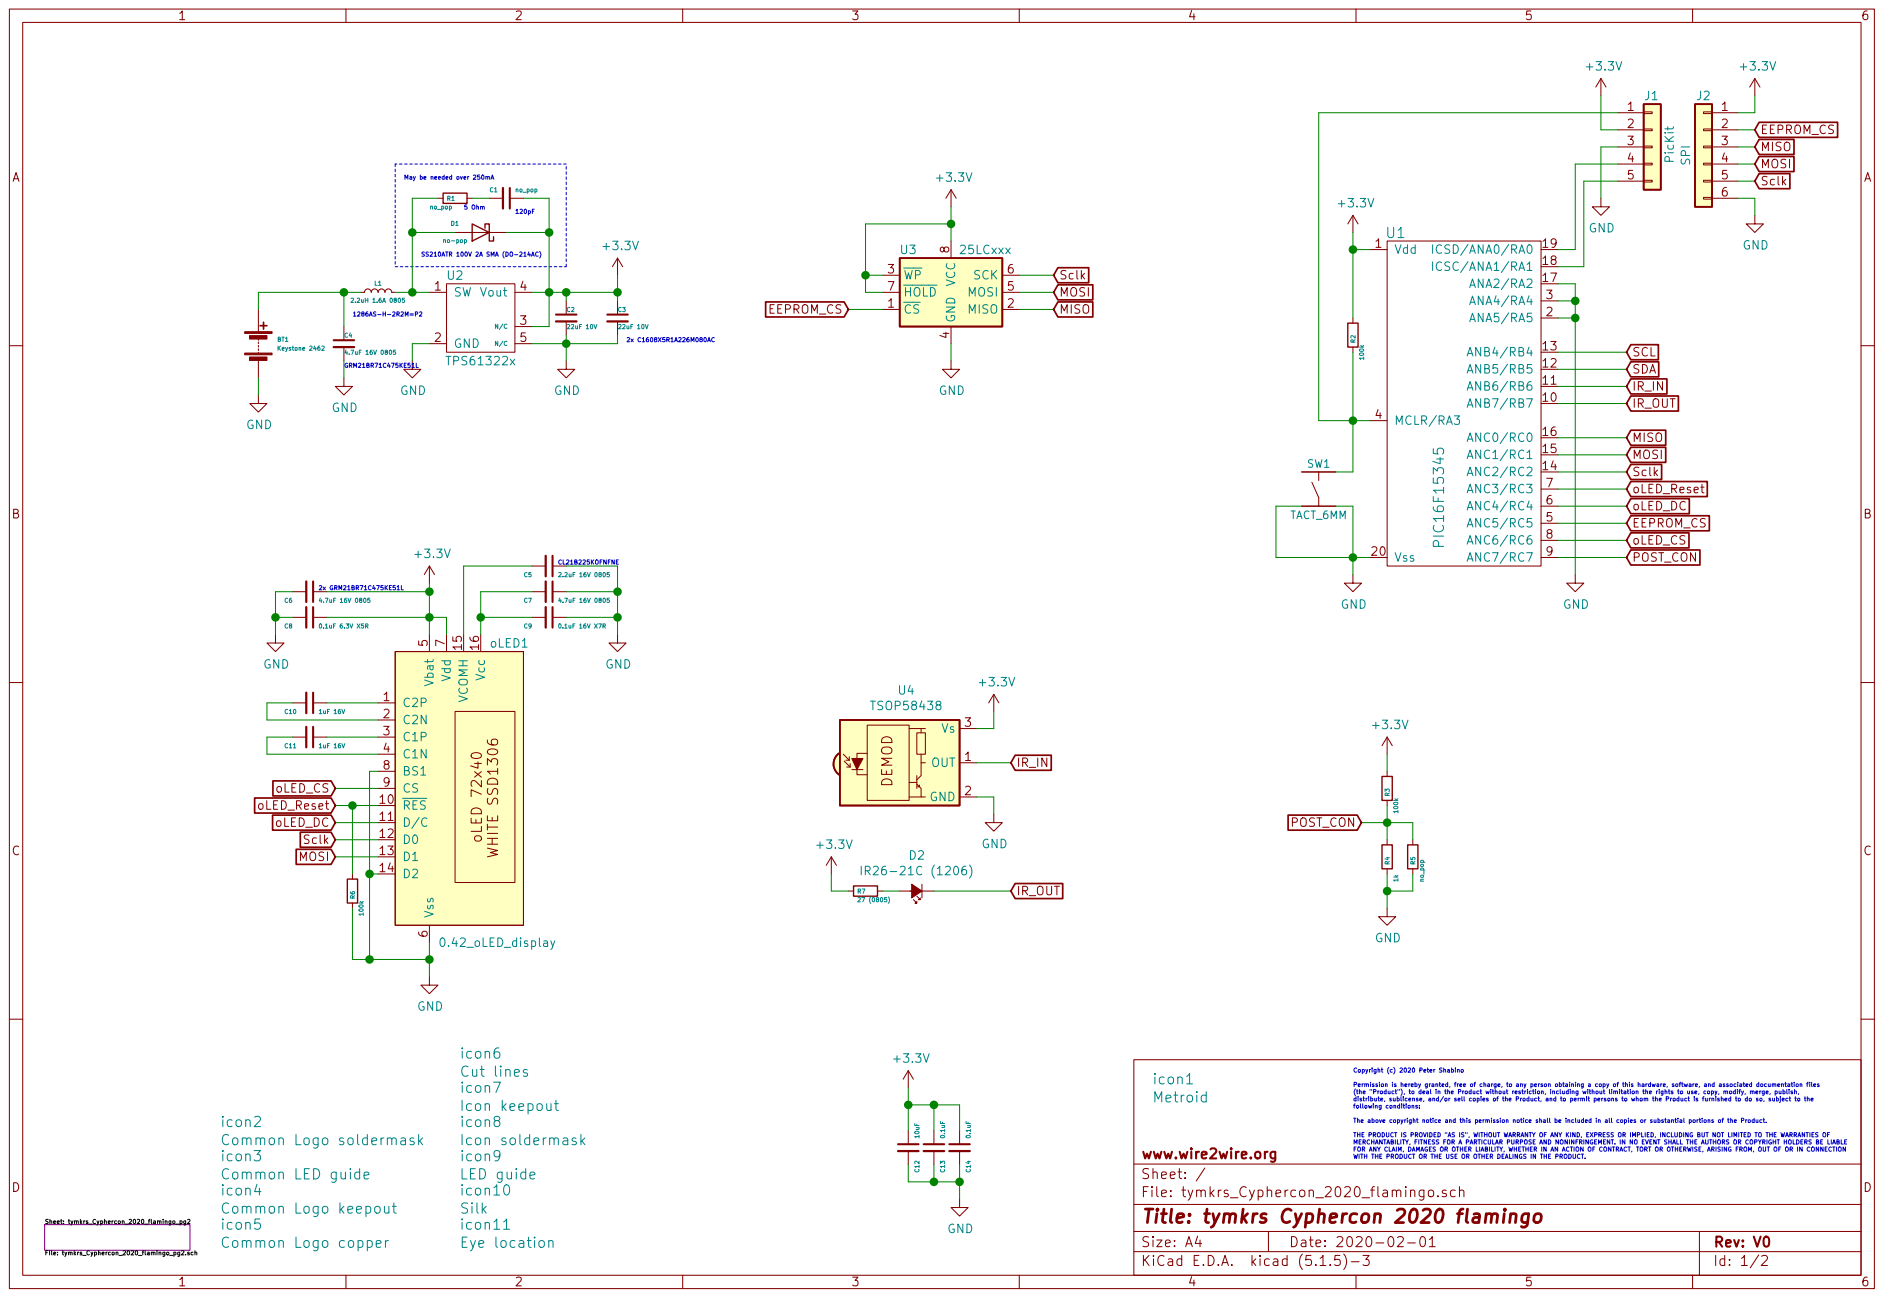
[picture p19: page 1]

1286AS-H-2R2M=P2 GRM21BR71C475KE51L May be needed over 250mA

4 MOSI 5 SCK 6 HOLD 7 VCC

Copyright (c) 2020 Peter Shabino Permission is hereby granted, free of charge, to any person obtaining a copy of this hardware, software, and associated documentation files (the "Product"), to deal in the Product without restriction, including without limitation the rights to use, copy, modify, merge, publish, distribute, sublicense, and/or sell copies of the Product, and to permit persons to whom the Product is furnished to do so, subject to the

following conditions: The above copyright notice and this permission notice shall be included in all copies or substantial portions of the Product. THE PRODUCT IS PROVIDED "AS IS", WITHOUT WARRANTY OF ANY KIND, EXPRESS OR IMPLIED, INCLUDING BUT NOT LIMITED TO THE WARRANTIES OF MERCHANTABILITY, FITNESS FOR A PARTICULAR PURPOSE AND NONINFRINGEMENT. IN NO EVENT SHALL THE AUTHORS OR COPYRIGHT HOLDERS BE LIABLE FOR ANY CLAIM, DAMAGES OR OTHER LIABILITY, WHETHER IN AN ACTION OF CONTRACT, TORT OR OTHERWISE, ARISING FROM, OUT OF OR IN CONNECTION WITH THE PRODUCT OR THE USE OR OTHER DEALINGS IN THE PRODUCT.

File: tymkrs_Cyphercon_2020_flamingo.sch Sheet: / www.wire2wire.org

Id: 1/2 Title: tymkrs Cyphercon 2020 flamingo

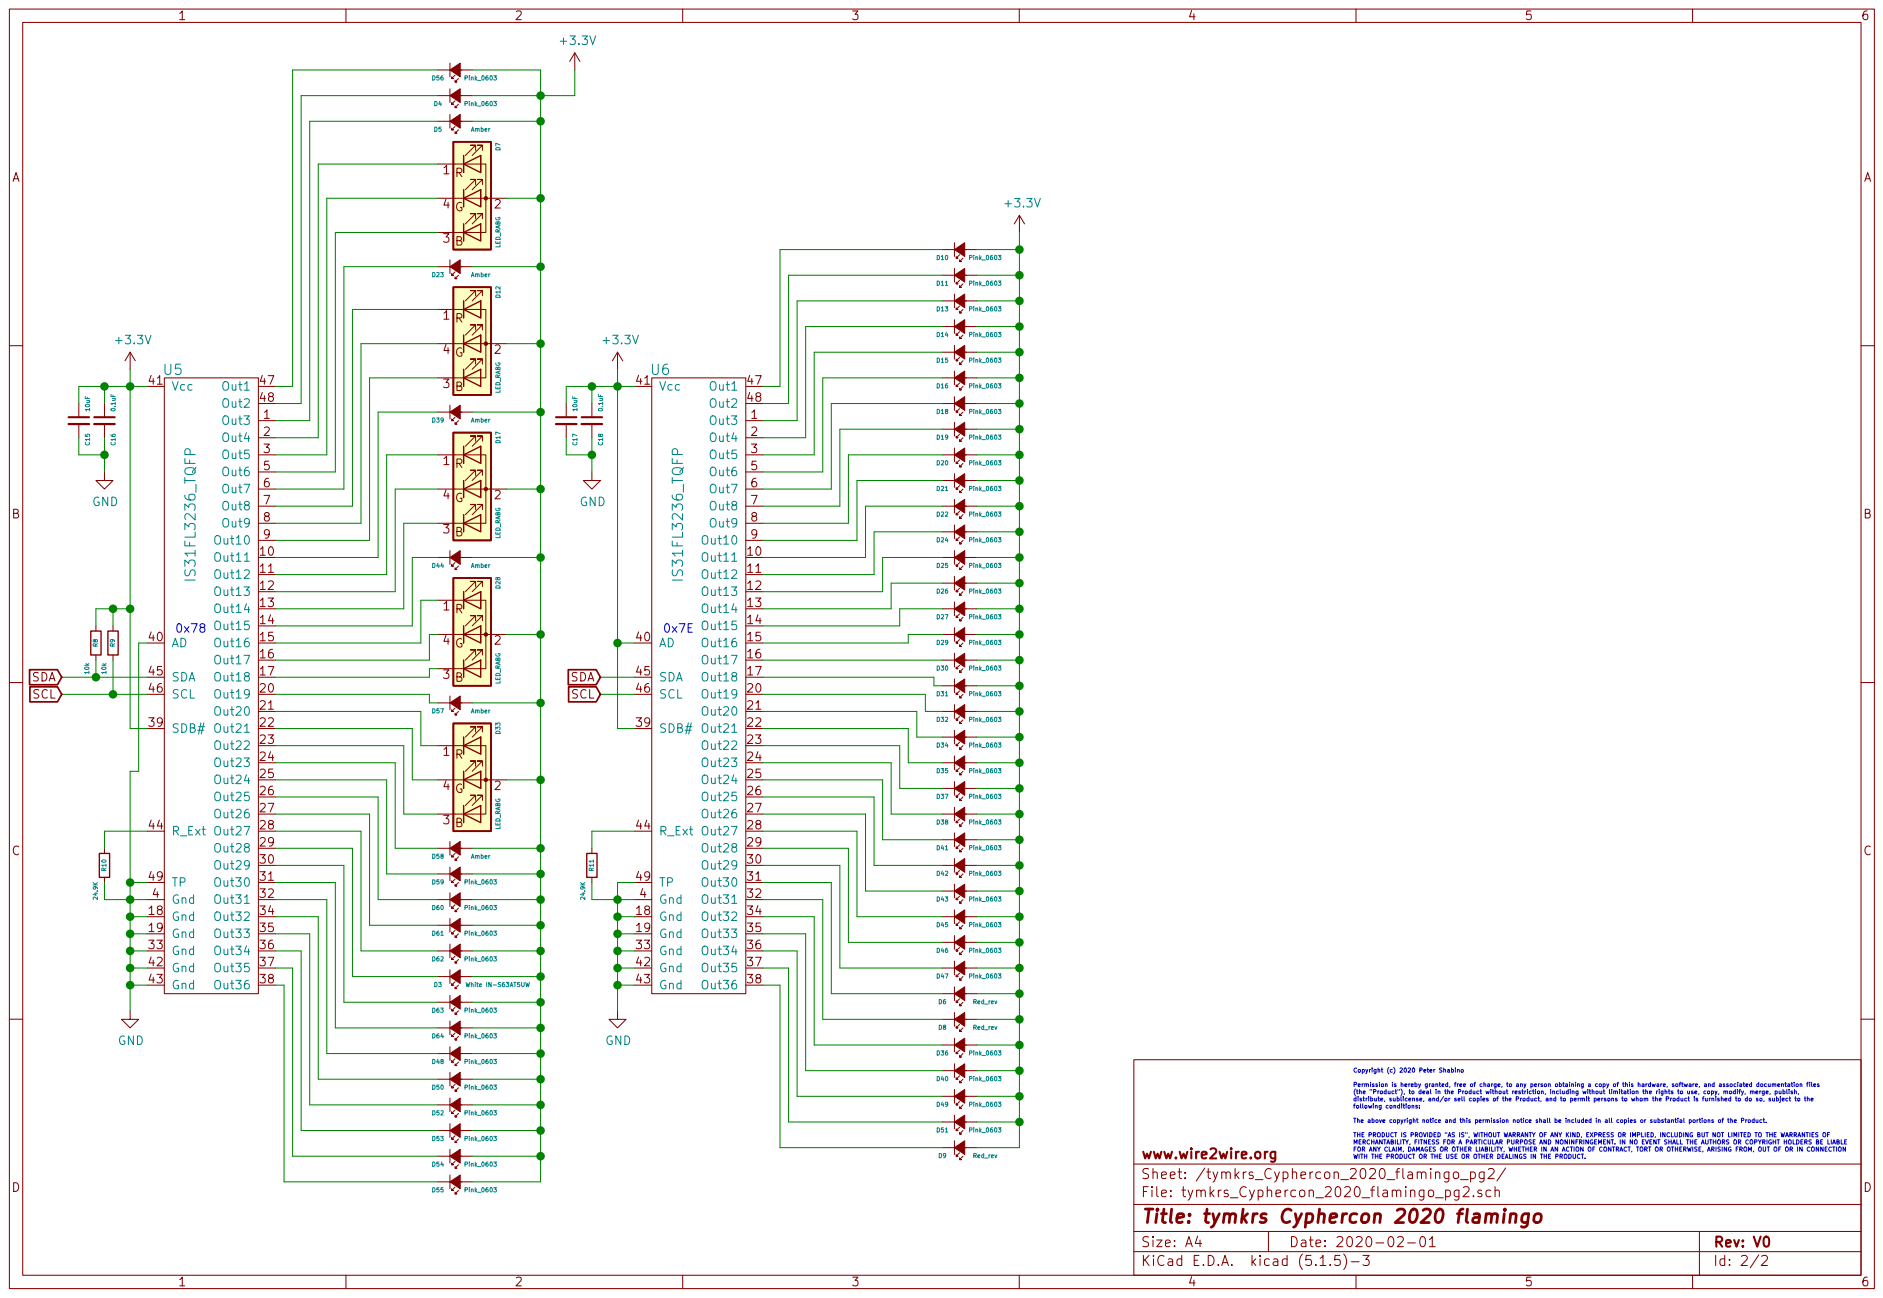
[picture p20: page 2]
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

www.wire2wire.org
Sheet: /tymkrs_Cyphercon_2020_flamingo_pg2/
File: tymkrs_Cyphercon_2020_flamingo_pg2.sch
Id: 2/2 Title: tymkrs Cyphercon 2020 flamingo

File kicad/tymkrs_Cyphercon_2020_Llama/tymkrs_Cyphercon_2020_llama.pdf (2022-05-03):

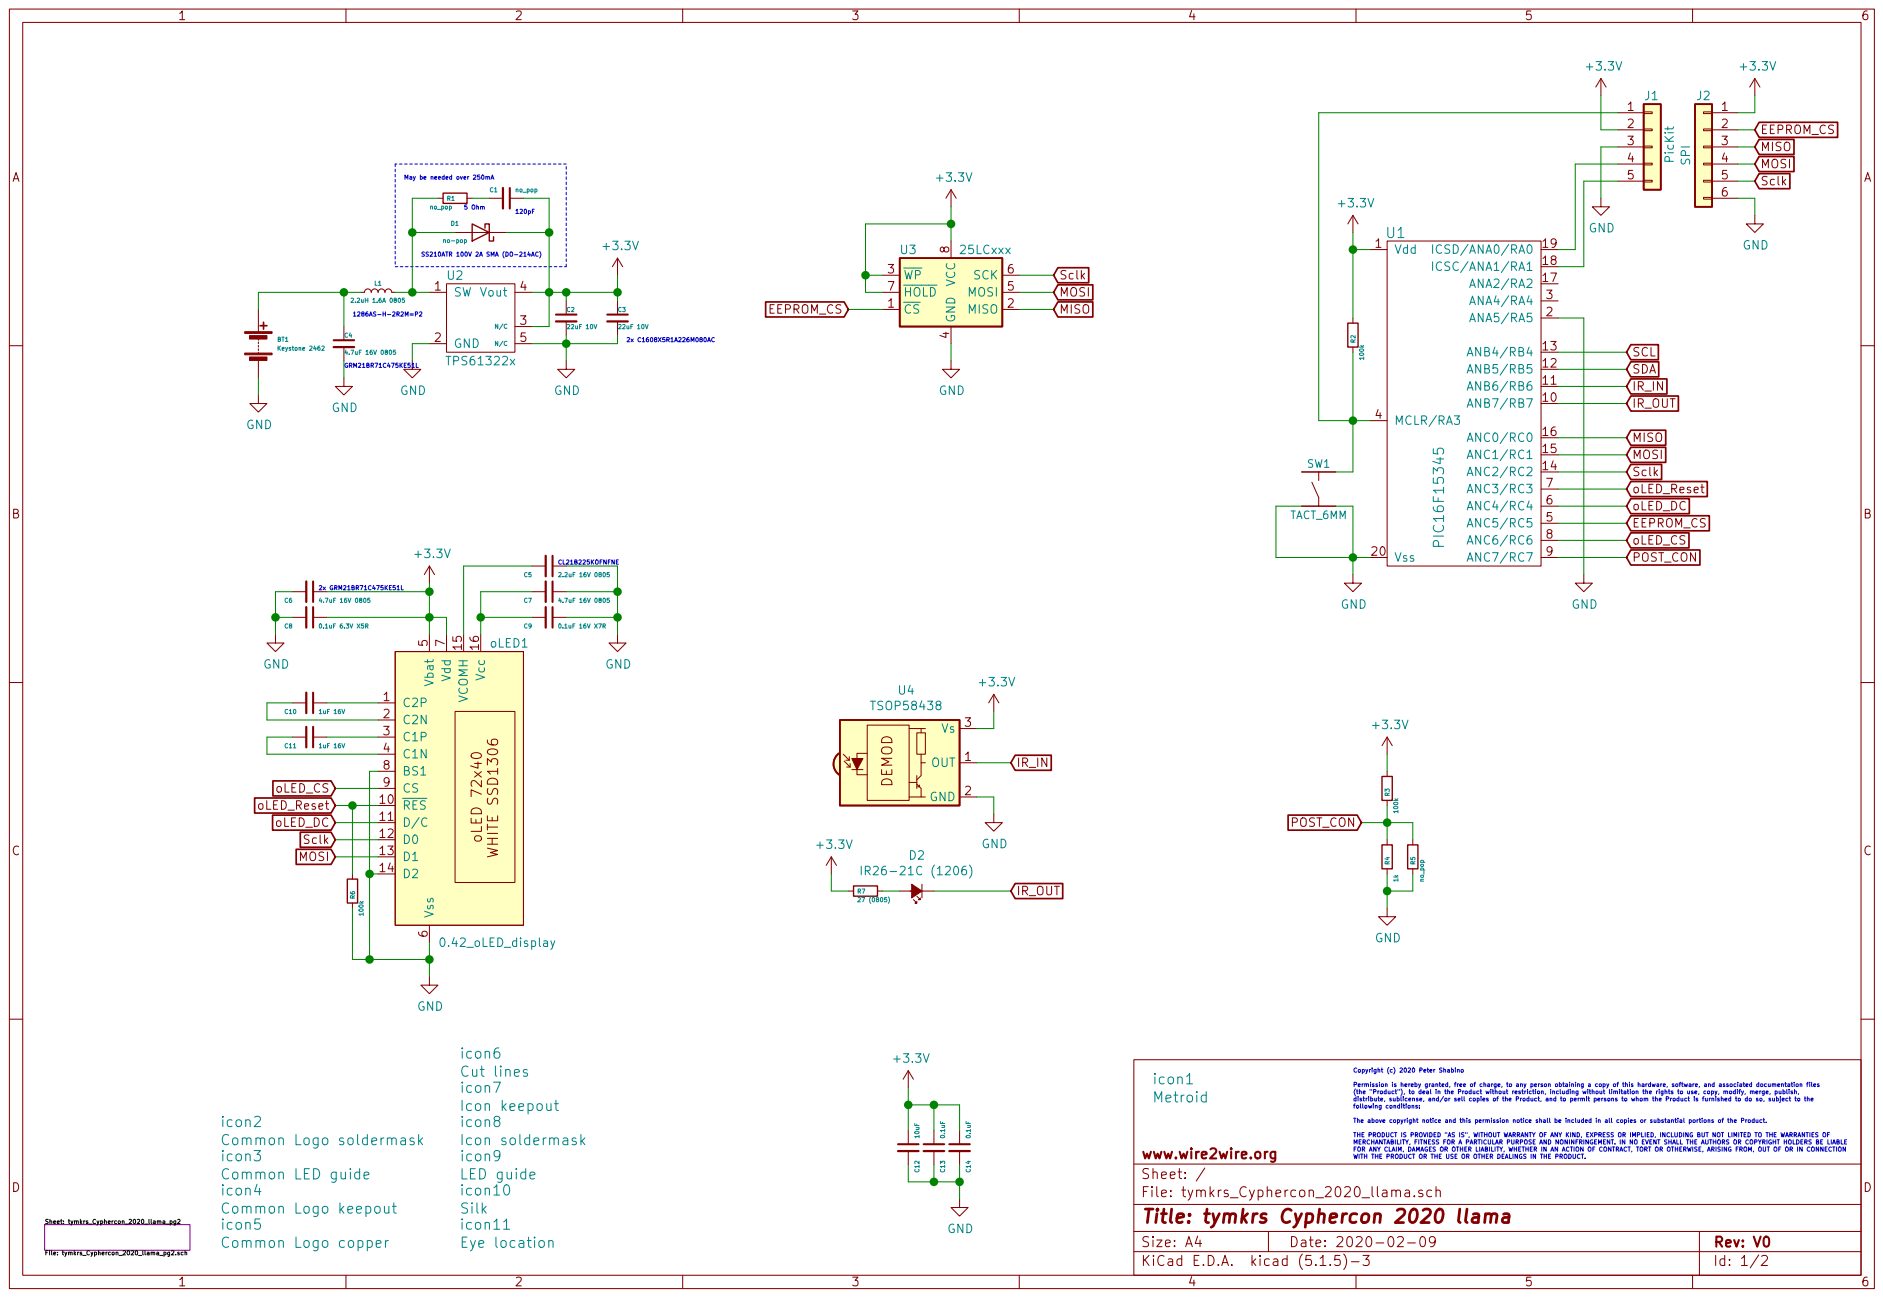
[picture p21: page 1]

Sclk MOSI SS210ATR 100V 2A SMA (DO-214AC) May be needed over 250mA

4 MOSI 5 SCK 6 HOLD 7 VCC

Copyright (c) 2020 Peter Shabino Permission is hereby granted, free of charge, to any person obtaining a copy of this hardware, software, and associated documentation files (the "Product"), to deal in the Product without restriction, including without limitation the rights to use, copy, modify, merge, publish, distribute, sublicense, and/or sell copies of the Product, and to permit persons to whom the Product is furnished to do so, subject to the

following conditions: The above copyright notice and this permission notice shall be included in all copies or substantial portions of the Product. THE PRODUCT IS PROVIDED "AS IS", WITHOUT WARRANTY OF ANY KIND, EXPRESS OR IMPLIED, INCLUDING BUT NOT LIMITED TO THE WARRANTIES OF MERCHANTABILITY, FITNESS FOR A PARTICULAR PURPOSE AND NONINFRINGEMENT. IN NO EVENT SHALL THE AUTHORS OR COPYRIGHT HOLDERS BE LIABLE FOR ANY CLAIM, DAMAGES OR OTHER LIABILITY, WHETHER IN AN ACTION OF CONTRACT, TORT OR OTHERWISE, ARISING FROM, OUT OF OR IN CONNECTION WITH THE PRODUCT OR THE USE OR OTHER DEALINGS IN THE PRODUCT.

File: tymkrs_Cyphercon_2020_llama.sch Sheet: / www.wire2wire.org

Id: 1/2 Title: tymkrs Cyphercon 2020 llama

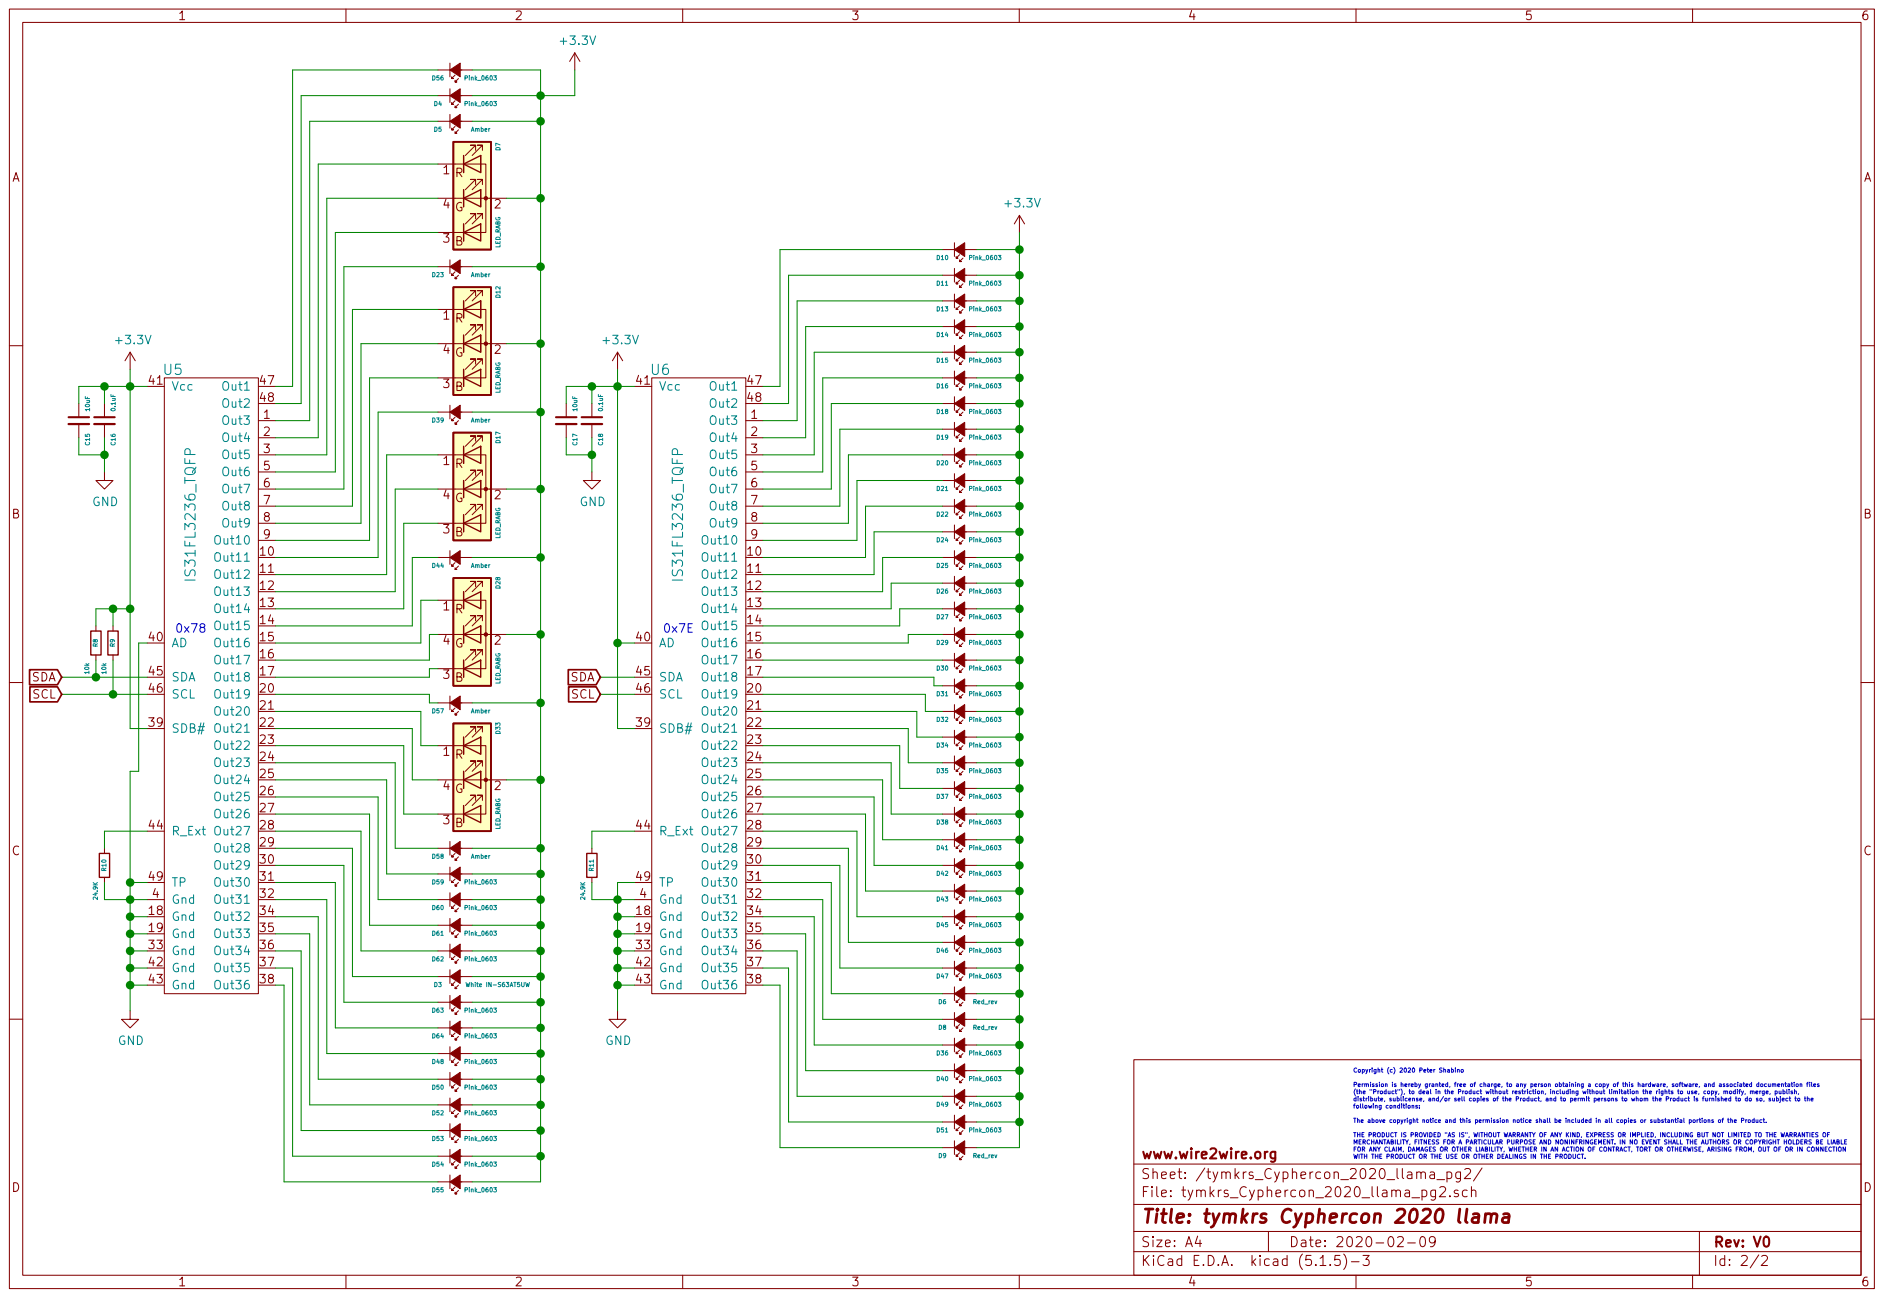
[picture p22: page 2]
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

www.wire2wire.org
Sheet: /tymkrs_Cyphercon_2020_llama_pg2/
File: tymkrs_Cyphercon_2020_llama_pg2.sch
Id: 2/2 Title: tymkrs Cyphercon 2020 llama

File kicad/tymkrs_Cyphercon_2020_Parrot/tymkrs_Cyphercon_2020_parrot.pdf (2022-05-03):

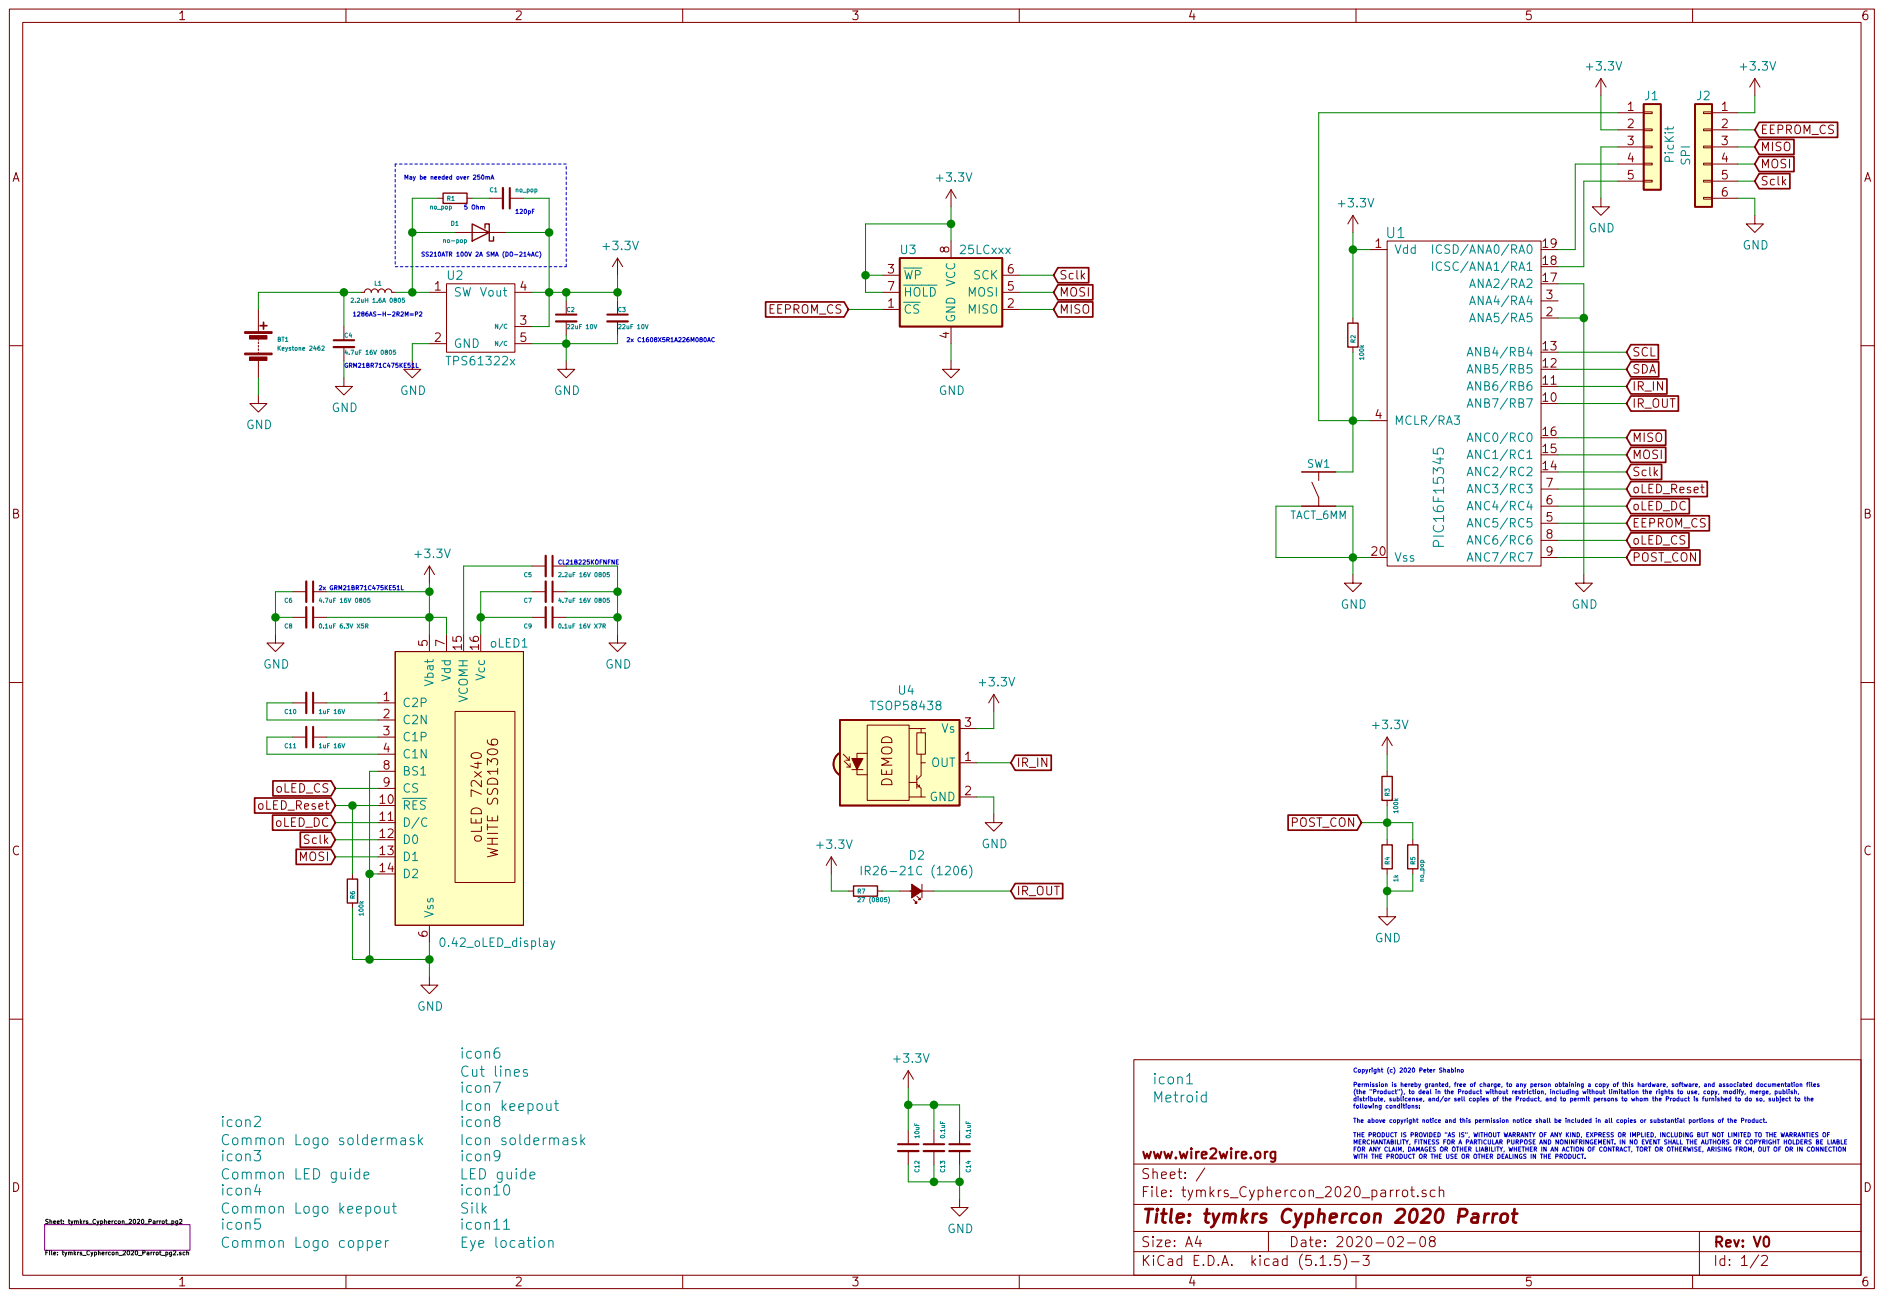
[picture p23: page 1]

1286AS-H-2R2M=P2 GRM21BR71C475KE51L May be needed over 250mA

4 MOSI 5 SCK 6 HOLD 7 VCC

Copyright (c) 2020 Peter Shabino Permission is hereby granted, free of charge, to any person obtaining a copy of this hardware, software, and associated documentation files (the "Product"), to deal in the Product without restriction, including without limitation the rights to use, copy, modify, merge, publish, distribute, sublicense, and/or sell copies of the Product, and to permit persons to whom the Product is furnished to do so, subject to the

following conditions: The above copyright notice and this permission notice shall be included in all copies or substantial portions of the Product. THE PRODUCT IS PROVIDED "AS IS", WITHOUT WARRANTY OF ANY KIND, EXPRESS OR IMPLIED, INCLUDING BUT NOT LIMITED TO THE WARRANTIES OF MERCHANTABILITY, FITNESS FOR A PARTICULAR PURPOSE AND NONINFRINGEMENT. IN NO EVENT SHALL THE AUTHORS OR COPYRIGHT HOLDERS BE LIABLE FOR ANY CLAIM, DAMAGES OR OTHER LIABILITY, WHETHER IN AN ACTION OF CONTRACT, TORT OR OTHERWISE, ARISING FROM, OUT OF OR IN CONNECTION WITH THE PRODUCT OR THE USE OR OTHER DEALINGS IN THE PRODUCT.

File: tymkrs_Cyphercon_2020_parrot.sch Sheet: / www.wire2wire.org

Id: 1/2 Title: tymkrs Cyphercon 2020 Parrot

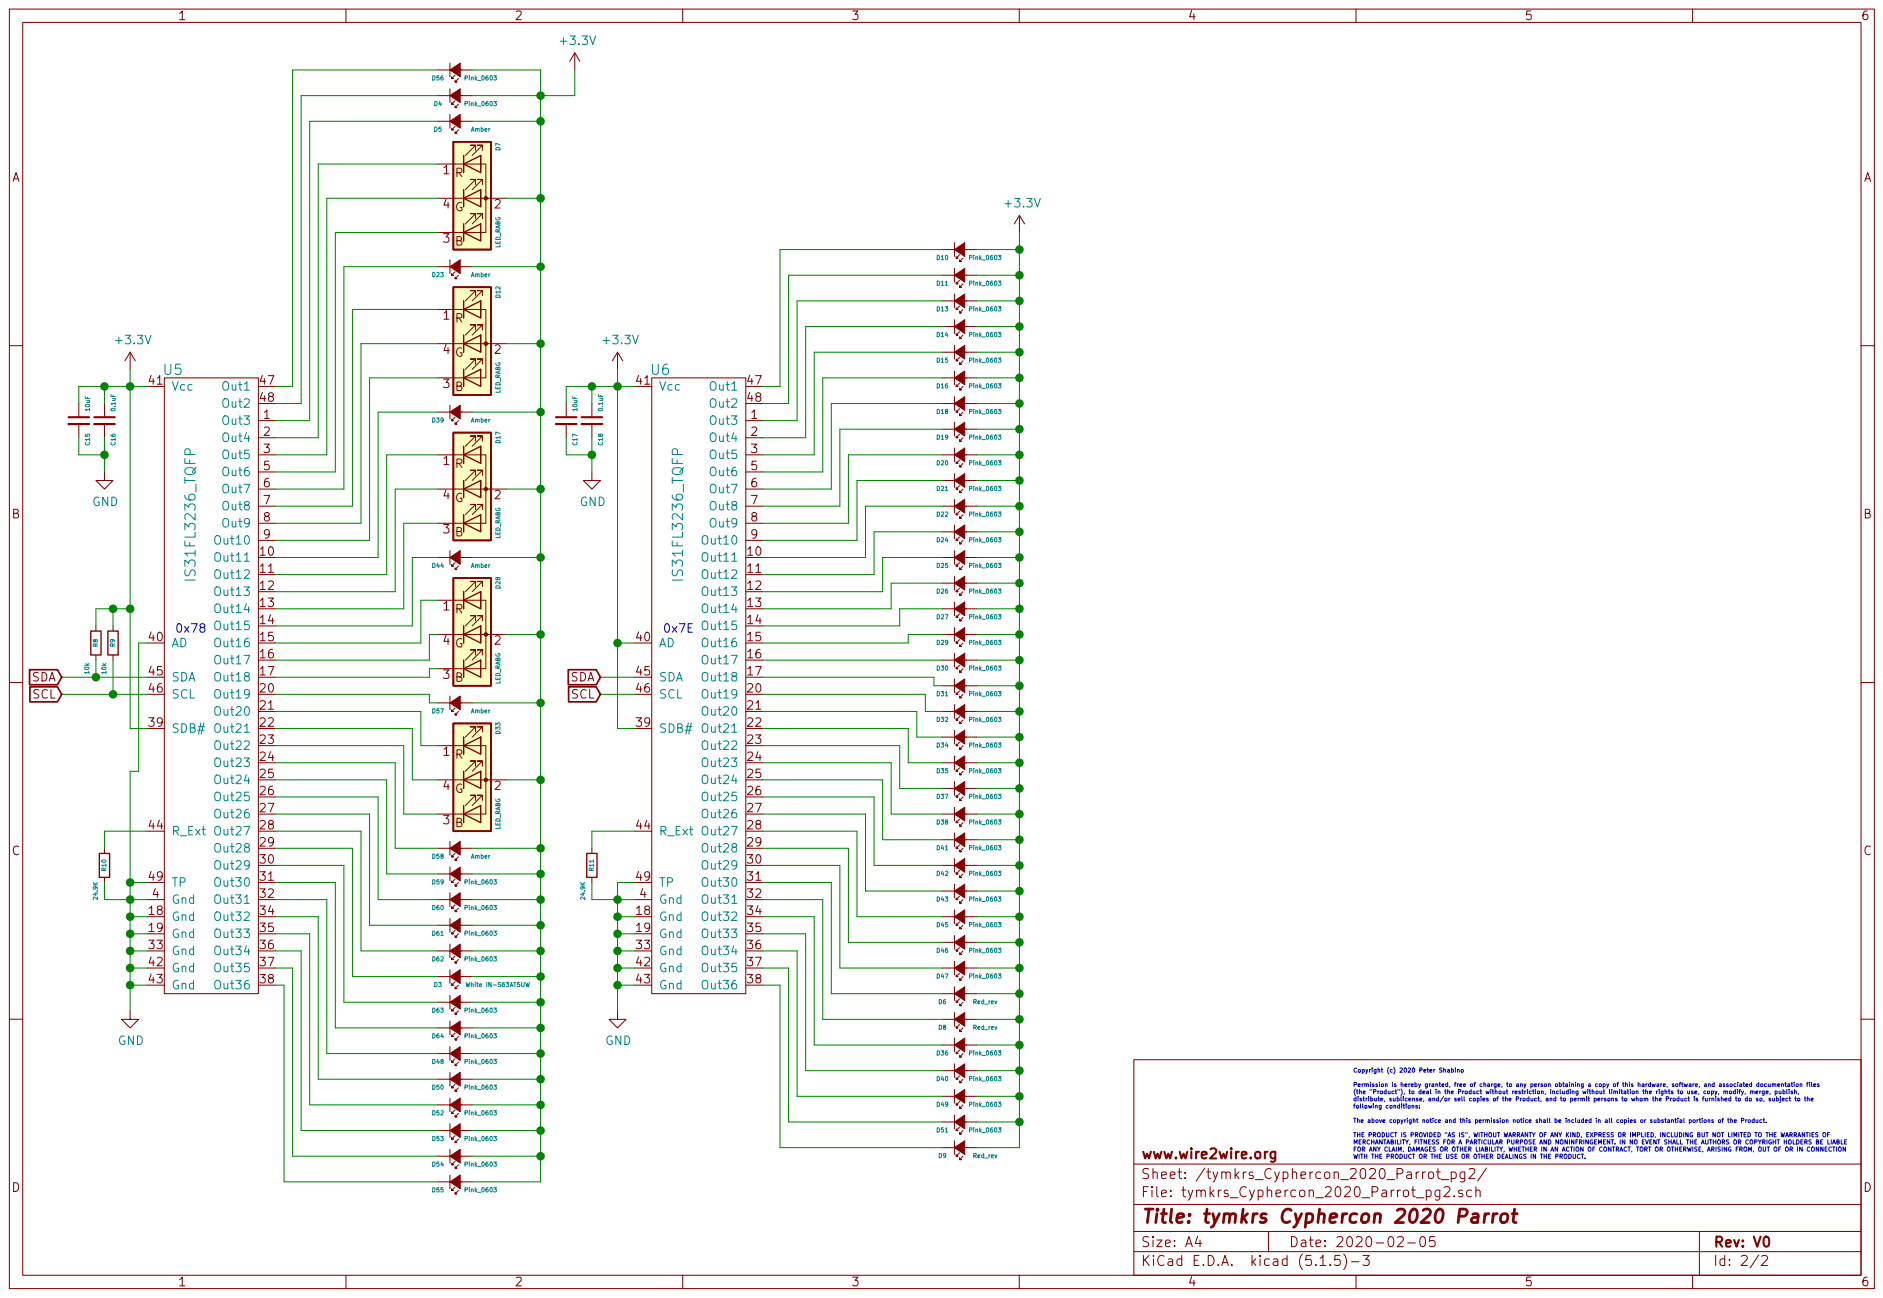
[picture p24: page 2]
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

www.wire2wire.org
Sheet: /tymkrs_Cyphercon_2020_Parrot_pg2/
File: tymkrs_Cyphercon_2020_Parrot_pg2.sch
Id: 2/2 Title: tymkrs Cyphercon 2020 Parrot

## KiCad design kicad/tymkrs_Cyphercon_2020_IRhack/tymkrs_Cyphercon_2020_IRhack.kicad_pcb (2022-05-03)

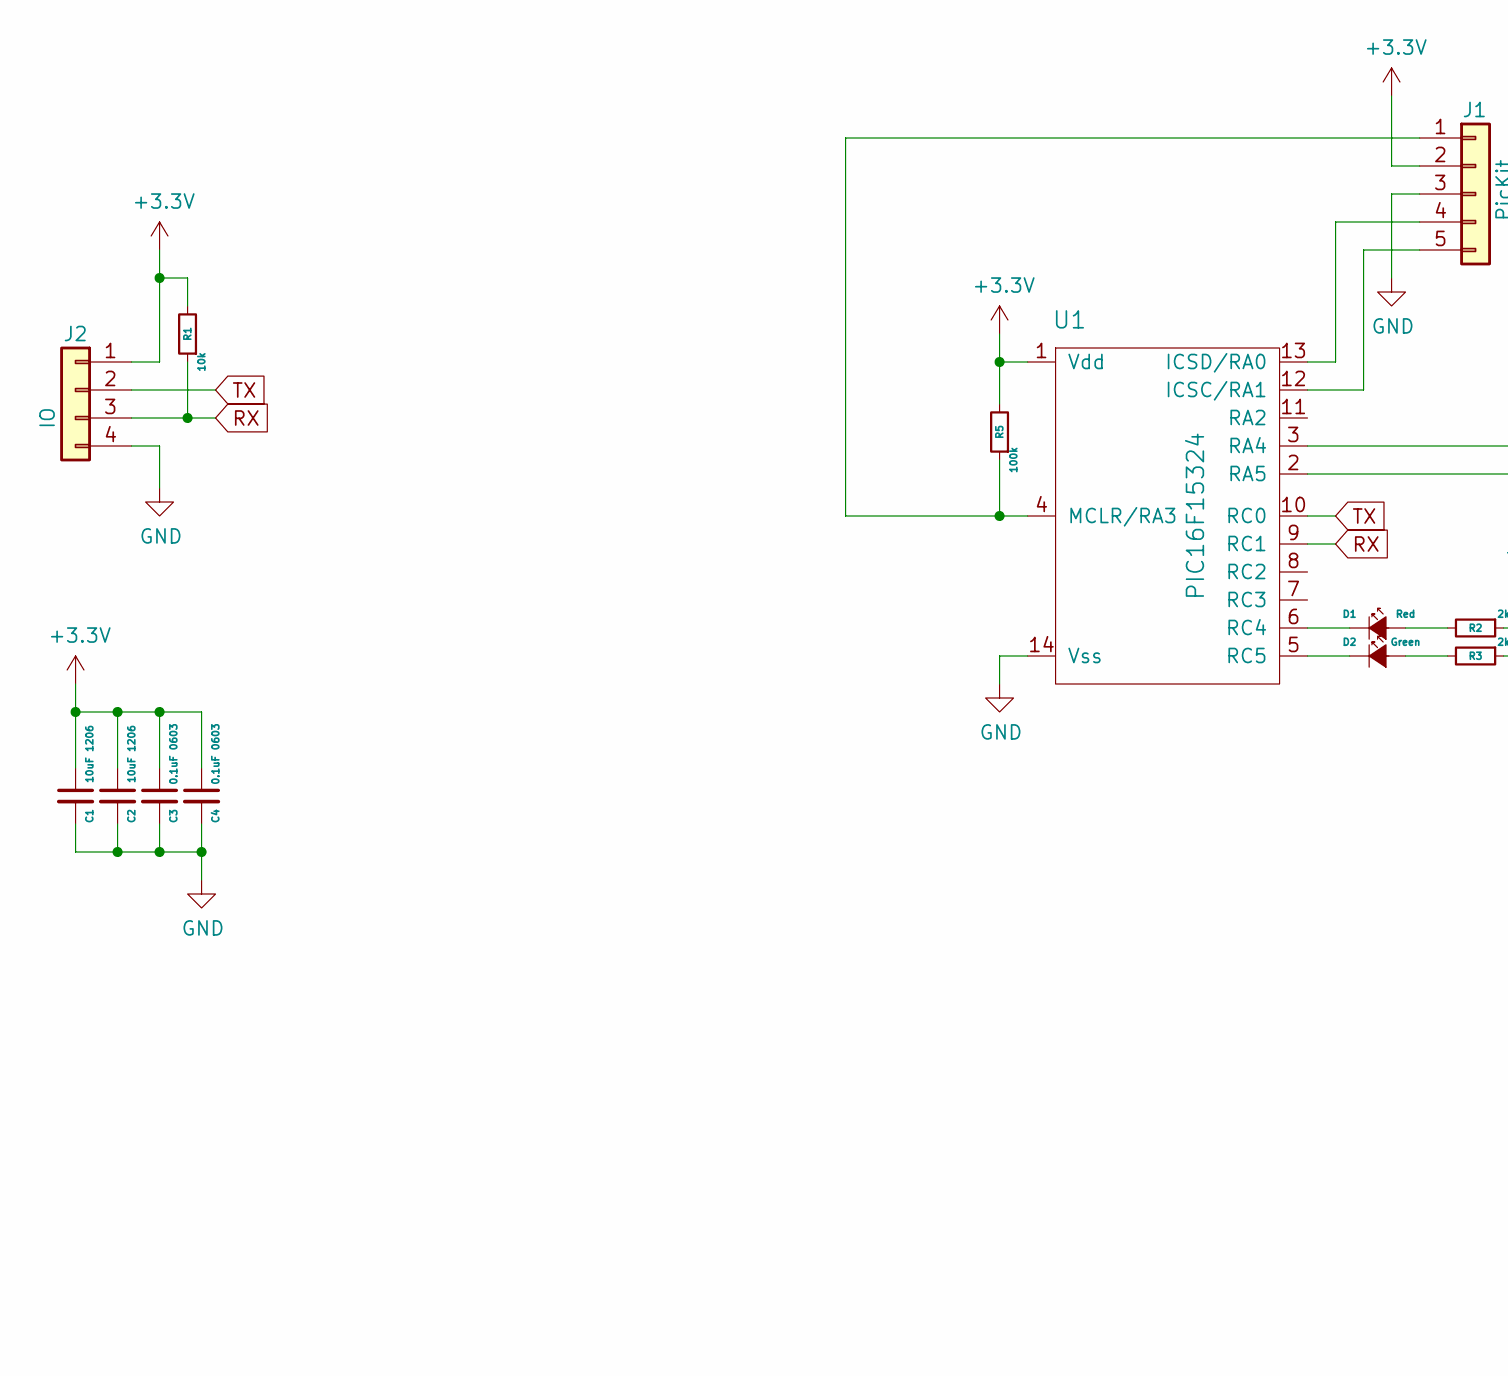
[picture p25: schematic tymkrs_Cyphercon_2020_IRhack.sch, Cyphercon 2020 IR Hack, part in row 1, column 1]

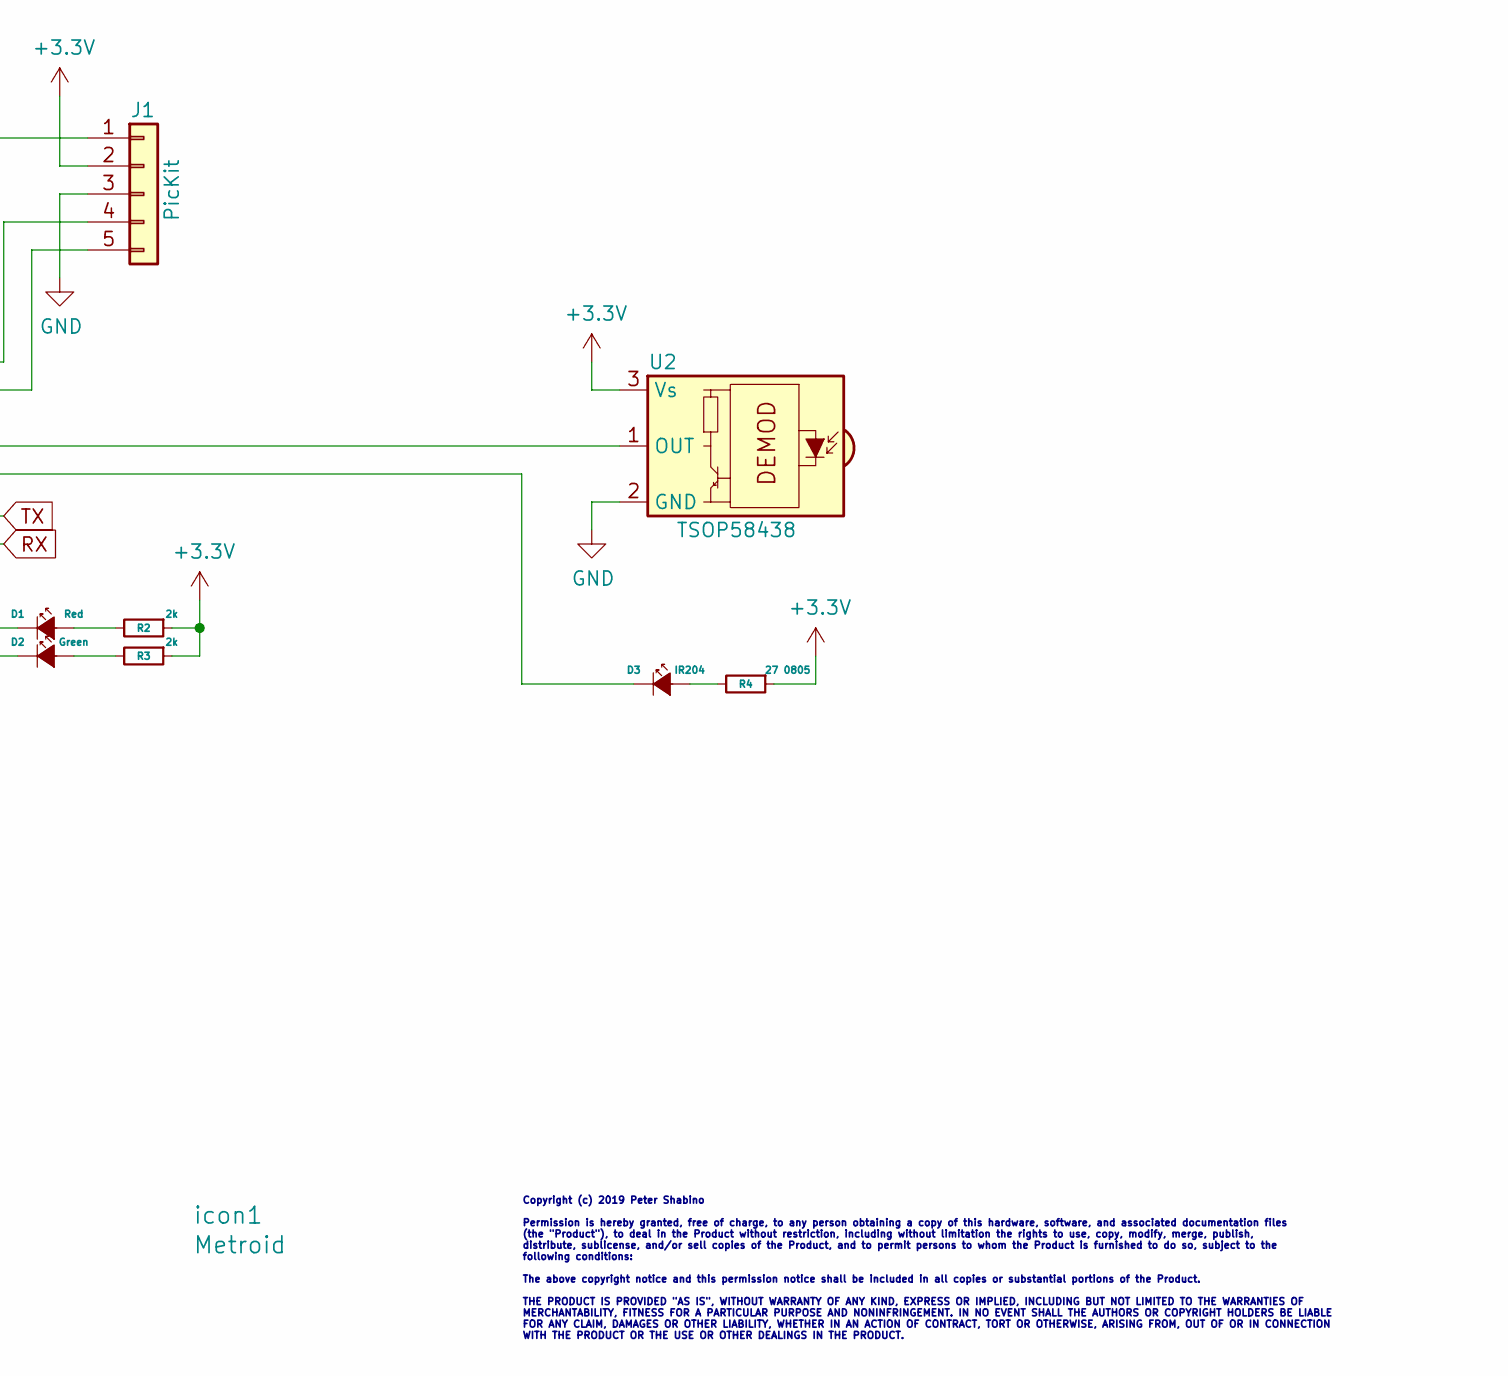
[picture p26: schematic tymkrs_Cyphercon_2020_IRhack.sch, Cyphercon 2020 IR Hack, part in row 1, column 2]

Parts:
C1, C2: 10uF 1206; C_1206_3216Metric
C3, C4: 0.1uF 0603; C_0603_1608Metric
D1: Red; LED_0603_1608Metric
D2: Green; LED_0603_1608Metric
D3: IR204; LED_D3.0mm_Horizontal_O1.27mm_Z2.0mm_Clear
J1: PicKit; PinHeader_1x05_P2.54mm_Vertical
J2: IO; PinHeader_1x04_P2.54mm_Horizontal
R1: 10k; R_0603_1608Metric
R2, R3: 2k; R_0603_1608Metric
R4: 27 0805; R_0603_1608Metric
R5: 100k; R_0603_1608Metric
U1: PIC16F15324; SOIC-14_3.9x8.7mm_P1.27mm
U2: TSOP58438; TSOP48
icon1: Metroid; metroid

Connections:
+3V3: C1.1, C2.1, C3.1, C4.1, J1.2, J2.1, R1.2, R2.1, R3.1, R4.1, R5.2, U1.1 (Vdd), U2.3 (Vs)
GND: C1.2, C2.2, C3.2, C4.2, J1.3, J2.4, U1.14 (Vss), U2.2 (GND)
unnamed: D1.1 (K), U1.6 (RC4)
unnamed: D1.2 (A), R2.2
unnamed: D2.1 (K), U1.5 (RC5)
unnamed: D2.2 (A), R3.2
unnamed: D3.1 (K), U1.2 (RA5)
unnamed: D3.2 (A), R4.2
unnamed: J1.1, R5.1, U1.4 (MCLR/RA3)
unnamed: J1.4, U1.13 (ICSD/RA0)
unnamed: J1.5, U1.12 (ICSC/RA1)
unnamed: U1.3 (RA4), U2.1 (OUT)
RX: J2.3, R1.1, U1.9 (RC1)
TX: J2.2, U1.10 (RC0)

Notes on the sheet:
Copyright (c) 2019 Peter Shabino Permission is hereby granted, free of charge, to any person obtaining a copy of this hardware, software, and associated documentation files (the "Product"), to deal in the Product without restriction, including without limitation the rights to use, copy, modify, mer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

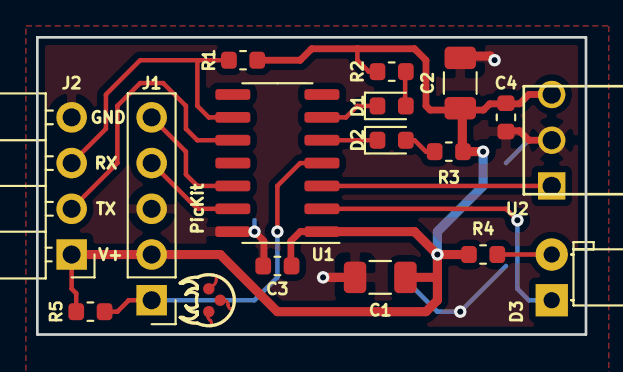
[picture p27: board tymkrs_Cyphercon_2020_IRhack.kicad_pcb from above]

Board: 2 copper layers, 30.5 x 16.5 mm, 17 parts (0 on the bottom side), 14 nets.

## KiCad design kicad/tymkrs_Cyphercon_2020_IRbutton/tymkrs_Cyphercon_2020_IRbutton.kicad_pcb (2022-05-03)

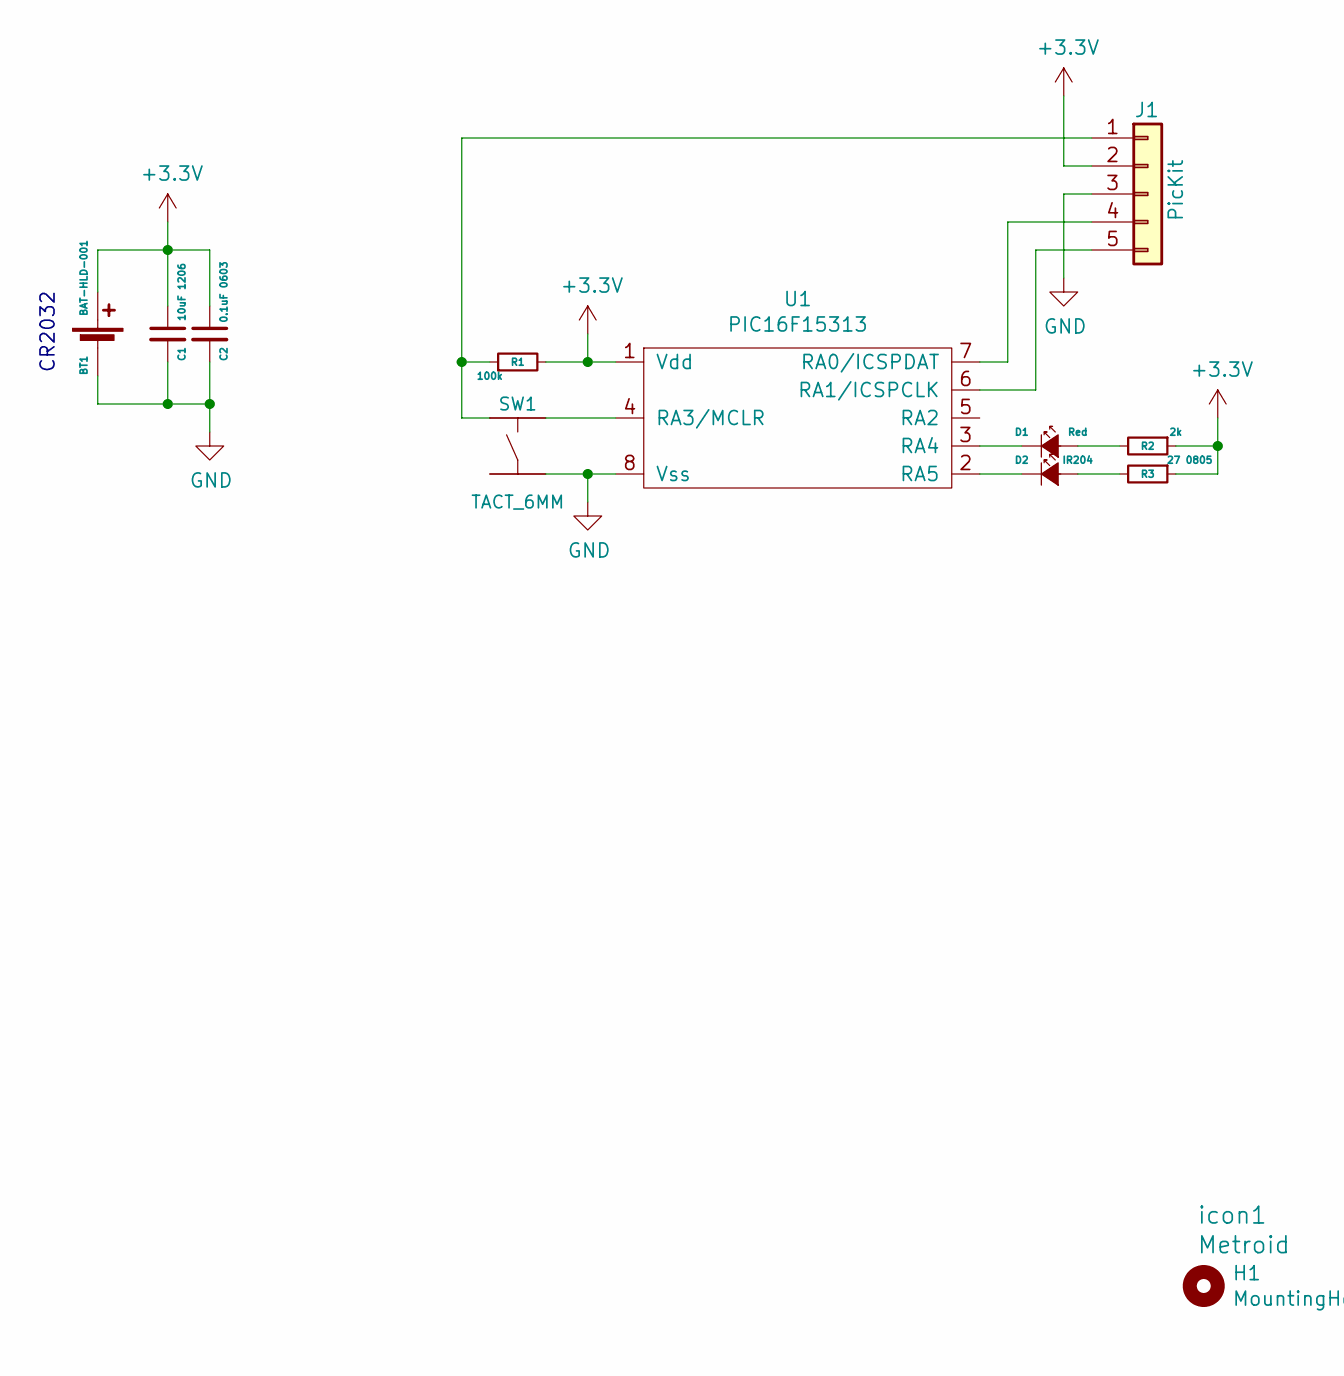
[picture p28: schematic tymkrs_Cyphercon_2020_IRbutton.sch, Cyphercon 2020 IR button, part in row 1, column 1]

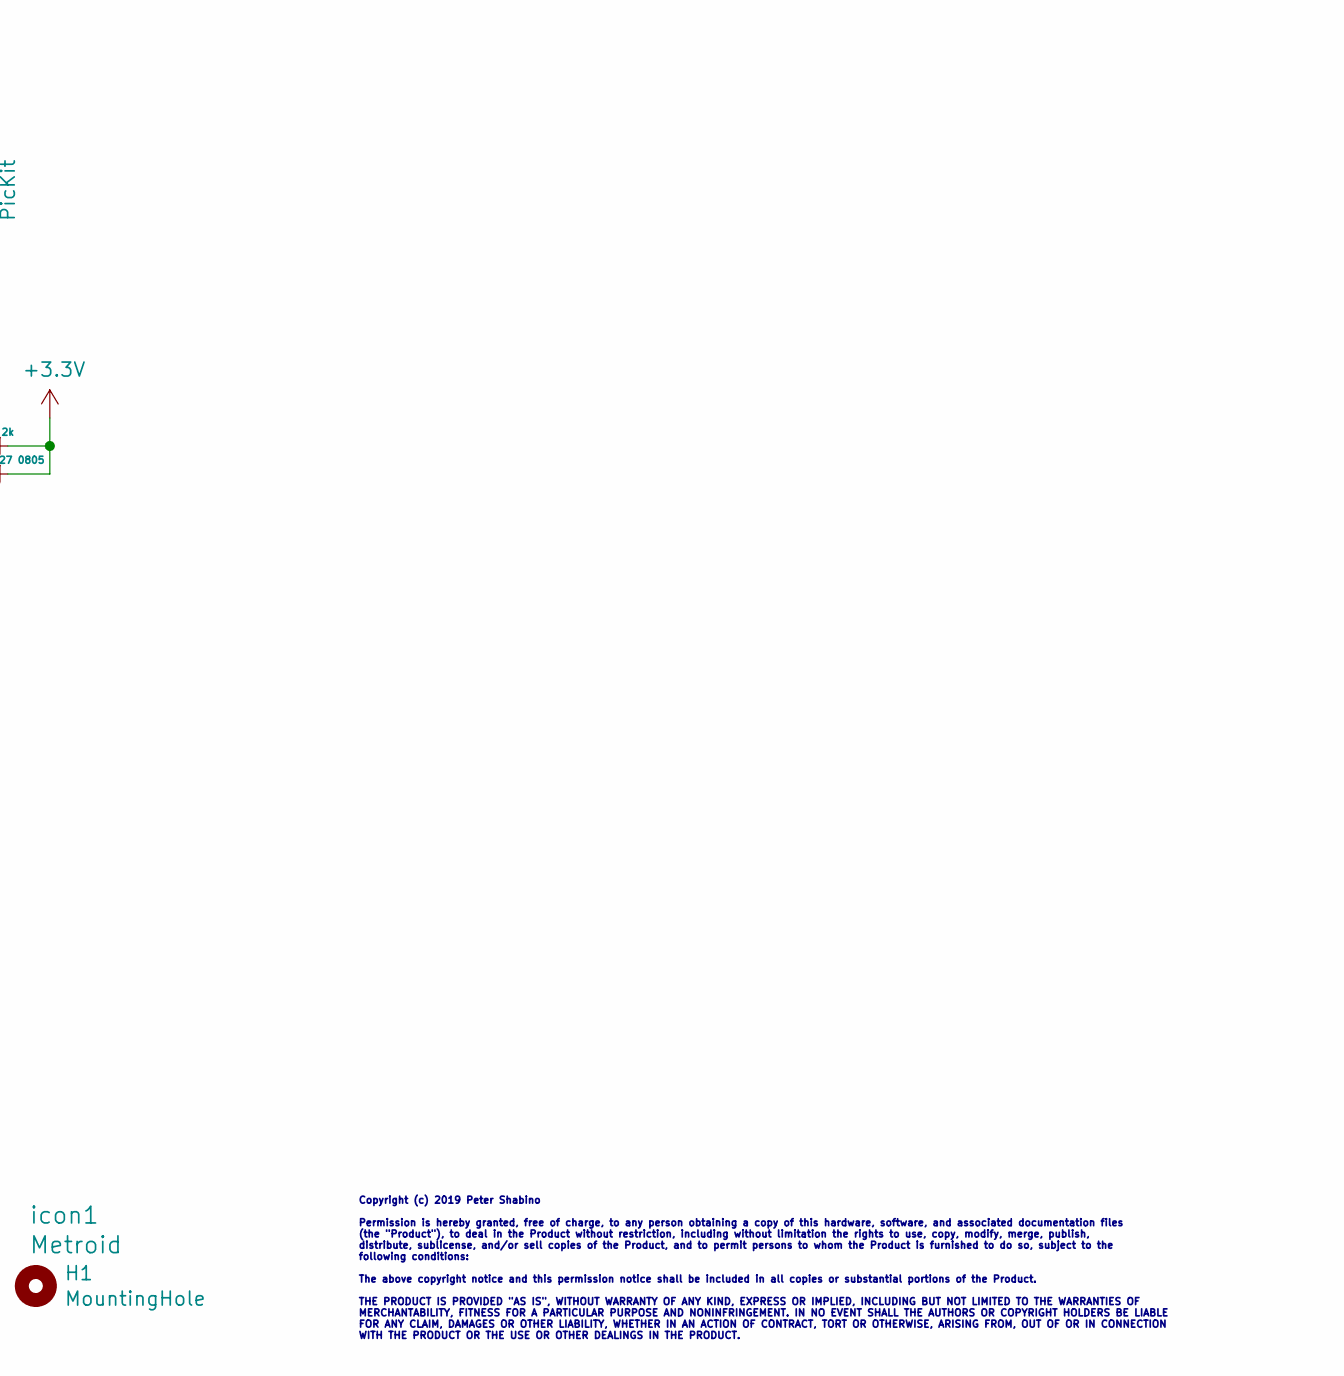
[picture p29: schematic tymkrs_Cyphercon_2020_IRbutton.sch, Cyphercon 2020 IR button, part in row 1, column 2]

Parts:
BT1: BAT-HLD-001
C1: 10uF 1206; C_1206_3216Metric
C2: 0.1uF 0603; C_0603_1608Metric
D1: Red; LED_0603_1608Metric
D2: IR204; LED_D3.0mm_Horizontal_O1.27mm_Z2.0mm_Clear
H1: MountingHole; MountingHole_2.7mm_M2.5
J1: PicKit; PinHeader_1x05_P2.54mm_Vertical
R1: 100k; R_0603_1608Metric
R2: 2k; R_0603_1608Metric
R3: 27 0805; R_0603_1608Metric
SW1: TACT_6MM; PTS645_6mm_tact_sw
U1: PIC16F15313; SOIC-8_3.9x4.9mm_P1.27mm
icon1: Metroid; metroid

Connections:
+3V3: BT1.1 (+), C1.1, C2.1, J1.2, R1.2, R2.1, R3.1, U1.1 (Vdd)
GND: BT1.2 (-), C1.2, C2.2, J1.3, SW1.4, U1.8 (Vss)
unnamed: D1.1 (K), U1.3 (RA4)
unnamed: D1.2 (A), R2.2
unnamed: D2.1 (K), U1.2 (RA5)
unnamed: D2.2 (A), R3.2
unnamed: J1.1, R1.1, SW1.1
unnamed: J1.4, U1.7 (RA0/ICSPDAT)
unnamed: J1.5, U1.6 (RA1/ICSPCLK)
unnamed: SW1.2, U1.4 (RA3/MCLR)

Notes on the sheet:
Copyright (c) 2019 Peter Shabino Permission is hereby granted, free of charge, to any person obtaining a copy of this hardware, software, and associated documentation files (the "Product"), to deal in the Product without restriction, including without limitation the rights to use, copy, modify, mer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
CR2032

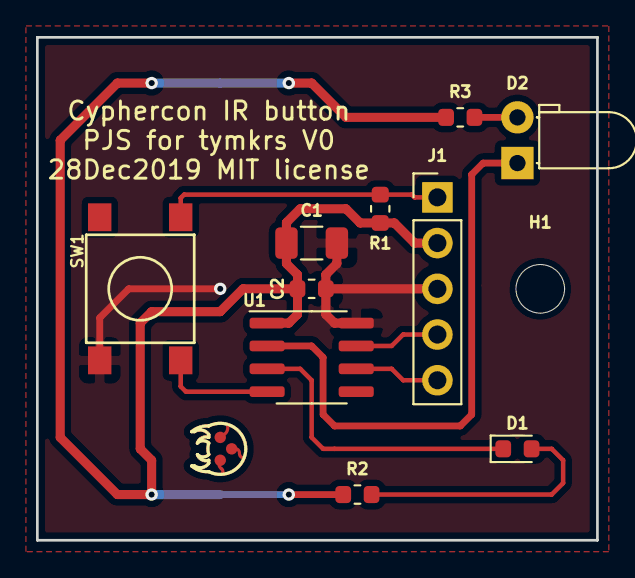
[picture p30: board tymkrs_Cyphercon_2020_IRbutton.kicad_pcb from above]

Board: 2 copper layers, 31.1 x 27.9 mm, 13 parts (1 on the bottom side), 10 nets.

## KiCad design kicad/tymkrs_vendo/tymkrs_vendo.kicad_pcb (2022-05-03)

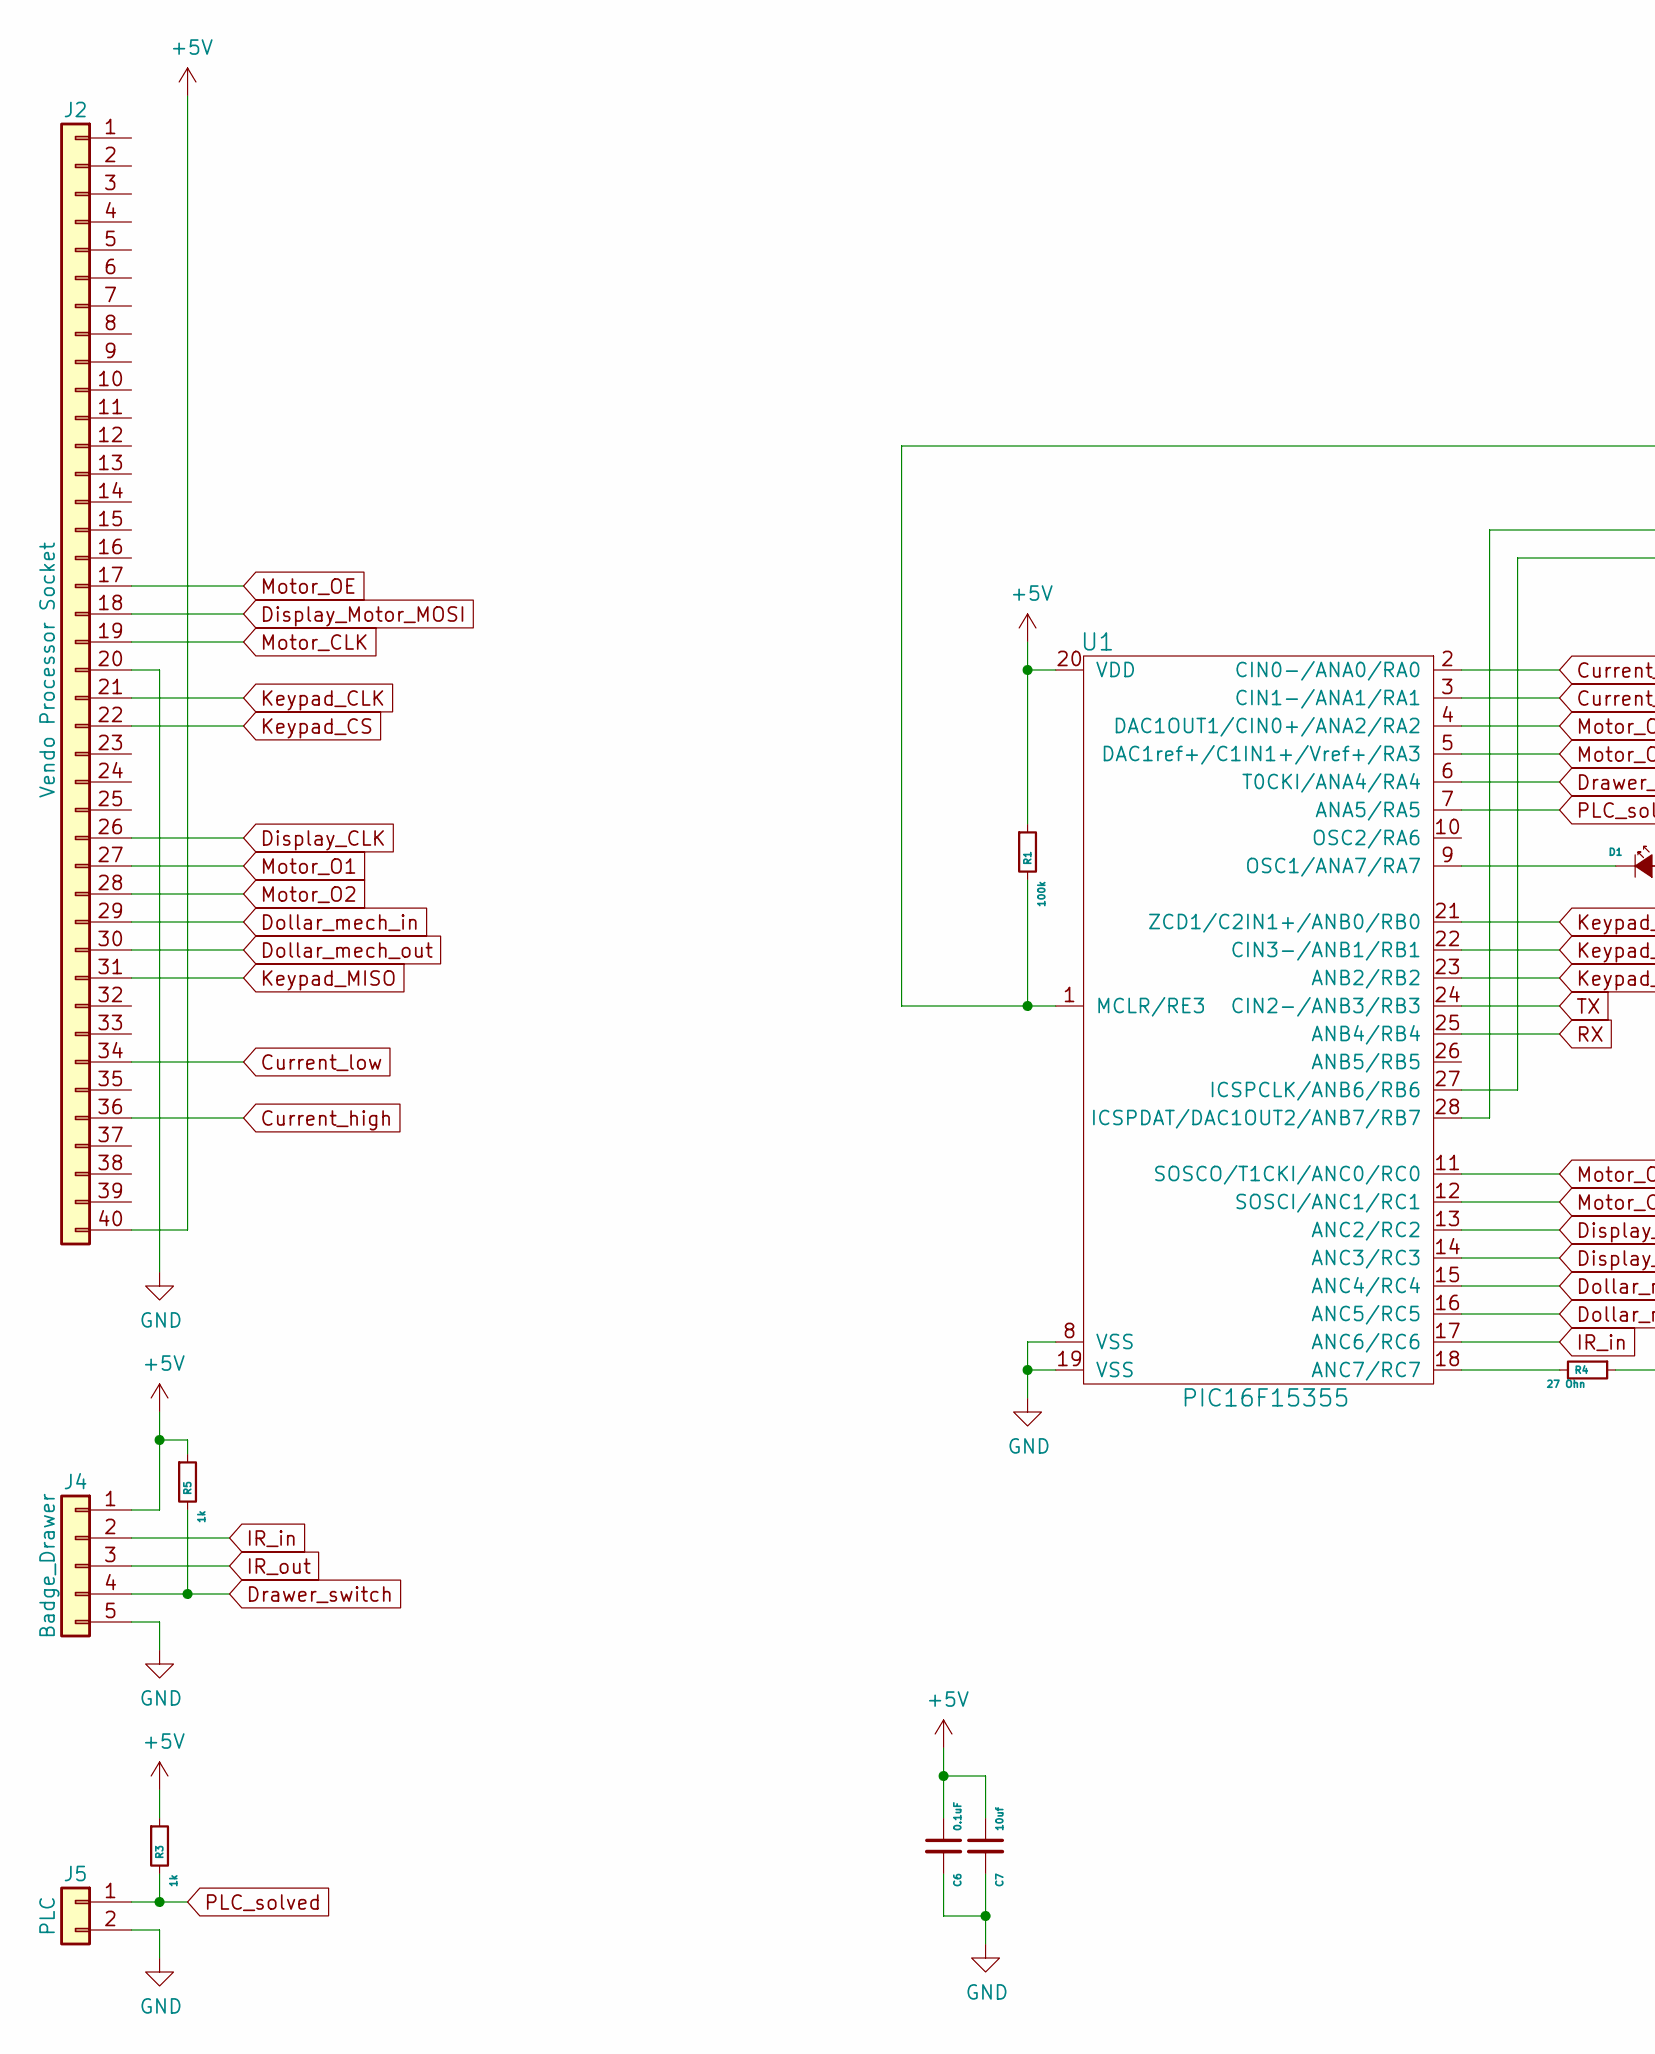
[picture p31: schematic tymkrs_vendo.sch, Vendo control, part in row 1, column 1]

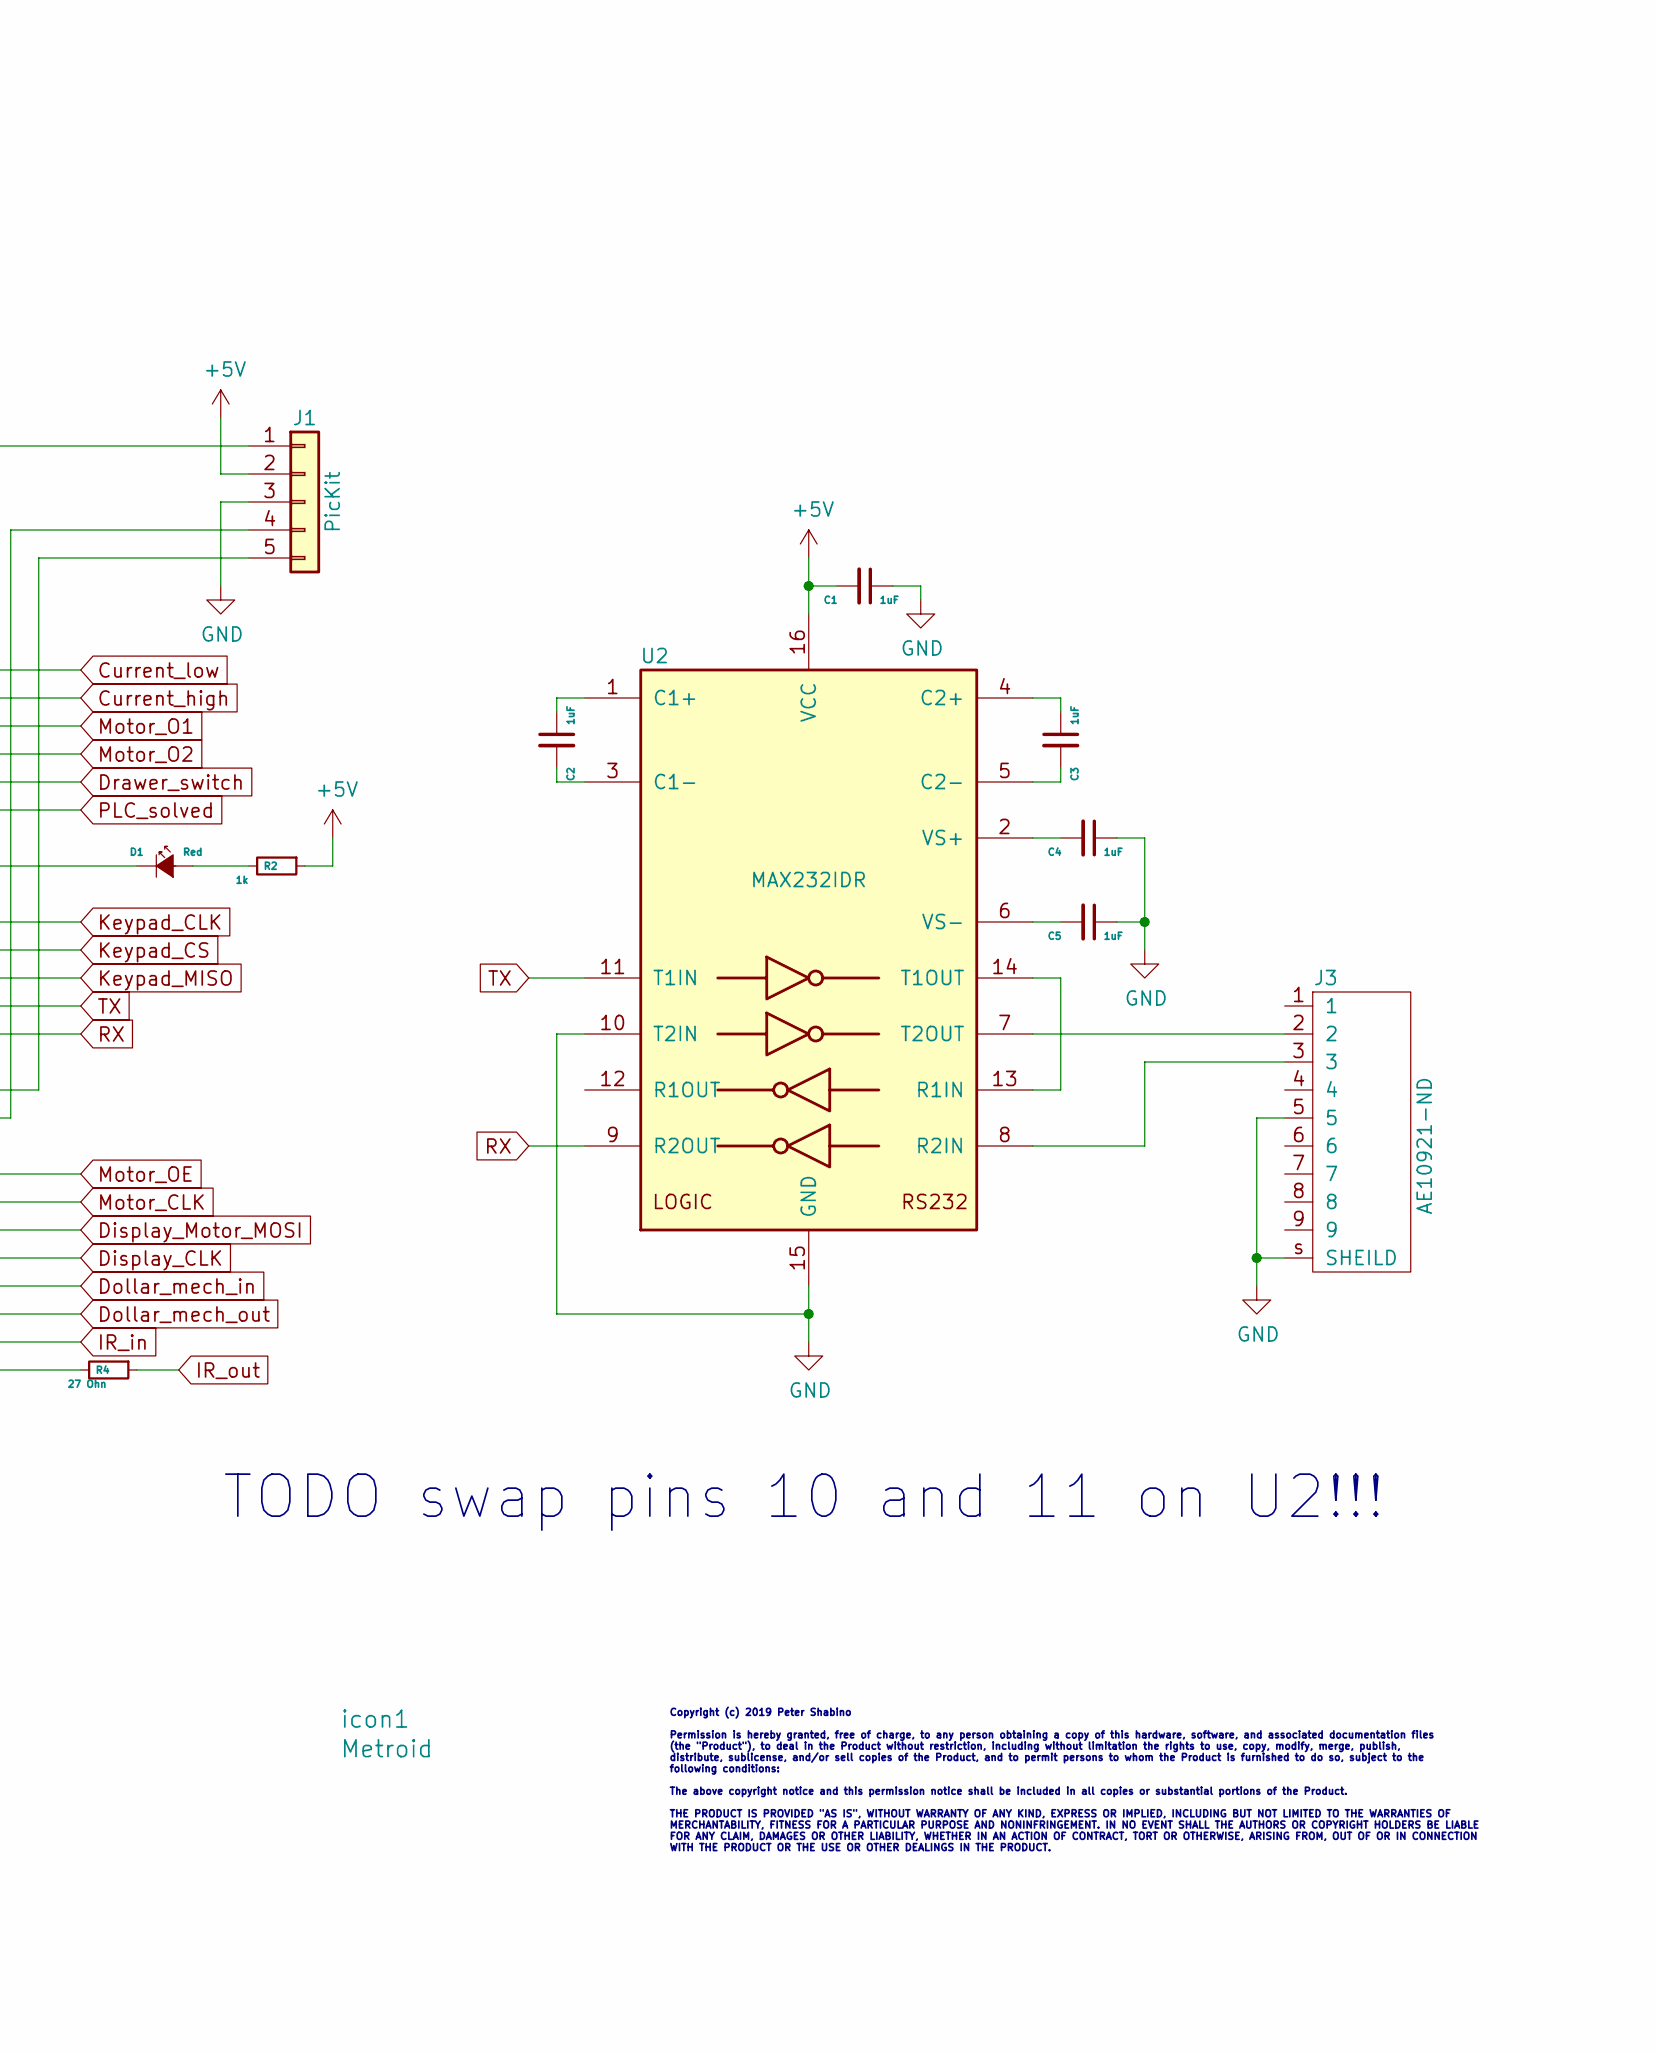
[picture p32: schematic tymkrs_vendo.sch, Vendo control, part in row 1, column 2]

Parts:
C1, C2, C3, C4, C5: 1uF; C_0805_2012Metric
C6: 0.1uF; C_0603_1608Metric
C7: 10uf; C_1206_3216Metric
D1: Red; LED_0603_1608Metric
J1: PicKit; PinHeader_1x05_P2.54mm_Vertical
J2: Vendo Processor Socket; DIP-40_W15.24mm_Socket_LongPads
J3: AE10921-ND; ASSMANN_dsub-9F_RA_AE10921-ND
J4: Badge_Drawer; PinHeader_1x05_P2.54mm_Vertical
J5: PLC; PinHeader_1x02_P2.54mm_Vertical
R1: 100k; R_0603_1608Metric
R2, R3, R5: 1k; R_0603_1608Metric
R4: 27 Ohn; R_0805_2012Metric
U1: PIC16F15355; SOIC-28W_7.5x18.7mm_P1.27mm
U2: MAX232IDR; SOIC-16_3.9x9.9mm_P1.27mm
icon1: Metroid; metroid

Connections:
+5V: C1.2, C6.1, C7.1, J1.2, J2.40, J4.1, R1.1, R2.1, R3.1, R5.1, U1.20 (VDD), U2.16 (VCC)
Current_high: J2.36, U1.3 (CIN1-/ANA1/RA1)
Current_low: J2.34, U1.2 (CIN0-/ANA0/RA0)
Display_CLK: J2.26, U1.14 (ANC3/RC3)
Display_Motor_MOSI: J2.18, U1.13 (ANC2/RC2)
Dollar_mech_in: J2.29, U1.15 (ANC4/RC4)
Dollar_mech_out: J2.30, U1.16 (ANC5/RC5)
Drawer_switch: J4.4, R5.2, U1.6 (T0CKI/ANA4/RA4)
GND: C1.1, C4.1, C5.1, C6.2, C7.2, J1.3, J2.20, J3.5, J3.s (SHEILD), J4.5, J5.2, U1.8 (VSS), U1.19 (VSS), U2.10 (T2IN), U2.15 (GND)
IR_in: J4.2, U1.17 (ANC6/RC6)
IR_out: J4.3, R4.1
Keypad_CLK: J2.21, U1.21 (ZCD1/C2IN1+/ANB0/RB0)
Keypad_CS: J2.22, U1.22 (CIN3-/ANB1/RB1)
Keypad_MISO: J2.31, U1.23 (ANB2/RB2)
Motor_CLK: J2.19, U1.12 (SOSCI/ANC1/RC1)
Motor_O1: J2.27, U1.4 (DAC1OUT1/CIN0+/ANA2/RA2)
Motor_O2: J2.28, U1.5 (DAC1ref+/C1IN1+/Vref+/RA3)
Motor_OE: J2.17, U1.11 (SOSCO/T1CKI/ANC0/RC0)
unnamed: C2.1, U2.1 (C1+)
unnamed: C2.2, U2.3 (C1-)
unnamed: C3.1, U2.4 (C2+)
unnamed: C3.2, U2.5 (C2-)
unnamed: C4.2, U2.2 (VS+)
unnamed: C5.2, U2.6 (VS-)
unnamed: D1.1 (K), U1.9 (OSC1/ANA7/RA7)
unnamed: D1.2 (A), R2.2
unnamed: J1.1, R1.2, U1.1 (MCLR/RE3)
unnamed: J1.4, U1.28 (ICSPDAT/DAC1OUT2/ANB7/RB7)
unnamed: J1.5, U1.27 (ICSPCLK/ANB6/RB6)
unnamed: J3.2, U2.7 (T2OUT)
unnamed: J3.3, U2.8 (R2IN)
unnamed: R4.2, U1.18 (ANC7/RC7)
unnamed: U2.13 (R1IN), U2.14 (T1OUT)
PLC_solved: J5.1, R3.2, U1.7 (ANA5/RA5)
RX: U1.25 (ANB4/RB4), U2.9 (R2OUT)
TX: U1.24 (CIN2-/ANB3/RB3), U2.11 (T1IN)

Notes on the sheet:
Copyright (c) 2019 Peter Shabino Permission is hereby granted, free of charge, to any person obtaining a copy of this hardware, software, and associated documentation files (the "Product"), to deal in the Product without restriction, including without limitation the rights to use, copy, modify, mer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
TODO swap pins 10 and 11 on U2!!!

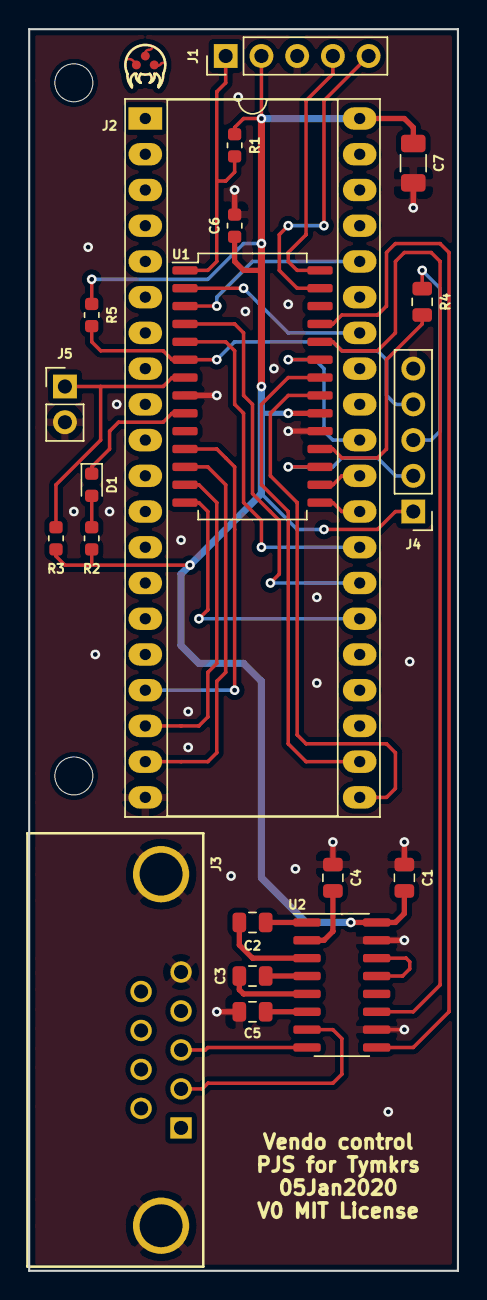
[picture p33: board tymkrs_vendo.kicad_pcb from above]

Board: 2 copper layers, 30.5 x 88.3 mm, 21 parts (0 on the bottom side), 36 nets.

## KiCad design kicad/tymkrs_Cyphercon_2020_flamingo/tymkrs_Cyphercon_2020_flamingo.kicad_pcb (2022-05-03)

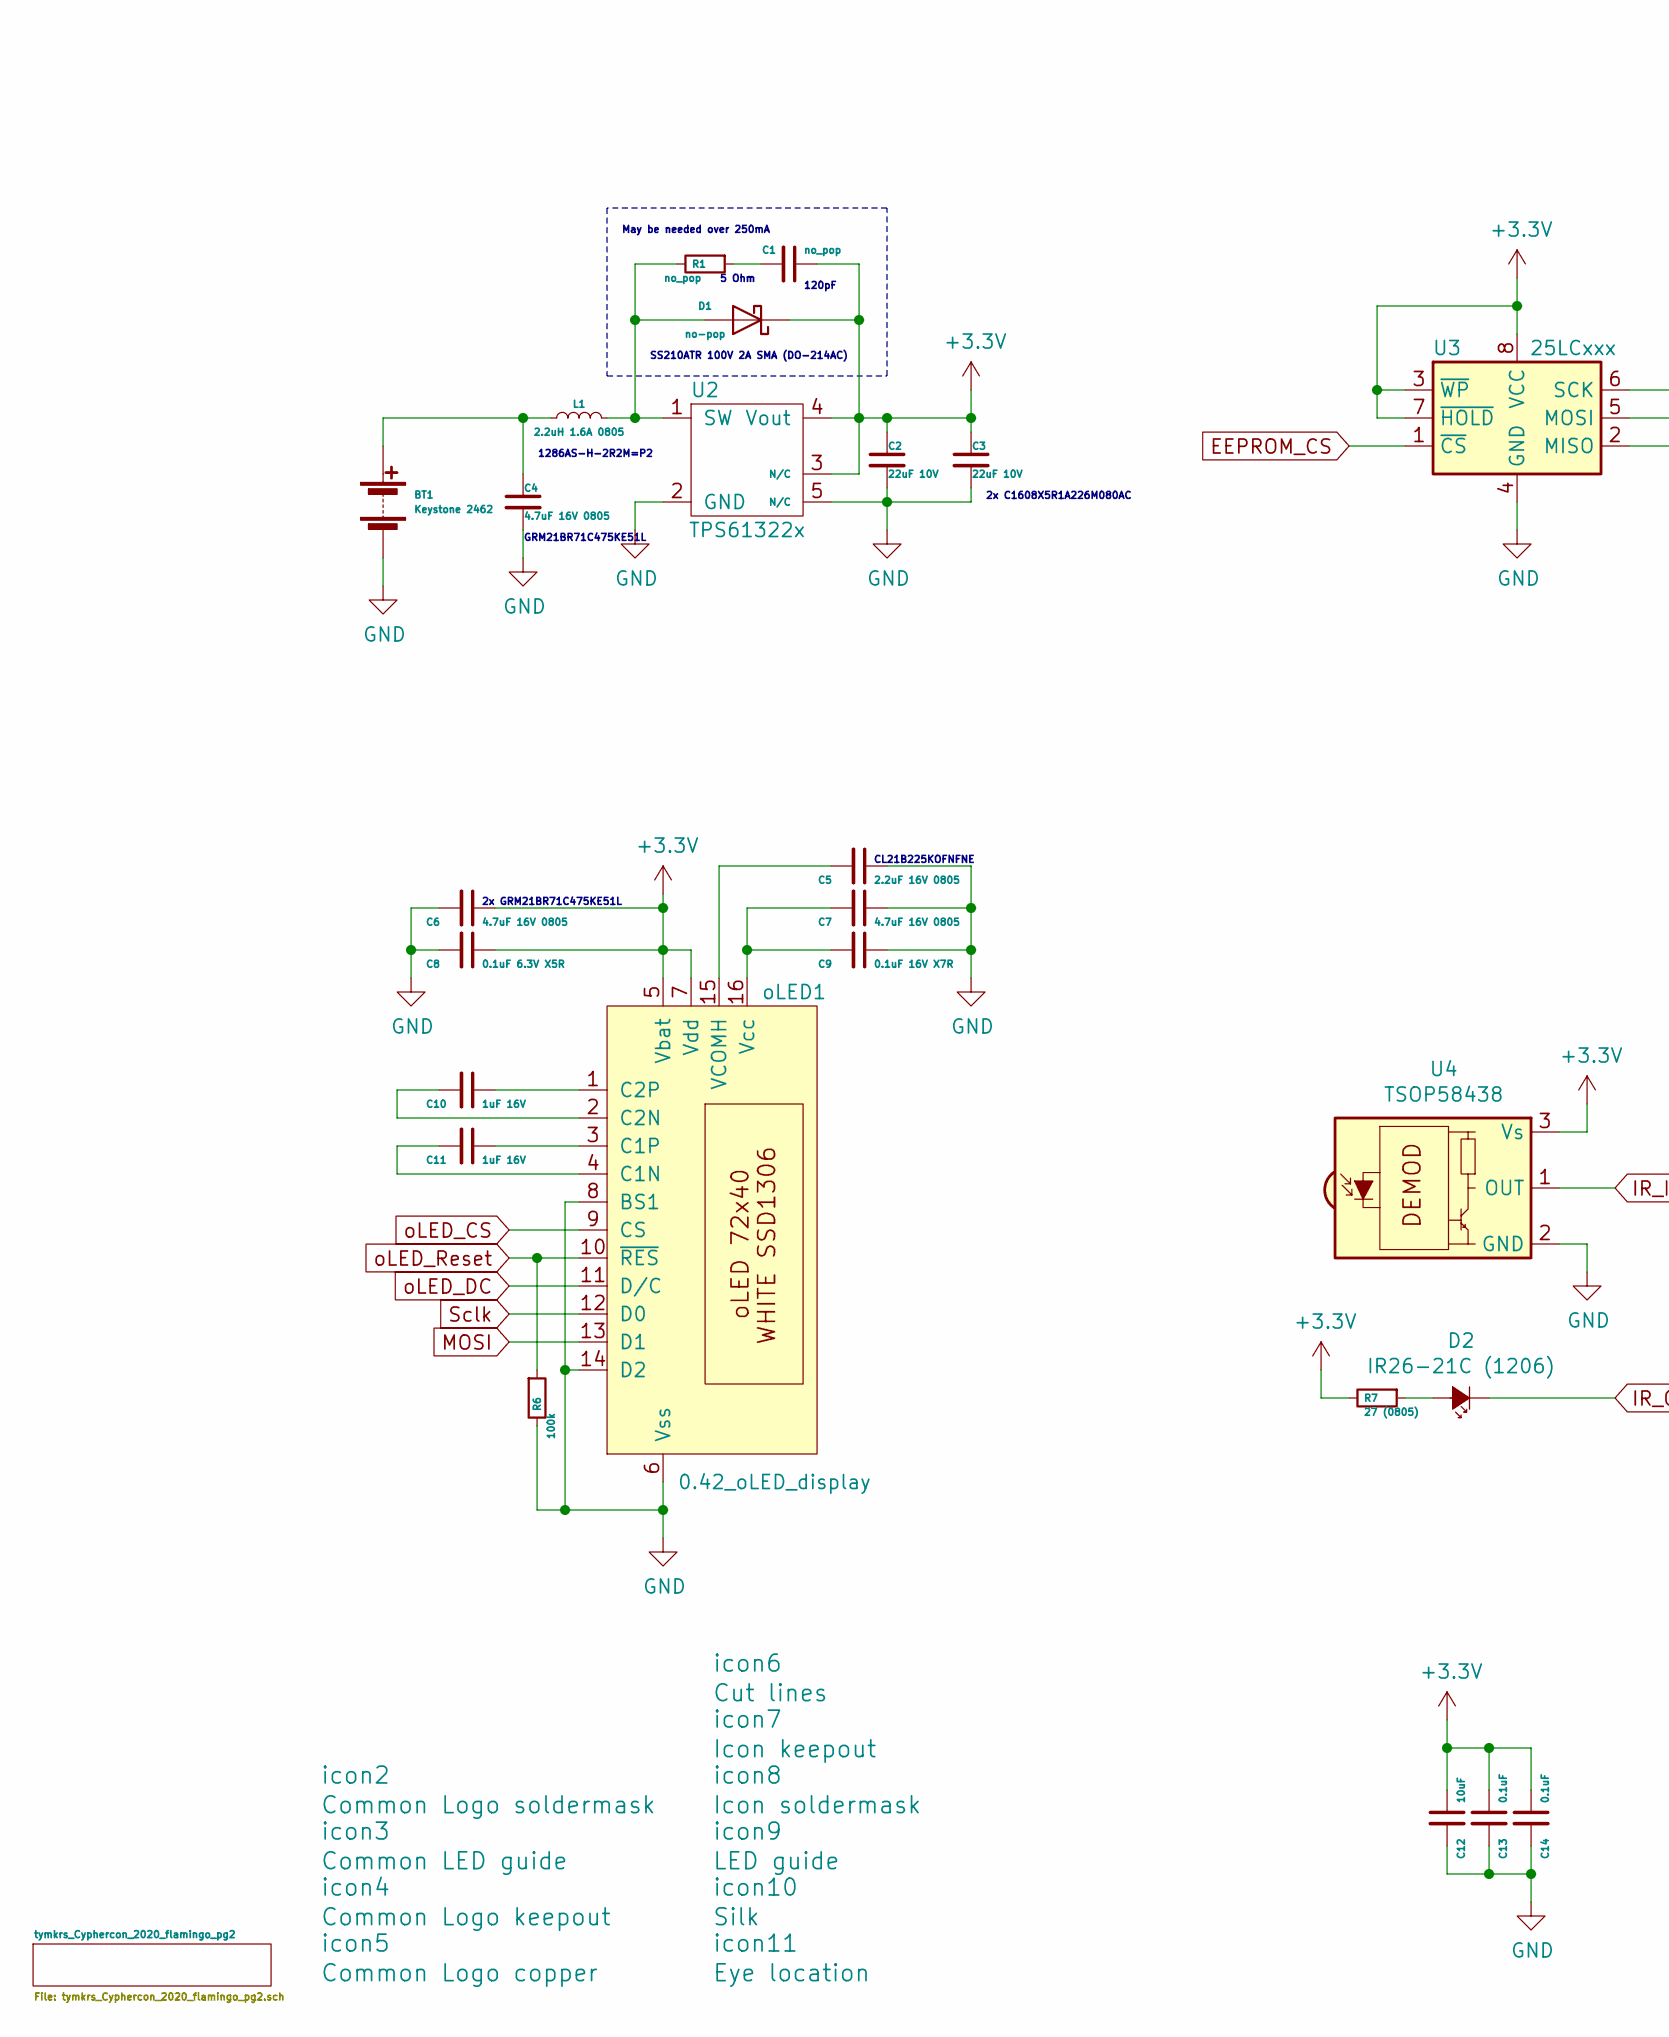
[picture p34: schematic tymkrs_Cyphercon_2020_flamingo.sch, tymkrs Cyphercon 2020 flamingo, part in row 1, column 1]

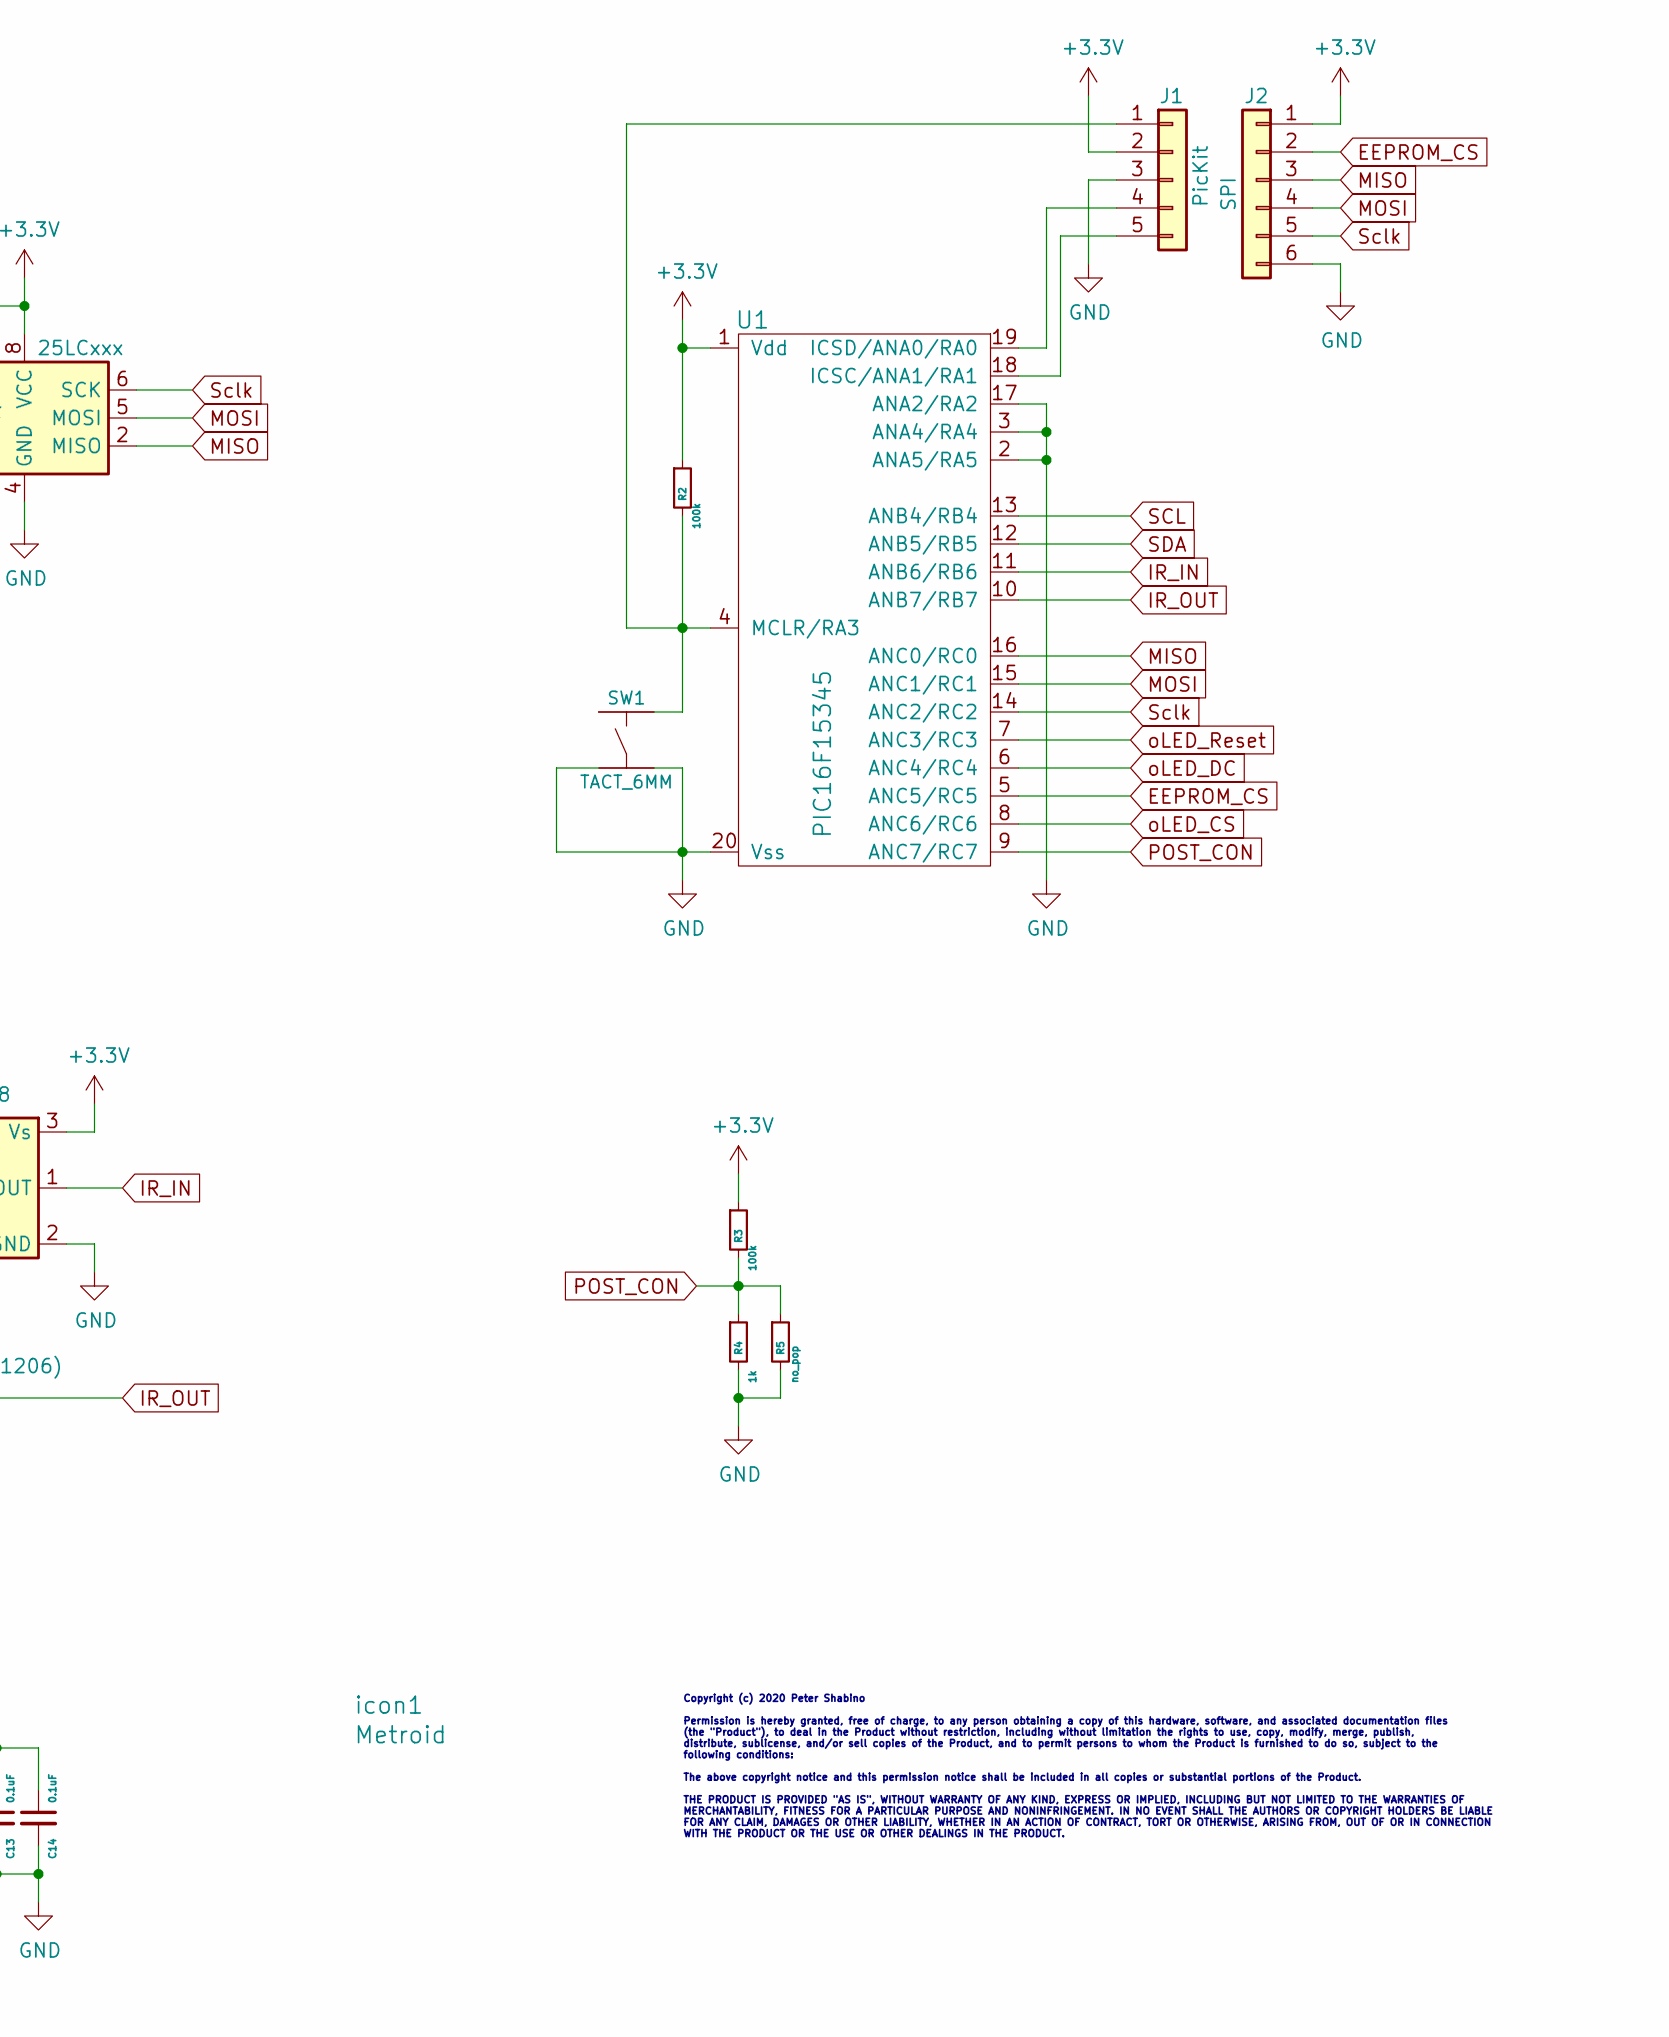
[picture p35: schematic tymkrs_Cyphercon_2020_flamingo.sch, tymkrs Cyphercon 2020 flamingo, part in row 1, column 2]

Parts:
BT1: Keystone 2462; Keystone_2462_2x_AA_no_holes
C1: no_pop; C_0603_1608Metric
C2, C3: 22uF 10V; C_0603_1608Metric
C4, C6, C7: 4.7uF 16V 0805; C_0805_2012Metric
C5: 2.2uF 16V 0805; C_0805_2012Metric
C8: 0.1uF 6.3V X5R; C_0603_1608Metric
C9: 0.1uF 16V X7R; C_0603_1608Metric
C10, C11: 1uF 16V; C_0805_2012Metric
C12: 10uF; C_1206_3216Metric
C13, C14: 0.1uF; C_0603_1608Metric
D1: no-pop; D_SMA
D2: IR26-21C (1206); LED_1206_3216Metric
J1: PicKit; PinHeader_1x05_P2.54mm_Vertical
J2: SPI; PinHeader_1x06_P2.54mm_Vertical
L1: 2.2uH 1.6A 0805; L_0805_2012Metric
R1, R5: no_pop; R_0603_1608Metric
R2, R3, R6: 100k; R_0603_1608Metric
R4: 1k; R_0603_1608Metric
R7: 27 (0805); R_0603_1608Metric
SW1: TACT_6MM; PTS645_6mm_tact_sw
U1: PIC16F15345; SOIC-20W_7.5x12.8mm_P1.27mm
U2: TPS61322x; SOT-23-5
U3: 25LCxxx; SOIC-8_5.275x5.275mm_P1.27mm
U4: TSOP58438; TSOP48
icon1: Metroid; metroid
icon2: Common Logo soldermask; cypheron2020_common_logo_soldermask
icon3: Common LED guide; cypheron2020_common_logo_led_guide
icon4: Common Logo keepout; cypheron2020_common_logo_copper_flood_keepout
icon5: Common Logo copper; cypheron2020_common_logo_copper_add
icon6: Cut lines; cypheron2020_flamingo_cuts
icon7: Icon keepout; cypheron2020_flamingo_icons_copperkeepout
icon8: Icon soldermask; cypheron2020_flamingo_icons_soldermask
icon9: LED guide; cypheron2020_flamingo_led_guide
icon10: Silk; cypheron2020_flamingo_silk
icon11: Eye location; cypheron2020_flamingo_eye
oLED1: 0.42_oLED_display; oLED_0.42_rev

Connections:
+3V3: C1.1, C2.1, C3.1, C6.1, C8.1, C12.1, C13.1, C14.1, D1.1 (K), J1.2, J2.1, R2.1, R3.1, R7.2, U1.1 (Vdd), U2.3 (N/C), U2.4 (Vout), U3.3 (~WP), U3.7 (~HOLD), U3.8 (VCC), U4.3 (Vs), oLED1.5 (Vbat), oLED1.7 (Vdd); also elsewhere on the board
EEPROM_CS: J2.2, U1.5 (ANC5/RC5), U3.1 (~CS)
GND: BT1.2 (-), C2.2, C3.2, C4.2, C5.1, C6.2, C7.1, C8.2, C9.1, C12.2, C13.2, C14.2, J1.3, J2.6, R4.2, R5.2, R6.2, SW1.3, SW1.4, U1.2 (ANA5/RA5), U1.3 (ANA4/RA4), U1.17 (ANA2/RA2), U1.20 (Vss), U2.2 (GND), U2.5 (N/C), U3.4 (GND), U4.2 (GND), oLED1.6 (Vss), oLED1.8 (BS1), oLED1.14 (D2); also elsewhere on the board
IR_IN: U1.11 (ANB6/RB6), U4.1 (OUT)
IR_OUT: D2.1 (K), U1.10 (ANB7/RB7)
MISO: J2.3, U1.16 (ANC0/RC0), U3.2 (MISO)
MOSI: J2.4, U1.15 (ANC1/RC1), U3.5 (MOSI), oLED1.13 (D1)
unnamed: BT1.1 (+), C4.1, L1.1
unnamed: C1.2, R1.1
unnamed: C5.2, oLED1.15 (VCOMH)
unnamed: C7.2, C9.2, oLED1.16 (Vcc)
unnamed: C10.1, oLED1.1 (C2P)
unnamed: C10.2, oLED1.2 (C2N)
unnamed: C11.1, oLED1.3 (C1P)
unnamed: C11.2, oLED1.4 (C1N)
unnamed: D1.2 (A), L1.2, R1.2, U2.1 (SW)
unnamed: D2.2 (A), R7.1
unnamed: J1.1, R2.2, SW1.2, U1.4 (MCLR/RA3)
unnamed: J1.4, U1.19 (ICSD/ANA0/RA0)
unnamed: J1.5, U1.18 (ICSC/ANA1/RA1)
POST_CON: R3.2, R4.1, R5.1, U1.9 (ANC7/RC7)
SCL: U1.13 (ANB4/RB4); also elsewhere on the board
SDA: U1.12 (ANB5/RB5); also elsewhere on the board
Sclk: J2.5, U1.14 (ANC2/RC2), U3.6 (SCK), oLED1.12 (D0)
oLED_CS: U1.8 (ANC6/RC6), oLED1.9 (CS)
oLED_DC: U1.6 (ANC4/RC4), oLED1.11 (D/C)
oLED_Reset: R6.1, U1.7 (ANC3/RC3), oLED1.10 (~RES)

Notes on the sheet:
Copyright (c) 2020 Peter Shabino Permission is hereby granted, free of charge, to any person obtaining a copy of this hardware, software, and associated documentation files (the "Product"), to deal in the Product without restriction, including without limitation the rights to use, copy, modify, mer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
SS210ATR 100V 2A SMA (DO-214AC)
120pF
5 Ohm
May be needed over 250mA
1286AS-H-2R2M=P2
GRM21BR71C475KE51L
2x C1608X5R1A226M080AC
2x GRM21BR71C475KE51L
CL21B225KOFNFNE

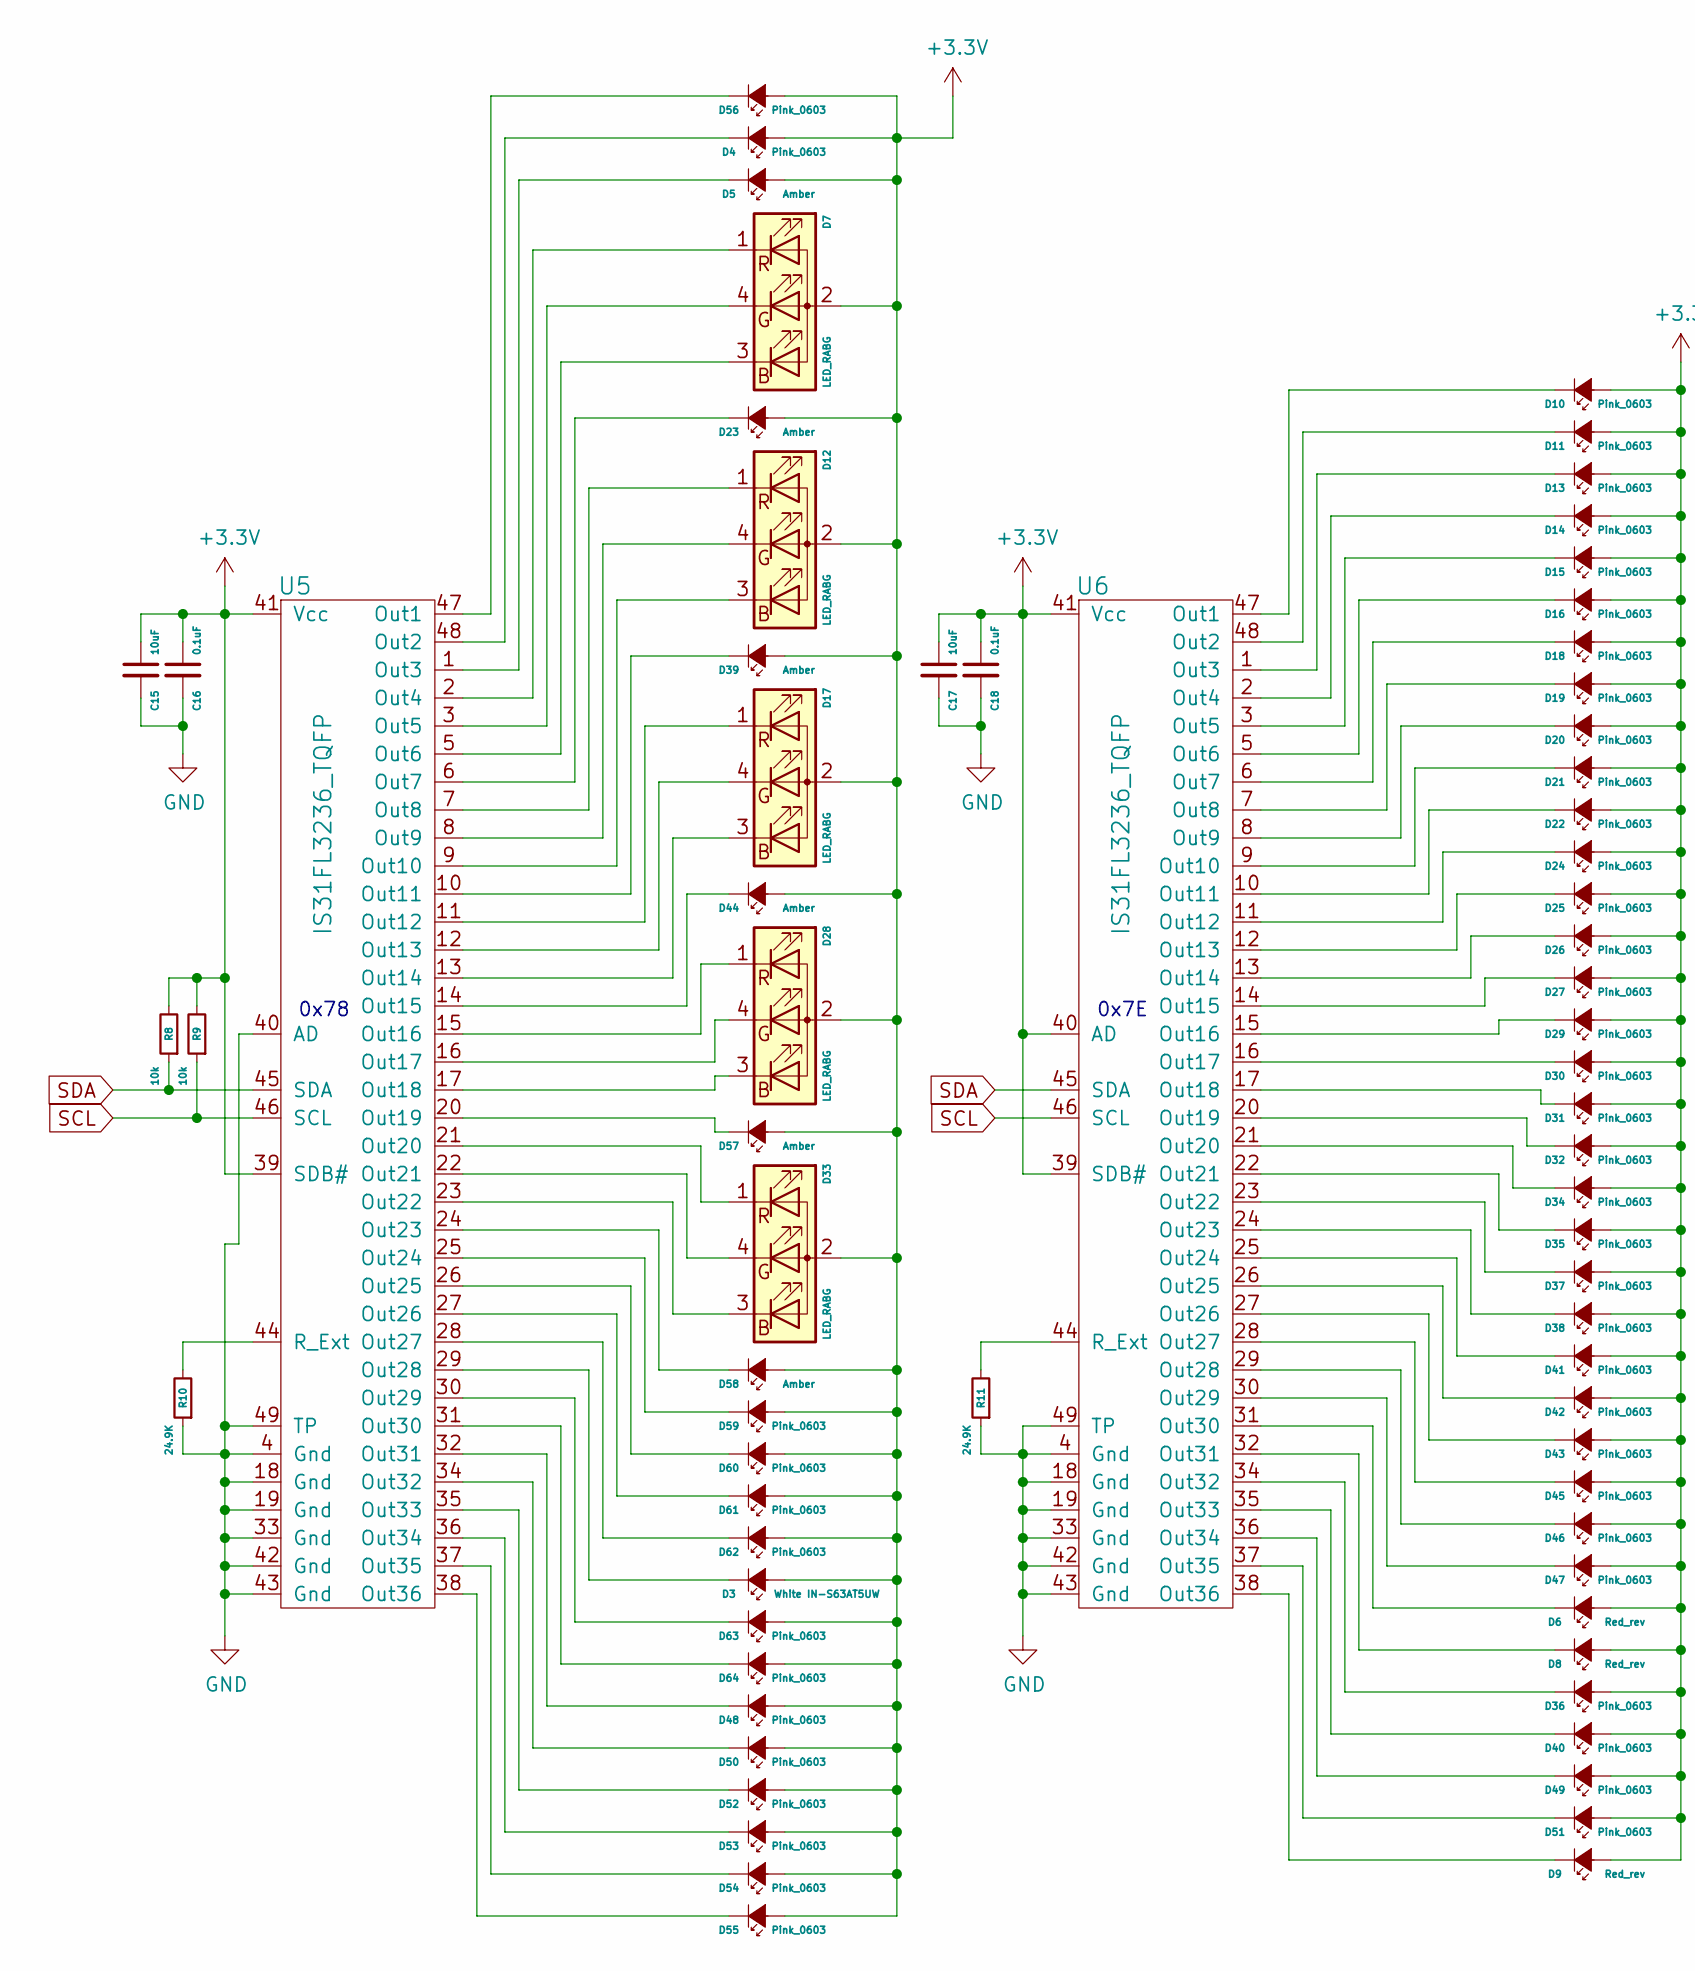
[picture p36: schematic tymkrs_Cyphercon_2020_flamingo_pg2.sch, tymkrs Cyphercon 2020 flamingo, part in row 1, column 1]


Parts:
C15, C17: 10uF; C_1206_3216Metric
C16, C18: 0.1uF; C_0603_1608Metric
D3: White IN-S63AT5UW; LED_0603_1608Metric
D4, D10, D11, D13, D14, D15, D16, D18, D19, D20, D21, D22, D24, D25, D26, D27, D29, D30, D31, D32, D34, D35, D36, D37, D38, D40, D41, D42, D43, D45, D46, D47, D48, D49, D50, D51, D52, D53, D54, D55, D56, D59, D60, D61, D62, D63, D64: Pink_0603; LED_0603_1608Metric
D5, D23, D39, D44, D57, D58: Amber; XZ__K45WT-9
D6, D8, D9: Red_rev; XZ__K45WT-9
D7, D12, D17, D28, D33: LED_RABG; XZMDKCBDDG45S-9
R8, R9: 10k; R_0603_1608Metric
R10, R11: 24.9K; R_0603_1608Metric
U5, U6: IS31FL3236_TQFP; TQFP-48-1EP_7x7mm_P0.5mm_EP3.5x3.5mm

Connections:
+3V3: C15.1, C16.1, C17.1, C18.1, D3.2 (A), D4.2 (A), D5.2 (A), D6.2 (A), D7.2 (A), D8.2 (A), D9.2 (A), D10.2 (A), D11.2 (A), D12.2 (A), D13.2 (A), D14.2 (A), D15.2 (A), D16.2 (A), D17.2 (A), D18.2 (A), D19.2 (A), D20.2 (A), D21.2 (A), D22.2 (A), D23.2 (A), D24.2 (A), D25.2 (A), D26.2 (A), D27.2 (A), D28.2 (A), D29.2 (A), D30.2 (A), D31.2 (A), D32.2 (A), D33.2 (A), D34.2 (A), D35.2 (A), D36.2 (A), D37.2 (A), D38.2 (A), D39.2 (A), D40.2 (A), D41.2 (A), D42.2 (A), D43.2 (A), D44.2 (A), D45.2 (A), D46.2 (A), D47.2 (A), D48.2 (A), D49.2 (A), D50.2 (A), D51.2 (A), D52.2 (A), D53.2 (A), D54.2 (A), D55.2 (A), D56.2 (A), D57.2 (A), D58.2 (A), D59.2 (A), D60.2 (A), D61.2 (A), D62.2 (A), D63.2 (A), D64.2 (A), R8.2, R9.2, U5.39 (SDB#), U5.41 (Vcc), U6.39 (SDB#), U6.40 (AD), U6.41 (Vcc); also elsewhere on the board
GND: C15.2, C16.2, C17.2, C18.2, R10.1, R11.1, U5.4 (Gnd), U5.18 (Gnd), U5.19 (Gnd), U5.33 (Gnd), U5.40 (AD), U5.42 (Gnd), U5.43 (Gnd), U5.49 (TP), U6.4 (Gnd), U6.18 (Gnd), U6.19 (Gnd), U6.33 (Gnd), U6.42 (Gnd), U6.43 (Gnd), U6.49 (TP); also elsewhere on the board
unnamed: D3.1 (K), U5.29 (Out28)
unnamed: D4.1 (K), U5.48 (Out2)
unnamed: D5.1 (K), U5.1 (Out3)
unnamed: D6.1 (K), U6.31 (Out30)
unnamed: D7.1 (RK), U5.2 (Out4)
unnamed: D7.3 (BK), U5.5 (Out6)
unnamed: D7.4 (GK), U5.3 (Out5)
unnamed: D8.1 (K), U6.32 (Out31)
unnamed: D9.1 (K), U6.38 (Out36)
unnamed: D10.1 (K), U6.47 (Out1)
unnamed: D11.1 (K), U6.48 (Out2)
unnamed: D12.1 (RK), U5.7 (Out8)
unnamed: D12.3 (BK), U5.9 (Out10)
unnamed: D12.4 (GK), U5.8 (Out9)
unnamed: D13.1 (K), U6.1 (Out3)
unnamed: D14.1 (K), U6.2 (Out4)
unnamed: D15.1 (K), U6.3 (Out5)
unnamed: D16.1 (K), U6.5 (Out6)
unnamed: D17.1 (RK), U5.11 (Out12)
unnamed: D17.3 (BK), U5.13 (Out14)
unnamed: D17.4 (GK), U5.12 (Out13)
unnamed: D18.1 (K), U6.6 (Out7)
unnamed: D19.1 (K), U6.7 (Out8)
unnamed: D20.1 (K), U6.8 (Out9)
unnamed: D21.1 (K), U6.9 (Out10)
unnamed: D22.1 (K), U6.10 (Out11)
unnamed: D23.1 (K), U5.6 (Out7)
unnamed: D24.1 (K), U6.11 (Out12)
unnamed: D25.1 (K), U6.12 (Out13)
unnamed: D26.1 (K), U6.13 (Out14)
unnamed: D27.1 (K), U6.14 (Out15)
unnamed: D28.1 (RK), U5.15 (Out16)
unnamed: D28.3 (BK), U5.17 (Out18)
unnamed: D28.4 (GK), U5.16 (Out17)
unnamed: D29.1 (K), U6.15 (Out16)
unnamed: D30.1 (K), U6.16 (Out17)
unnamed: D31.1 (K), U6.17 (Out18)
unnamed: D32.1 (K), U6.20 (Out19)
unnamed: D33.1 (RK), U5.21 (Out20)
unnamed: D33.3 (BK), U5.23 (Out22)
unnamed: D33.4 (GK), U5.22 (Out21)
unnamed: D34.1 (K), U6.21 (Out20)
unnamed: D35.1 (K), U6.22 (Out21)
unnamed: D36.1 (K), U6.34 (Out32)
unnamed: D37.1 (K), U6.23 (Out22)
unnamed: D38.1 (K), U6.24 (Out23)
unnamed: D39.1 (K), U5.10 (Out11)
unnamed: D40.1 (K), U6.35 (Out33)
unnamed: D41.1 (K), U6.25 (Out24)
unnamed: D42.1 (K), U6.26 (Out25)
unnamed: D43.1 (K), U6.27 (Out26)
unnamed: D44.1 (K), U5.14 (Out15)
unnamed: D45.1 (K), U6.28 (Out27)
unnamed: D46.1 (K), U6.29 (Out28)
unnamed: D47.1 (K), U6.30 (Out29)
unnamed: D48.1 (K), U5.32 (Out31)
unnamed: D49.1 (K), U6.36 (Out34)
unnamed: D50.1 (K), U5.34 (Out32)
unnamed: D51.1 (K), U6.37 (Out35)
unnamed: D52.1 (K), U5.35 (Out33)
unnamed: D53.1 (K), U5.36 (Out34)
unnamed: D54.1 (K), U5.37 (Out35)
unnamed: D55.1 (K), U5.38 (Out36)
unnamed: D56.1 (K), U5.47 (Out1)
unnamed: D57.1 (K), U5.20 (Out19)
unnamed: D58.1 (K), U5.24 (Out23)
unnamed: D59.1 (K), U5.25 (Out24)
unnamed: D60.1 (K), U5.26 (Out25)
unnamed: D61.1 (K), U5.27 (Out26)
unnamed: D62.1 (K), U5.28 (Out27)
unnamed: D63.1 (K), U5.30 (Out29)
unnamed: D64.1 (K), U5.31 (Out30)
unnamed: R10.2, U5.44 (R_Ext)
unnamed: R11.2, U6.44 (R_Ext)
SCL: R9.1, U5.46 (SCL), U6.46 (SCL); also elsewhere on the board
SDA: R8.1, U5.45 (SDA), U6.45 (SDA); also elsewhere on the board

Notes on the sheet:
Copyright (c) 2020 Peter Shabino Permission is hereby granted, free of charge, to any person obtaining a copy of this hardware, software, and associated documentation files (the "Product"), to deal in the Product without restriction, including without limitation the rights to use, copy, modify, mer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
0x78
0x7E



Board: 2 copper layers, 77.2 x 187.6 mm, 114 parts (57 on the bottom side), 101 nets.

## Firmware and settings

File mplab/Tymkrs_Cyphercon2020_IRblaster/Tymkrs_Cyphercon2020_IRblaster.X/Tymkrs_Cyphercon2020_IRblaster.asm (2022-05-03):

;#########################################################################################################################################################
;Copyright (c) 2022 Peter Shabino
;
;Permission is hereby granted, free of charge, to any person obtaining a copy of this hardware, software, and associated documentation files 
;(the "Product"), to deal in the Product without restriction, including without limitation the rights to use, copy, modify, merge, publish, 
;distribute, sublicense, and/or sell copies of the Product, and to permit persons to whom the Product is furnished to do so, subject to the 
;following conditions:
;
;The above copyright notice and this permission notice shall be included in all copies or substantial portions of the Product.
;
;THE PRODUCT IS PROVIDED "AS IS", WITHOUT WARRANTY OF ANY KIND, EXPRESS OR IMPLIED, INCLUDING BUT NOT LIMITED TO THE WARRANTIES OF 
;MERCHANTABILITY, FITNESS FOR A PARTICULAR PURPOSE AND NONINFRINGEMENT. IN NO EVENT SHALL THE AUTHORS OR COPYRIGHT HOLDERS BE LIABLE 
;FOR ANY CLAIM, DAMAGES OR OTHER LIABILITY, WHETHER IN AN ACTION OF CONTRACT, TORT OR OTHERWISE, ARISING FROM, OUT OF OR IN CONNECTION 
;WITH THE PRODUCT OR THE USE OR OTHER DEALINGS IN THE PRODUCT.
;#########################################################################################################################################################
; 07JAN2020 V0 PJS New 

	
#define	CODE_VER_STRING "Peter Shabino 23Jan2022 code for tymkrs Cyphercon 2020 IRblaster V0 www.wire2wire.org!" ;Just in ROM !!! update vars below with true level!!
ver		equ	0x00

; enable debug code 
;#define debug
		
; NOTES
; SAF is high endurance flash (128 words) at the end of flash. Not usable as program space when enabled in config words 
; http://ww1.microchip.com/downloads/en/DeviceDoc/PIC16(L)F15354_55%20Data%20Sheet%2040001853C.pdf	

;****************************************************************************************
; port list [SOIC14]
; Vss(14)
; Vdd(1)
; RA0(13)	[ICSPDAT] - key switch 
; RA1(12)	[ISPCLK] - endstop
; RA2(11)	
; RA3(4)	[MCLR] 
; RA4(3)	IR_IN - start button
; RA5(2)	IR_OUT
; RC0(10)	TX - motor
; RC1(9)	RX - button LED	
; RC2(8)	
; RC3(7)	
; RC4(6)	Red LED
; RC5(5)	Green LED
;****************************************************************************************


; PIC16F15324 Configuration Bit Settings
#include "p16f15324.inc"
; CONFIG1
; __config 0xFF8C
 __CONFIG _CONFIG1, _FEXTOSC_OFF & _RSTOSC_HFINT32 & _CLKOUTEN_OFF & _CSWEN_ON & _FCMEN_ON
; CONFIG2
; __config 0xF7DC
 __CONFIG _CONFIG2, _MCLRE_OFF & _PWRTE_ON & _LPBOREN_ON & _BOREN_ON & _BORV_LO & _ZCD_OFF & _PPS1WAY_OFF & _STVREN_ON
; CONFIG3
; __config 0xFF9F
 __CONFIG _CONFIG3, _WDTCPS_WDTCPS_31 & _WDTE_OFF & _WDTCWS_WDTCWS_7 & _WDTCCS_SC
; CONFIG4
; __config 0xDFFF
 __CONFIG _CONFIG4, _BBSIZE_BB512 & _BBEN_OFF & _SAFEN_OFF & _WRTAPP_OFF & _WRTB_OFF & _WRTC_OFF & _WRTSAF_OFF & _LVP_OFF
; CONFIG5
; __config 0xFFFE
 __CONFIG _CONFIG5, _CP_ON
 
 
 
;------------------
; constants
;------------------	
IR_PULSE_WIDTH	equ 0x15		; pulse width set to 10% (0x69 = 50%, 0x35 = 25%, 0x15 = 10%, 0x0A = 5%)

;------------------
; vars (0x20 - 0x6f) bank 0
;------------------
delay			equ	0x20
delay0			equ	0x21
delay1			equ	0x22
						
;------------------
; vars (0xA0 - 0xef) bank 1
;------------------

;------------------
; vars (0x120 - 0x16f) bank 2
;------------------
			
;------------------
; vars (0x1A0 - 0x1ef) bank 3
;------------------

;------------------
; vars (0x220 - 0x26f) bank 4
;------------------

;------------------
; vars (0x2A0 - 02xef) bank 5
;------------------

;------------------
; vars (0x320 - 0x32F) bank 6 
;------------------
		
;------------------
; vars (0x70 - 0x7F) global regs
;------------------
gtemp			equ	0x70
 
;put the following at address 0000h
	org     0000h
	goto    START			    ;vector to initialization sequence

;###########################################################################################################################
; intrupt routine
;###########################################################################################################################
	;put the following at address 0004h
	org     0004h	
	; following regs are autosaved
	; W
	; STATUS (except TO and PD)
	; BSR
	; FSR
	; PCLATH
	
	
	retfie
;###########################################################################################################################
; end of IRQ code
;###########################################################################################################################	
	
START
	; init crap
	;------------------
	clrf    BSR					; bank 0
	;------------------
	clrf	INTCON			    ; disable interupts
	movlw	0x00				; set RA5 low to turn off IR LED. Rest low
	movwf	LATA			    ; Set4, Set3 to low to turn off leds
	movlw	0x20				
	movwf	LATC			    ; Turn RC5 high to turn off green led, RC4 low to turn on red led. Rest low

	movlw	0x13				; Button_in, key_in, and endstop_in are inputs, rest outputs (keep unused lines from flotating by driving low)
	movwf	TRISA			    ; 0 = output 
	movlw	0x00				; all as outputs 
	movwf	TRISC			    ; 0 = output	

		
	; clear vars first 80 bytes (control structures) 
	movlw	0x20			; start of bank 0 vars
	movwf	FSR0L
	clrf	FSR0H
	movlw	0x50			; clear all of bank other than globals
	movwf	gtemp
init_bank0_loop
	clrf	INDF0
	incf	FSR0L, F
	decfsz	gtemp, F
	goto	init_bank0_loop
	
	
	;------------------
	movlw	d'5'
	movwf	BSR		
	;------------------
	; set up timer 2 to roll over on a 38kHz period (37.9 something)
	clrf	TMR2
	movlw	0xD3			    ; period reg 
	movwf	PR2
	movlw	0x01			    ; select Fosc/4 as the input clock
	movwf	T2CLKCON
	clrf	T2HLT			    ; mode 0 (free run standard) 
	clrf	T2RST			    ; not used
	movlw	0x80			    ; timer 2 on, 1:1 pre, 1:1 post
	movwf	T2CON

	;------------------
	movlw	d'6'
	movwf	BSR		
	;------------------	
	; set up PWM engine
	movlw	IR_PULSE_WIDTH
	movwf	PWM5DCH
	movlw	0xC0
	movwf	PWM5DCL
	movlw	0x80			    ; engine on, active high
	movwf	PWM5CON
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

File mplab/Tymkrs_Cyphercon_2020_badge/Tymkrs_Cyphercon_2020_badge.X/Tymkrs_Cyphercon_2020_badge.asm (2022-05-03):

;#########################################################################################################################################################
;Copyright (c) 2020 Peter Shabino
;
;Permission is hereby granted, free of charge, to any person obtaining a copy of this hardware, software, and associated documentation files 
;(the "Product"), to deal in the Product without restriction, including without limitation the rights to use, copy, modify, merge, publish, 
;distribute, sublicense, and/or sell copies of the Product, and to permit persons to whom the Product is furnished to do so, subject to the 
;following conditions:
;
;The above copyright notice and this permission notice shall be included in all copies or substantial portions of the Product.
;
;THE PRODUCT IS PROVIDED "AS IS", WITHOUT WARRANTY OF ANY KIND, EXPRESS OR IMPLIED, INCLUDING BUT NOT LIMITED TO THE WARRANTIES OF 
;MERCHANTABILITY, FITNESS FOR A PARTICULAR PURPOSE AND NONINFRINGEMENT. IN NO EVENT SHALL THE AUTHORS OR COPYRIGHT HOLDERS BE LIABLE 
;FOR ANY CLAIM, DAMAGES OR OTHER LIABILITY, WHETHER IN AN ACTION OF CONTRACT, TORT OR OTHERWISE, ARISING FROM, OUT OF OR IN CONNECTION 
;WITH THE PRODUCT OR THE USE OR OTHER DEALINGS IN THE PRODUCT.
;#########################################################################################################################################################
; 12JAN2020 V0 PJS New 
; 09Mar2020 V1 PJS power draw too high swap over to alternate Logo LED patterns	
; 28Mar2021 V2 PJS swapped the oLED init and EEPROM check so we can selfcheck oLED with blank EEPROMs
; 25Jun2021 V3 PJS split the oled init and eeprom check so can init oled before led self test
; 14Mar2022 V4 PJS added code to disable the SPI corrupt led blink when RA0 is shorted to ground (pins 2 and 3 on pickit connector) This resolves the SPI programming corruption I was seeing programing on board. 
; 29Mar2022 V5 PJS changed code to allow llamas/founders to rez badges as well as necrollamacons 
	
	; use all language settings.... 4 space per indent, tab size 4, right margine 80, no expand spaces

	
#define	CODE_VER_STRING "Peter Shabino 29Mar2022 code for tymkrs Cyphercon 2020 badge V5 www.wire2wire.org!" ;Just in ROM !!! update vars below with true level!!
ver		equ	0x00

; enable debug code TODO comment out all before final build
;#define debug
;#define proto
;#define SKIP_EEPROM_TEST
		
; NOTES
; SAF is high endurance flash (128 words) at the end of flash. Not usable as program space when enabled in config words 
; http://ww1.microchip.com/downloads/en/DeviceDoc/PIC16(L)F15354_55%20Data%20Sheet%2040001853C.pdf	

;****************************************************************************************
; port list [SOIC20]
; Vss(20)
; Vdd(1)
; RA0(19)	[ICSPDAT]
; RA1(18)	[ISPCLK]
; RA2(17)	Board ID 0	
; RA3(4)	[MCLR]		button in
; RA4(3)	Board ID 1
; RA5(2)	Board ID 2
; RB4(13)	SCL
; RB5(12)	SDA
; RB6(11)	IR_IN
; RB7(10)	IR_OUT
; RC0(16)	MISO
; RC1(15)	MOSI
; RC2(14)	Sclk
; RC3(7)	oLED_Reset
; RC4(6)	oLED_DC
; RC5(5)	EEPROM_CS
; RC6(8)	oLED_CS
; RC7(9)	Post_CON
;****************************************************************************************


; PIC16F15345 Configuration Bit Settings 
#include "p16f15345.inc"
; CONFIG1
; __config 0xFF8C
 __CONFIG _CONFIG1, _FEXTOSC_OFF & _RSTOSC_HFINT32 & _CLKOUTEN_OFF & _CSWEN_ON & _FCMEN_ON
; CONFIG2
; __config 0xF7DC
; __CONFIG _CONFIG2, _MCLRE_OFF & _PWRTE_ON & _LPBOREN_ON & _BOREN_ON & _BORV_LO & _ZCD_OFF & _PPS1WAY_OFF & _STVREN_ON
 __CONFIG _CONFIG2, _MCLRE_OFF & _PWRTE_OFF & _LPBOREN_ON & _BOREN_ON & _BORV_LO & _ZCD_OFF & _PPS1WAY_OFF & _STVREN_ON
; CONFIG3
; __config 0xFF9F
 __CONFIG _CONFIG3, _WDTCPS_WDTCPS_31 & _WDTE_OFF & _WDTCWS_WDTCWS_7 & _WDTCCS_SC
; CONFIG4
; __config 0xDFEF
 __CONFIG _CONFIG4, _BBSIZE_BB512 & _BBEN_OFF & _SAFEN_ON & _WRTAPP_OFF & _WRTB_OFF & _WRTC_OFF & _WRTSAF_OFF & _LVP_OFF
; CONFIG5
; __config 0xFFFE
#ifdef debug
 __CONFIG _CONFIG5, _CP_OFF
#else
 __CONFIG _CONFIG5, _CP_ON
#endif 
 errorlevel 0	   ; all messages
 errorlevel -302    ; Hide the useless bank switch warnings as every non bank 0 register will generate one even if you use banksel or movlb properly beofore it or not. 
 
 
;------------------
; constants
;------------------	
IR_PULSE_WIDTH	equ 0x15		; pulse width set to 10% (0x69 = 50%, 0x35 = 25%, 0x15 = 10%, 0x0A = 5%)
; Default USER ID to load (2 bytes)
UserID  code 0x8000
    dw 0x0000

; key storage 
start_key	equ 0x9F70	; address of logical (INDF) flash start (note flash address + 0x8000)    
    org 0x1F70 ; 32 bytes to store counters and flags
	de 0x01,0x02,0x03,0x04,0x05,0xF0,0xE0,0xD0, 0xC0,0xA0,0xFF,0xFF,0xFF,0xFF,0xFF,0xFF
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

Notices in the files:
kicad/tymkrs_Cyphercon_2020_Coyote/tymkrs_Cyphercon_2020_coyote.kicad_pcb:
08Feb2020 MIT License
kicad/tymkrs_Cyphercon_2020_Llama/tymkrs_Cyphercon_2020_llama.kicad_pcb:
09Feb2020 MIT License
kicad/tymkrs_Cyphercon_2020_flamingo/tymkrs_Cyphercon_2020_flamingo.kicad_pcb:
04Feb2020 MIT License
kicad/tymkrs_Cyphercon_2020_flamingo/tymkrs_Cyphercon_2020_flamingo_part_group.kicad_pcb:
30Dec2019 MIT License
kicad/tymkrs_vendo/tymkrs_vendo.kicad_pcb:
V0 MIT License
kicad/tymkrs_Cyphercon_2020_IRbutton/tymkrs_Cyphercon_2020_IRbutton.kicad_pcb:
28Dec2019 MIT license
